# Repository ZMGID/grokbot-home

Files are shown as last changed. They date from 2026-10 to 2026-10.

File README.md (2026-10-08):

# grokbot-home

我的 Grok Bot「家」：换到新的 Grok Bot 账号时，让新号上的 bot 按这个仓库把自己和其他所有 bot 一起配好，做到基本无缝切换。

## 怎么用

仓库是**公开**的（2026-10-08 起），新号上的 bot 不用登录 GitHub 就能匿名克隆、读 `BOOTSTRAP.md`。Composio API key 只以**加密**形式放在 `secrets/*.enc`，解密口令只有我知道（应用连接只走 `composio-pg`，不装官方 GitHub/Origin 等连接器）。

在新号上打开任意一个 Grok Bot（一般是默认的主 bot），对它说：

```text
按这个仓库配置自己：https://github.com/ZMGID/grokbot-home
```

它会读 [`BOOTSTRAP.md`](BOOTSTRAP.md)，然后依次：

1. （Step 0）匿名克隆本仓库 → 用密码框（secret-request）向我要口令 `GROKBOT_HOME_PASSPHRASE` → 解密 `secrets/COMPOSIO_API_KEY.enc` 到 `~/.composio_pg_key`（连不上就换 `.box-current.enc`）→ 从 `connectors/composio-pg/` 装好并添加 composio-pg；
2. （Step 1）用 Composio 里 GitHub（ZMGID）的 token 登录 `gh`——只有往仓库推送（写回、每日同步）才需要；
3. 跑 `setup.sh` 装好工具环境（KiCad、PlatformIO、cadquery、Composio SDK 等）；
4. 确认 `composio-pg` 已接通；pstack 插件可选（原为 dr eggbot 安装）；导入 `skills/` 里的技能（若有）；
5. 按 `bots/grok-bot/` 设置自己为 **小萌**（主 bot；原名 Grok Bot）并读 `CONTEXT.md`；
6. 用 CreateAgent 把 `bots/` 下其他每个 bot（小枳、仓库管家、代码工程师、搭建运维、事务秘书、硬件工程师……，以 `bots/index.json` 为准）重新建出来，并重建它们的定时任务；
7. 自检，最后把新学到的东西写回仓库。

我需要亲自做的只有：在密码框里填一次仓库口令（解密失败时才要 Composio key 本身；`gh` 设备码只在推送权限拿不到时备用）。

## 目录

| 路径 | 内容 |
|---|---|
| `BOOTSTRAP.md` | 写给新 bot 的开机步骤（英文为主，附中文） |
| `CONTEXT.md` | 关于我的共享记忆：习惯、账号、项目进度、换号决定 |
| `bots/<名字>/` | 每个 bot 一个文件夹：`profile.md`（设定）、`CONTEXT.md`（它自己的记忆）、`routines.md`（定时任务） |
| `connectors/` | 连接器清单 + `composio-pg` 启动脚本（不含密钥） |
| `skills/` | 我自己创建的技能（目前没有） |
| `setup.sh` | 工具环境安装脚本（可重复运行） |
| `scripts/` | 每日同步任务说明和脚本、密钥扫描 `secret-scan.sh`、加解密 `secret-crypt.py` |
| `secrets/` | 只放加密后的密钥（`*.enc`），见 `secrets/README.md` |
| `projects/` | 项目文件（仿 TourBox 创作控制器） |

## 规矩

- **仓库是公开的，明文密钥永远不进仓库**。唯一例外是 `secrets/*.enc`：用 `scripts/secret-crypt.py` 加密后的 Composio key。口令只通过 bot 的密码框（secret prompt）给，绝不写进仓库或聊天。推送前必须 `bash scripts/secret-scan.sh` 通过。
- 每个号用完，新记住的东西写回对应的 `CONTEXT.md` 再推送。仓库管家每天凌晨 3:14（北京时间）自动同步一次。
- 仓库公开后，里面的共享记忆（`CONTEXT.md`、`bots/*/CONTEXT.md`、`bots/*/raw/memory/`）任何人都能看到；不要再写进不想公开的内容。不做 export-bot-template 分享模板。

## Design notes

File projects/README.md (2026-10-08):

# projects/

## creative-controller/ — 仿 TourBox 创作控制器（ESP32-S3）

从旧号 `/workspace/creative-controller/` 原样复制（2026-10-08），项目说明见 `creative-controller/README.md`、`docs/`。

包含：KiCad 9 工程和生成脚本（`pcb/`，含嘉立创生产文件 `pcb/fab/`）、cadquery 外壳模型与 STEP/STL（`mechanical/`）、可直接切片的 STL/3MF（`print/`）、
固件源码和编译好的合并固件 `firmware/bin/creativedial-esp32s3-merged.bin`（约 1 MB）、电脑端配置软件（`software/`）、文档（审查报告、3D 打印说明）。

**排除**（构建缓存，可重新生成）：
- `firmware/.pio/`（约 70 MB，PlatformIO 构建缓存；`cd firmware && pio run` 重新生成）
- 所有 `__pycache__/`

**没有超过 50 MB 的单个文件**，所以没用 Git LFS，也没有跳过任何文件。最大的是 `mechanical/out/assembly.step`（约 10 MB）和 `top_shell.step`（约 6 MB）。

**未放进仓库**：旧号的 `/workspace/creative-controller-delivery.zip`（约 15 MB），它是同一批文件的打包版，需要时可从本目录重新打包：
`cd projects && zip -r creative-controller-delivery.zip creative-controller -x '*/.pio/*' '*/__pycache__/*'`

依赖工具（`setup.sh` 会装）：KiCad 9（kicad-cli）、Freerouting（`/workspace/freerouting.jar`）、cadquery 2.8、PlatformIO（espressif32@6.9.0）、PrusaSlicer、Python 3。

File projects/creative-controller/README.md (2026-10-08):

# CreativeDial delivery package (Rev A1, 2026-10-08)
中文完整说明见 docs/README.md；设计审查报告（问题清单、修复、料号核验表、上电调试清单）见 **docs/审查报告.md**。

- Mechanical: mechanical/ (print-ready STL in print/)
- PCB (KiCad 9): pcb/ — regenerate with `cd pcb && ./route.sh && ./export.sh`; JLCPCB outputs in pcb/fab/
  (gerbers zip, BOM_JLCPCB.csv, CPL_JLCPCB.csv, BOM_detailed.csv with LCSC stock/price/Basic-Extended/links, ERC/DRC reports)
- Firmware: firmware/ (PlatformIO, Arduino-ESP32); prebuilt merged image firmware/bin/creativedial-esp32s3-merged.bin @0x0.
  Hardware self-test: hold TOP key while plugging in USB (or send `{"cmd":"selftest","on":true}`), watch serial at 115200.
- Config app: software/

Status: ERC 0 errors / DRC 0 errors (silkscreen warnings only), firmware builds cleanly. Not yet prototyped — see docs/审查报告.md §6 for remaining risks
(ENC2 mouse-encoder footprint is a placeholder; confirm CPL rotations in JLC preview; battery must have its own protection PCM).

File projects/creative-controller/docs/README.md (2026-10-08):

# CreativeDial 创意软件控制器 — 设计交付包 (Rev A, 原型阶段)

> 一款对标 TourBox 功能的**原创**桌面控制器：外形、布局细节、名称均为自主设计，未使用 TourBox 的外观/商标。
> 本包是 **"可以开始打样" 的工程原型包**，不是已经过验证的量产包。请务必阅读第 9 节"尚需实物验证的事项"。

## 1. 概述
| 项目 | 规格 |
|---|---|
| 外形 | 约 95 × 94 × 30 mm（含旋钮约 40 mm）。超椭圆(squircle n=4.2) 轮廓，四边带内凹"腰线"(前 5 / 后 2.5 / 左右 3 mm)；顶面 R300 球面拱，最高点偏后(y=+20)，前沿约 22.6 mm、后沿约 28.8 mm，形成后高前低的掌托斜面；R7 枕形上沿 + R5 底边，侧面呈柔和鼓包。键帽凸出 2.2 mm 带 R40 凹形指窝，旋钮滚花 + 嵌入式装饰环，滚轮约凸出 6 mm。粉色 PC/ABS |
| 主控 | **乐鑫 ESP32-S3-WROOM-1-N16R8**（LCSC C2913202） |
| 连接 | USB-C 有线（原生 USB HID 键盘 + 多媒体 + CDC 串口配置） + 蓝牙 BLE HID 无线 |
| 电池 | 3.7 V LiPo 603450 1000 mAh，MCP73831 充电 300 mA，P-MOS 电源路径(负载共享)，滑动电源开关，USB 插入检测；**电芯须自带保护板** |
| 输入 | 7 个面板按键(8 个轻触开关，长键用 2 个并联)、旋钮(EC11 带按压)、滚轮(鼠标编码器 + 按压)、共 9 路按键 + 2 路编码器 |
| 指示 | WS2812B RGB 状态灯(经 SN74LV1T34 电平转换) + 导光柱（充电=橙，充满=绿，BLE 已连=蓝，仅 USB=暗青，低电=灭） |
| 功能(默认 Photoshop 配置) | 橡皮擦、旋转画布、智能笔刷大小、不透明度、缩放画布、适合屏幕、撤销/重做、吸管、工具轮盘、移动画布(按住空格)、新建图层、画笔、单击/双击/长按、按住键+旋钮组合 |

**MCU 选型理由**：ESP32-S3 同时具备原生 USB-OTG (TinyUSB HID) 和 BLE 5，一颗模组实现有线+无线，模组自带天线/晶振/Flash 并已有 SRRC/CE/FCC 认证，可省去射频认证中最贵的部分。
RP2040 便宜约 2 美元但无无线；若只做有线版，可把 U1 换成 RP2040 方案（固件需移植，本包未提供）。

## 1.1 人体工学设计说明（左手操作）
| 控件 | 位置 (mm, 中心为原点) | 对应手指 / 理由 |
|---|---|---|
| 侧键(圆角豆形 18×13) | (-34,-20) 左下 | 左手自然放置时**拇指**落点；用于撤销/修饰键组合，最高频操作不需移动手掌 |
| 滚轮 Ø24 | (-38, 6) 左侧竖向 | **食指**向左外侧轻拨，与鼠标滚轮动作一致（缩放画布） |
| 顶部胶囊长键 34×13 | (-6, 31) | **食指/中指**向前伸即可按到；胶囊形对指腹宽度容错大（橡皮擦/平移） |
| 旋钮 Ø32 + Ø40 凹环 | (0, 2) 中央 | 位于食指-中指下方，手掌搭在前沿时可用两指捏转（笔刷大小/旋转画布），凹环防误触外壳 |
| 右上小圆键 ×2 Ø11 | (22,36) (38,25) | 中指/无名指上抬触达，用于不常用的吸管/画笔 |
| 右侧圆键 Ø11 | (36,-5) | 无名指（适合屏幕/新建图层） |
| 右下长键 12×22 / 12×18 | (18,-26) (36,-25) | **无名指/小指**下压，长条形适合"按住"类操作（按住空格平移、按住 Alt） |

- 所有按键中心距 ≥ 18 mm（最小值 18.0 mm：右下两长键；19.4 mm：右上两圆键），戴手套或指甲较长也不易误触。
- 后高前低约 6 mm 坡度 + 前沿内凹腰线：手掌根部可以搭在前沿，手腕伸展角更小。
- 键帽顶面为 R40 浅凹指窝、所有棱边 R1.2 倒圆；按键力 160 gf(TS-1102S)，行程约 0.3 mm 空行程 + 0.25 mm 开关行程（偏短，见第 9 节）。
- 底部 4 个 Ø10×0.8 mm 硅胶脚垫槽，防滑。
- 布局为原创：控件数量/功能与参考产品相当，但轮廓、按键形状和坐标均为独立设计。

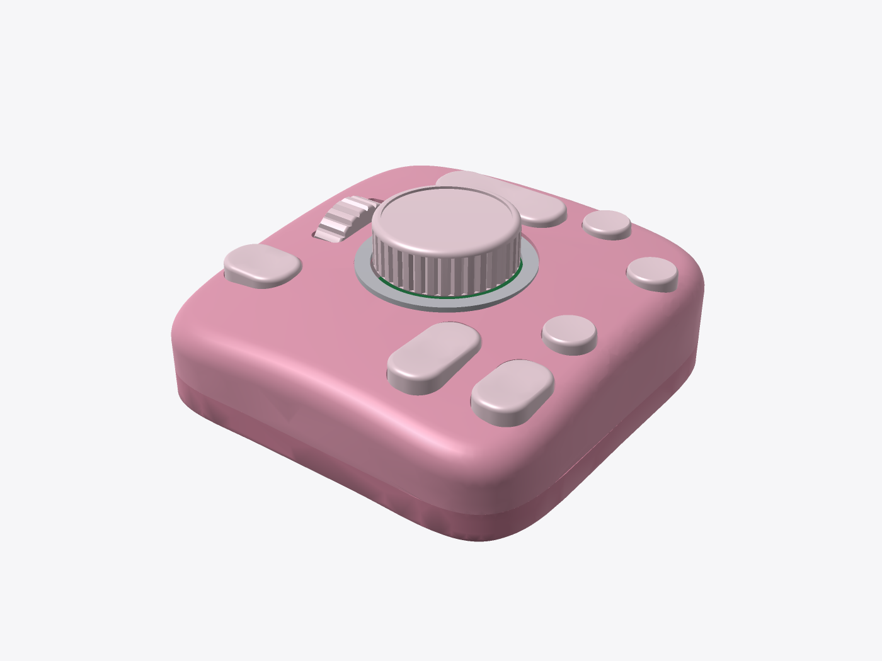
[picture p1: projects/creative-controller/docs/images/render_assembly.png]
总装渲染

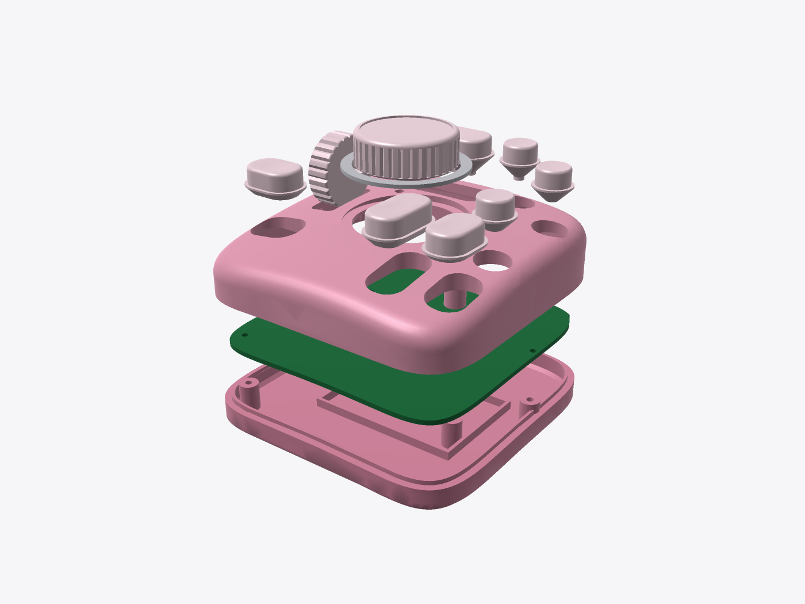
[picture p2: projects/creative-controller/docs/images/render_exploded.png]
爆炸图


## 2. 目录结构
```
mechanical/   CadQuery 参数化源码(params.py, cad.py, print_export.py)、out/*.step *.stl(装配姿态)、drawings/ 渲染与尺寸图
print/        FDM 打印就绪 STL(已按打印床摆放)、3MF 拼版、公差测试件、overhang_report.json
pcb/          KiCad 工程(.kicad_pro/.kicad_sch/.kicad_pcb)、生成脚本、fab/ 生产文件(Gerber zip、BOM、CPL、原理图 PDF、ERC/DRC 报告)
firmware/     PlatformIO 工程(Arduino-ESP32)、bin/ 已编译固件
software/     跨平台配置工具 creativedial_config.py (Python + Tkinter + pyserial)
docs/         本文档、3D打印说明.md、images/ 渲染图
```

## 3. BOM 与成本估算
详细见 `pcb/fab/BOM_detailed.csv`（含 LCSC 号、JLC 库存、Basic/Extended、单价、链接；JLC 上传格式为 `BOM_JLCPCB.csv`）。数据为 2026-10-08 由 JLC 元件库接口实时查询，核验表与说明见 **[审查报告.md](审查报告.md)**；下单前请再确认库存。

| 类别 | 主要器件 | 单台估算 |
|---|---|---|
| 电子元件 | ESP32-S3 模组 $5.1、EC11E $2.4、PCM12 $1.8、MCP73831、AP2112K、USBLC6、SN74LV1T34、USB-C、9+2 轻触开关、阻容（1+ 单价） | ≈ $12.3（100 台档约 $9） |
| PCB + SMT (JLC, 100 片) | 2 层 1.6 mm 93×93；SMT 单面；扩展件费每种 $3 一次性 | ≈ $2.5–4 |
| 鼠标编码器 + 微动、电池 603450 1000 mAh | 淘宝/1688 | ≈ $2.5 |
| 外壳 + 键帽 + 旋钮 + 滚轮 | 3D 打印(树脂) ¥40–70/套；注塑 ¥4–8/套 | 打样 ≈ $8 / 量产 ≈ $1 |
| 螺丝、脚垫、导光柱、包装 | | ≈ $0.8 |
| **合计** | | **打样(5–10 台) ≈ ¥200–300/台；量产(1k 台) ≈ ¥90–120/台(不含模具)** |
| 一次性费用 | 注塑模具(上下壳 + 键帽家族模 + 旋钮/滚轮) | ¥40k–90k，视模具钢和腔数 |
| 认证 | 使用已认证模组仍需整机 FCC/CE(SDoC/RED)、电池 UN38.3/MSDS | ¥15k–40k |

## 4. 生产步骤

### 4.1 PCB (嘉立创 JLCPCB)
1. 上传 `pcb/fab/creative-controller-gerbers-JLCPCB.zip`：2 层、1.6 mm、FR-4、1 oz、HASL 无铅或沉金；最小孔 0.3 mm、最小线宽/间距 0.127 mm，均为 JLC 标准工艺。
2. 勾选 SMT 贴片(顶面)，上传 `BOM_JLCPCB.csv` 与 `CPL_JLCPCB.csv`。
3. **在 JLC 贴片预览中逐个检查器件方向**：CPL 已对 SOT-23 系列、USB-C、JST 加 180° 修正，仍须按 审查报告.md §2.1 的清单逐个确认（尤其 ESP32 模组天线朝前沿）。
4. EC11 编码器(ENC1)、鼠标编码器(ENC2) 为插件，不在 CPL 中，到货后手焊（或额外勾选 JLC THT 服务）。
5. 电池接口 J2 为 JST PH 2.0，注意电池线序：**1 = +，2 = −**（不同电池厂线序不同，接错会烧充电芯片）。

### 4.2 外壳
- **FDM 自行打印（推荐打样）**：直接用 `print/` 下已摆好方向的 STL 或 `print/plate*.3mf`(仓库根目录 print/)，0.4 mm 喷嘴、PETG/PLA，详见 **[3D打印说明.md](3D打印说明.md)**（先打公差测试件！）。
- 外发打样：`mechanical/out/*.stl` 发 JLC3DP / 未来工场，9000R 树脂或 PA12(MJF) 也可用（树脂件热熔螺母孔需改为 Ø3.0 或用胶固定）。
- 量产：把 `*.step` 发模具厂做 DFM，按 `mechanical/README_mechanical.md` 加拔模角、优化螺柱壁厚、确定咬花/喷涂。

## 5. 组装指南
1. 检查 PCB：目检 + 万用表测 VBUS/VSYS/3V3/VBAT 对地不短路。
2. 手焊 ENC1 (EC11E, 20 mm D 轴) 和 ENC2 (鼠标编码器)；滚轮按压开关 SW9 位于滚轮下方。
3. 插 USB-C，不接电池，检查 3V3 = 3.3 V ± 3%，烧录固件（见第 6 节），然后按住 TOP 键上电进入**自检模式**逐键检查（完整清单见 审查报告.md §5）。
4. 上壳 4 个螺柱用烙铁压入 **M2×4×OD3.5 热熔铜螺母**（孔 Ø3.2×5，步骤见 3D打印说明.md）。
5. 将 7 个键帽从上壳**内侧**插入导向套（法兰朝内）；导光柱从内侧插入 LED 孔；拨动开关延长块套到 SW12 拨杆上。
6. 滚轮：方轴端插入鼠标编码器 ENC2 的方孔，另一端 Ø3×14 销轴落入上壳一体的滚轮支架 U 形槽（槽有 0.9 mm 下压行程，按下滚轮压 SW9）。
7. 把 PCB 扣入上壳（USB/开关舌片对准后壁开口，螺孔对准 H1–H4），电池用双面胶贴在下壳电池仓内，插 J2。
8. 合上下壳，4 颗 **M2×14 内六角(DIN912)** 从底部沉孔锁入热熔螺母（≤0.2 N·m）；贴 4 个 Ø10×0.8 硅胶脚垫。
9. 压上旋钮（打印 D 孔 Ø6.2/平面 4.7，带开口弹性槽，0.25 mm 间隙方案）及装饰环。

## 6. 固件与烧录
- 已编译固件：`firmware/bin/creativedial-esp32s3-merged.bin`（合并镜像，从 0x0 烧录）以及分立的 bootloader/partitions/app。
- 方法 A（推荐，无需环境）：
  ```
  pip install esptool
  # 按住 BOOT(SW11) 再按一下 RESET(SW10) 进入下载模式，插 USB-C
  esptool.py --chip esp32s3 --port COMx write_flash 0x0 creativedial-esp32s3-merged.bin
  ```
  也可用乐鑫 Flash Download Tool（Windows 图形界面），地址 0x0。
- 方法 B（源码编译）：`pip install platformio && cd firmware && pio run -t upload`
- 固件功能：9 路按键去抖(5 ms)、单击/双击(250 ms)/长按(450 ms)、`hold:` 按住型动作(如按住空格移动画布)、
  旋钮/滚轮中断正交解码、"按住某键 + 旋转" 组合、USB HID 键盘 + Consumer、BLE HID 键盘(设备名 CreativeDial)、
  JSON 配置存 NVS（掉电保存）、电池电压(16 次平均)/USB/充电状态查询、BLE 电量上报、电池供电无操作 10 分钟深度睡眠(任意键唤醒)、3.30 V 低压保护、
  **硬件自检模式**（按住 TOP 键上电或 `{"cmd":"selftest","on":true}`：不发 HID，串口打印每个按键/编码器事件和电源状态，LED 红绿蓝白测试）。
  USB 已连接时默认不再发 BLE 键（防重复），配置 `"ble_when_usb":true` 可开启；`"sleep_min"`、`"knob_steps"`、`"wheel_steps"` 可配置。
- 串口协议(115200, 每行一个 JSON)：`{"cmd":"hello"}`、`{"cmd":"get"}`、`{"cmd":"set","config":{"name":..,"map":{"top.single":"e",...}}}`、`{"cmd":"reset"}`、`{"cmd":"battery"}`、`{"cmd":"selftest","on":true|false}`、`{"cmd":"sleep"}`。

## 7. 配置软件
```
pip install pyserial          # Python 3.9+；Linux 另需 python3-tk
python software/creativedial_config.py              # 图形界面
python software/creativedial_config.py --push Krita # 命令行写入
python software/creativedial_config.py --selftest
```
内置 Photoshop / Clip Studio Paint / Krita / Procreate 类(iPad 蓝牙键盘快捷键) 4 套预设，可编辑并保存到 `~/.creativedial_profiles.json`。
动作语法：`ctrl+z`、`ctrl+shift+z`、`[`、`space`、`f5`、`hold:space`、`consumer:volup`；macOS 用 `cmd`。
**注意**：目前切换软件时需手动选择预设并"写入设备"；根据前台窗口自动切换尚未实现。

## 8. 测试检查表 (每台)
- [ ] 外观：无缩痕/毛刺，键帽无卡滞，旋钮无偏摆
- [ ] 上电：USB 插入 3V3 正常，电脑识别为 "CreativeDial" HID 键盘 + 串口
- [ ] `{"cmd":"hello"}` 返回固件版本
- [ ] 9 个按键逐一单击/双击/长按，配置工具或记事本中出现对应按键
- [ ] 旋钮顺/逆各转 1 圈 = 36 次(EC11E18244A5，36 止动)，无丢步/反向；滚轮同理
- [ ] 组合：按住侧键 + 旋钮 → R / Shift+R
- [ ] 蓝牙：手机/iPad/电脑可配对，断开后自动重新广播
- [ ] 充电：接电池 + USB，状态灯橙；`battery` 命令 mV 合理、charging=true；充满后灯绿、full=true
- [ ] 拔 USB，拨开关可由电池供电；开关 OFF 时电池电流 ≈0；深睡电流约 1 mA（WS2812B 静态电流，见审查报告 R3）
- [ ] 跌落 0.8 m ×6 面、按键寿命抽检 (TS-1102S 6×6×5.5 标称 10 万次)

## 9. 诚实说明：已验证 / 未验证
### 已在软件中验证
- CadQuery 模型可完整生成，STEP/STL 导出无误，渲染见 `docs/images/`（自写 numpy z-buffer 光栅渲染器，平滑着色，非照片级）。
- 原理图 ERC：0 错误 0 警告（`pcb/erc.rpt`）。
- PCB 由 Freerouting **自动布线**（Power 0.4 mm / VBUS 0.35 mm 网络类、两面 GND 铺铜 + 184 个缝合过孔、JLC 规则），100% 连通；DRC：0 错误，仅丝印类警告（`pcb/drc.rpt`），原理图-PCB 一致性检查通过。
- 2026-10-08 设计审查：修复 STAT 5 V 灌 GPIO、WS2812B 电平、0.2 mm 过孔等问题，全部料号经 JLC 接口核验，详见 **[审查报告.md](审查报告.md)**。
- 固件 PlatformIO 编译通过（ESP32-S3, Arduino-ESP32 2.x / platform espressif32 6.9.0）。
- 配置软件自检通过、图形界面在 Linux(Xvfb) 下可启动。
- 全部 26 个 LCSC 料号已通过 JLC 元件库接口核验存在、有货、封装匹配（ENC2 鼠标编码器除外，不在 LCSC）。

### 尚需实物打样/工程师复核（重要）
1. **PCB 为自动布线**：功能连通但未做人工美化；USB D+/D- 在 2 层 1.6 mm 板上无法做 90 Ω（需约 1.2 mm 线宽），按全速 USB 处理（见审查报告 P6）。
2. 原理图为脚本生成(每个引脚用网络标签连接)，可读性一般；电气已按规格书审查（审查报告 §1.1），电池需自带保护板。
3. WS2812B 数据电平问题已用 SN74LV1T34 修复；WS2812B-B/T(C2761795) JLC 库存 8 万+，未见停产标记。电池 <3.5 V 时 LED 低于规格，固件 3.45 V 以下关灯。
4. 滚轮机构已建模（上壳一体支架 + U 形槽 + Ø3 销轴 + 方轴插编码器），但"以编码器轴为支点下压"的方式依赖编码器能承受轻微摆动，需实测；ENC2 使用自建"通用鼠标编码器"封装，须按实际采购型号核对引脚和孔位/轴高。
5. 6×6×5.5 mm 轻触开关(CAX TS-1102S, C53431191，已核验，焊盘与 PTS645 封装一致；库存仅约 1000，批量需锁料)，键帽导向更稳但行程仍约 0.25 mm；更长行程需换 Kailh Choc 矮轴（需改 PCB 封装与键帽结构，本版未实现）。
   机械与 PCB 的高度配合(键帽柱长、编码器轴长、USB-C 开口高度、拨动开关槽)只按数据手册典型尺寸计算，**需首版打印实测**。
6. 注塑模型未加拔模角，螺柱/壁厚未做模流分析。
7. ESP32 天线区域：模组天线朝前沿，PCB 已做禁铜区，但电池、手部遮挡对 BLE 距离的影响需实测。
8. 固件未在真机运行：HID 报告、BLE 配对(iOS/Windows/macOS 兼容性)、深度睡眠唤醒均需实测（自检模式便于调试）。
9. JLC CPL 旋转角已按常用修正表处理，但须在 JLC 预览中确认；KiCad 工程为 **KiCad 9.0** 格式(本环境仅有 KiCad 9；KiCad 8 无法打开 9 的 PCB 文件，原理图使用 8 兼容格式)。
10. 主按键封装 SW_SPST_PTS645 已按 TS-1102S 规格书核对；RESET/BOOT 为 TL3342 封装 + TS-1187A(C318884)，焊盘已核对。
11. 料号价格随时变化；EC11E18244A5、ESP32-S3 模组属"扩展库"器件，JLC 每种收取换料费。

12. USB-C：PCB 加了伸出舌片使插座端面贴近内壁，后壁外侧做 13×7.5 mm 沉台、仅剩 0.8 mm 壁，端面距沉台面 ≤1 mm，常见粗头线应能插到底；需实物确认。
13. 电源拨动开关：后壁开 6.5×3.6 槽 + 11×6 指槽，并提供打印拨杆延长块 `pwr_slider_ext`（1.5×1.6 套孔），尺寸按开关典型规格书，需实测。
14. FDM 打印：外表面无 >45° 悬垂；上壳倒扣打印时内部穹顶天花板/导向套/螺柱需"仅支撑在打印床"或树状支撑（不可见面）。打印时间/耗材为 PrusaSlicer 2.x 通用 PETG 配置估算，未实打。

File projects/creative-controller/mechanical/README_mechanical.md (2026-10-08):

# 机械结构说明 (mechanical)

源文件: `params.py`(唯一尺寸来源，PCB 生成脚本也引用它) + `cad.py`(CadQuery) + `render.py`(渲染/尺寸图)。
重新生成: `pip install cadquery trimesh matplotlib && python3 cad.py && python3 render.py`

## 零件清单 (out/)
| 文件 | 零件 | 数量 | 推荐材料 |
|---|---|---|---|
| top_shell.step/.stl | 上壳 | 1 | PC/ABS (注塑) / 光敏树脂 或 PETG (打印) |
| bottom_shell.step/.stl | 下壳(含电池仓围框、4 个脚垫槽 Ø10) | 1 | 同上 |
| cap_top / cap_side / cap_tr1 / cap_tr2 / cap_br / cap_tall1 / cap_tall2 | 按键帽(带法兰防脱，从壳内侧装入) | 7 | ABS/PC, 打印可用树脂 |
| knob.step | 旋钮 Ø32×11，滚花，D 形孔(6 mm 轴, 4.5 mm 平面) | 1 | ABS + 可选铝套 |
| knob_ring.step | 装饰环 Ø40 | 1 | 透明 PC(可做导光) / 金属 |
| scroll_wheel.step | 滚轮 Ø24×8，2.05 mm 方孔接鼠标编码器轴 | 1 | ABS + TPU 包胶(量产) |
| light_pipe.step | 状态灯导光柱 Ø2.9 | 1 | 透明 PC/PMMA |
| assembly.step | 总装(含 PCB 占位) | - | - |

## 关键尺寸
- 外形约 95 × 94 × 30 mm（含旋钮 ≈ 40 mm），超椭圆轮廓 + 四边内凹腰线(params.WAIST)，顶面 R300 球面拱顶(顶点偏后 20 mm，前低后高)，上沿 R7 枕形过渡，底边 R3，壁厚 2.2 mm。
- 键帽顶面高出局部拱面 2.2 mm，顶面带 R40 浅凹指窝；法兰在壳内皮下 0.4 mm 作为行程止挡。
- 分模面 z = 8 mm；下壳 1.5 mm 高止口(单边 0.15 mm 间隙)插入上壳。
- PCB：外壳轮廓向内偏移 3.2 mm（与外壳同源 outline_pts），, 1.6 mm，底面位于 z = 13 mm，被上壳螺柱(压)和下壳螺柱(托)夹紧。
- 4 × M2×14 DIN912 内六角从下壳底部沉孔(Ø4.4×2.4, 通孔 Ø2.4) → PCB 孔(Ø2.2) → 上壳螺柱内 M2×4×OD3.5 热熔铜螺母(孔 Ø3.2×5, 螺柱 Ø6.6)。
- FDM 打印细节、方向、支撑见 ../docs/3D打印说明.md 与 ../print/；按键为 6×6×5.5 轻触(TS-1102S)，带导向套；USB 外侧沉台 13×7.5 剩 0.8 mm 壁；拨动开关槽 + 指槽 + 延长块；滚轮支架与上壳一体(U 形槽, Ø3×14 销)。
  位置 (-40,24) (-38,-34) (42,12) (28,-12)。上壳螺柱已裁切到内腔面，不会顶穿拱顶。
- 按键帽与壳孔单边间隙 0.25 mm（FDM 建议 0.3，注塑 0.10–0.15）；帽高出壳面 1.2 mm；
  帽柱底面与轻触开关(TS-1187A, 1.5 mm 高)之间预留 0.3 mm 空行程。
- USB-C 开口 10.0 × 4.0 mm 位于后壁中央；电源拨动开关槽 8 × 3 mm 位于后壁 x = 33。
- 电池仓 50.6 × 34.6 mm（603450 1000 mAh LiPo），围框高 3 mm。

## 3D 打印建议
- 光敏树脂(JLC3DP 9000R/8228)外观最好；FDM 用 0.2 mm 层高、PETG，上壳顶面朝下打印需支撑。
- 打印件的自攻底孔可能需要用 1.6 mm 钻头修孔；或改用热熔铜螺母(M2 OD3.2)，把 `cad.py` 中 pilot 改为 Ø3.2。

## 注塑量产注意 (需模具厂 DFM 评审)
- 当前模型 **未加拔模角**：外观面需 1–2°、内部筋/柱 0.5–1° 拔模；纹理面按咬花深度加大拔模。
- 螺柱根部壁厚偏厚(实心 Ø6.4)，量产建议改为 Ø5.5 外径 + 加强筋，并在柱根做掏胶，防缩痕。
- 按键帽建议改为 "整片硅胶/硬胶二次成型" 或带悬臂弹片的一体按键，减少零件数。
- 上壳顶面按键孔间距最小处约 3 mm，模具强度 OK；侧壁 USB/开关槽需要滑块(或改为下壳开槽)。
- 推荐 PC/ABS (如 Covestro Bayblend) 或 ABS + 喷涂/IMD 实现粉色哑光外观。

渲染: `python3 render_final.py`（raster.py 为纯 numpy 软件光栅器，无需 GPU）。

布尔运算使用模糊容差 + ShapeFix (fcut/funion)，因为样条轮廓与球面求交易产生公差问题；所有导出零件均通过 isValid 检查。

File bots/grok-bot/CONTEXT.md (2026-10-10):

# 小萌（grok-bot）自己的记忆与项目状态

> 先读根目录 `/CONTEXT.md`（关于用户的共享记忆），这里只记主 bot 自己的工作记录。导出：2026-10-08。

## 职责
- 账号主 bot / **经理**：接任何任务并分派给合适的 bot；用 CreateAgent 创建新 bot（dr eggbot 已于 2026-10-08 删除）；SetPrimaryBot。
- 换号时执行 BOOTSTRAP；仓库日常维护与每日 03:14 同步已于 2026-10-08 移交给**仓库管家**。

- (2026-10-08) 用户批准把 `/workspace/assistant/big-picture.md` 公开进仓库：`bots/grok-bot/notes/big-picture.md`。每日笔记 `/workspace/assistant/daily/` **不进仓库**；每日同步由仓库管家复制 big-picture（见 `scripts/sync.md`）。
- (2026-10-08) **改名**：显示名 `Grok Bot` → `小萌`（slug 仍为 `grok-bot`）。
- (2026-10-08) 定时任务「巡检各 bot」`17 11,15 * * 1-5`；早晚计划/总结**已移交给事务秘书**。
- (2026-10-09) 「巡检各 bot」改用纯 cron `17 11,15 * * 1-5`（用户时区 Asia/Hong_Kong）；小萌现仅保留此项定时任务。

## 关于用户（主 bot 视角的要点）
- 用中文交流，Grok Bot 账号多个、轮换使用，GitHub `ZMGID`。
- 2026-10-07 用户问订阅：建议先订 SuperGrok（$30/月，按月付），Grok Bot 从这一档开始提供；Plus（$100）主要多用量、1080p 视频、高峰优先。
- 用户会在语音通话里布置任务；通话结束后要在聊天里补发结果摘要。
- 用户发 `/new` 时：主 bot 不能替用户开新对话，告诉他用 app 里的新建入口，或直接换话题。

## 项目记录

### kivio PR #60 审查（2026-10-07）
- PR #60「feat: Kivio Study 材料学习工作台」：最新一轮 CI 和 Study browser regression 在 10-07 通过（`be06640` 修好了共用 Chat 重构引入的两处 bug：读历史时改写记录、打开页面就更新版本号导致其他窗口被误判过期）。没有冲突，可合并，没人 review。review 意见见根目录 CONTEXT.md。
- Dsivio main CI 一直失败：CI 用 Node 20，测试用 `Promise.withResolvers`（Node 22）。

### 仿 TourBox 创作控制器（2026-10-07 ~ 10-08）
- 用户发了一张 TourBox 类产品图，要求做全套（模型、PCB、软件）并给交付文件。主 bot 做了原创设计：
  1. 初版（100×100×30 mm）→ 用户要求按 **3D 打印** 重做并兼顾 **人体工学**（参考原图）→ 人体工学版（约 95×94 mm，左手布局，键距 ≥18 mm）→ 3D 打印版（17 零件、3MF 打印盘、热熔螺母、滚轮支架、公差测试件、中文打印说明）。
  2. 用户要求审查电路板和固件并在嘉立创核对元件 → 修了充电芯片状态脚 5V 直连 ESP32（加分压）、RGB 数据电平偏低（加电平转换），充电电流降到 303 mA，编码器加上拉和滤波，天线禁铺区加大，双面铺地；固件升到 **v1.1.0**（修蓝牙配对、USB 重复发键，加 10 分钟休眠和自检模式）。
- 当前文件：`projects/creative-controller/`（旧号 `/workspace/creative-controller/`，另有打包的 `creative-controller-delivery.zip` 约 15 MB，内容与目录相同，未放进仓库）。
- 剩余风险：ENC2 封装占位、板上无电池保护（用带保护板的 603450）、检查 CPL 旋转、TS-1102S 库存少、未经实物测试。
- 工具链：KiCad 9（kicad-cli）、Freerouting（`/workspace/freerouting.jar`，`pcb/route.sh`）、cadquery 2.8（`mechanical/cad.py`、`params.py`）、PlatformIO espressif32@6.9.0（`firmware/`）、PrusaSlicer（切片估时）。

### 换号方案（2026-10-08）
- 讨论过程：私有仓库 + CONTEXT.md → 工具环境用 setup.sh、密钥放 1Password → 用户希望“给新 bot 一个链接就自动适配” → 考虑过自建 MCP 网关（MetaMCP / mcp-proxy），后来选 Composio（免费 Hobby 版每月 10 万次调用，个人够用）。
- 官方 Composio 插件 OAuth 后看不到应用（不同 Composio user）；小枳用项目 API key 写了 `composio-pg` 启动器，主 bot 在 11:54 把 `composio-pg` 加到账号里并验证 GitHub（ZMGID）和 Gmail 都是 ACTIVE。
- (2026-10-09) 新增 **composio-zhimeng**（stdio，`/workspace/composio-zhimeng/launch.sh`）：Composio 用户 `zhimeng63`，仅 Gmail zhimeng63@gmail.com；与 composio-pg 共用 `~/.composio_pg_key`。composio-pg 此后只管 GitHub + ohulercxm8。
- 用户决定：每个 bot 都存进仓库，新号的第一个 bot 配好自己后用 CreateAgent 重建其他 bot。
- 2026-10-08 12:02 开始建 `ZMGID/grokbot-home`。
- (2026-10-08) 用户改口：单独建同步 bot **仓库管家**，仓库维护与每日同步从主 bot 移交给它；grok-bot 不再跑 daily-grokbot-sync。

## 账号上的其他 bot（供分派参考，2026-10-08）
- **小枳**（xiaozhi）：中文通用助手，调研/查资料/方案。
- **仓库管家**：维护本仓库、跑每日 03:14 同步。
- **代码工程师**：Dsivio / kivio 的 CI、PR 与代码修复。
- **搭建运维**：公司官网、飞书及其他搭建维护。
- **事务秘书**（原名「邮件秘书」）：非技术事务 + 工作日早晚计划/总结；只写草稿，从不直接发送。
- **硬件工程师**：创作控制器（`projects/creative-controller/`）。
- **财务管家**：记账/订阅/预算/报销对账（只记录不付款）；账本 `/workspace/finance/` 不进仓库。
- **dr eggbot**：已于 2026-10-08 删除；新建 bot 改由本 bot（小萌）负责。
- 另有一个空的 “New Bot”（id `1dbfda76-…`，2026-08 创建，无对话、无设定），不是真正在用的 bot，没有迁移。
- (2026-10-10) 又出现第二个空白 “New Bot”（id `52d1b935-…`，10-10 03:09 创建，只发了一句自我介绍，无设定），同样暂不登记，等用户或小萌确认用途。

## 2026-10-08 晚 ~ 10-09
- (2026-10-08) Dsivio v1.1.0 发布；官网产品页上线；环境配置 PR #2/#3/#4 开出未合；用户次日重点：手工优化环境配置 + 启动 IM Gateway（参考 Hermes）。
- (2026-10-08) 派小枳做 Hermes IM 网关调研；用户 10/9 凌晨决定自写 Rust 协议实现。

## 2026-10-09 午后 ~ 10-10 凌晨
- (2026-10-09) 帮用户查了 Codex CLI 0.160–0.162 更新、GPT-6.1 Sol 与 Claude Opus 5.5 API 价格对比、AI 操作 Word/Excel 的开源项目（首推 OfficeCLI，备选 officekit）。
- (2026-10-10) 应用户要求做了恶搞网页小游戏《刹不住的境界》（虚构车名/厂名），用户最终选第一版；已挂到新的公开仓库 **ZMGID/brake-game**（GitHub Pages：https://zmgid.github.io/brake-game/），只记一笔、不同步进本仓库。素材整理在 box 的 `/workspace/brake-game/`。
- (2026-10-10) 领取 Grok Bot 邮箱 `cloudpotato@mail.grokbot.com`（绑当前账号、不可转移，见根目录 CONTEXT「Grok Bot 自带邮箱」），并新建自动任务「cloudpotato 来信提醒」。
- (2026-10-10) 用户想在 Composio 里再接其他邮箱：规矩是每个邮箱单独建一个 Composio 连接器（同 composio-zhimeng 模式），等用户给地址。

- (2026-10-10) 新增例程：**cloudpotato 来信提醒**（email 触发）与 **gmail-new-mail**（webhook；触发器 ti_ePC_aV3eRSPT / ti_6ozhOAfOaHLq；密钥 env `GMAIL_WEBHOOK_KEY` 不进仓库）。盒子 `/workspace/gmail-listener/start.sh`，重启后需手动启动。
- (2026-10-10) 飞书走官方 **lark-cli**（Composio 无飞书例外）；群 id 见 `services/feishu-cli/chats.md`。

## 2026-10-10 晚
- (2026-10-10) 帮用户看了 Monid（统一付费的工具/数据接口平台），结论：可借鉴思路，不必自建；记入 `/workspace/assistant/ideas/monid-unified-api.md`，等 Dsivio 环境配置忙完再拿出来商量。
- (2026-10-10) 接下用户三条主线（kivio bot 模式 + 版本检查、kivio Rust SDK 标准、Dsivio 运营插件），小萌要先摸清 kivio / Dsivio 代码结构再出拆解和计划；插件线建议让事务秘书问运营同事日常，或用户直接口述。
- (2026-10-11) 两个空白 “New Bot”（`1dbfda76-…`、`52d1b935-…`）已不在本账号的 agent 目录中（应已删除，从未登记，无需清理）。又出现一个默认设定的空白 “Grok Bot”（id `04d9635a-…`，10-10 17:22 创建，只有自我介绍和一问一答，无分工），同样暂不登记，等用户或小萌确认用途。

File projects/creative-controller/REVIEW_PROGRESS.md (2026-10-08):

# Review progress (auto notes)
## Done (as of 02:00)
- design.py: +U5 SN74LV1T34DBVR level shifter (LED_IO GPIO48 -> LED_DIN @VSYS), C10; MCP73831 STAT (pushes 5V!) now via 15k/22k divider (R7/R10) to GPIO2;
  VBUS_SENSE 22k/39k (R11/R12) -> GPIO13 (module pin 21); ENC pullups 10k + 10nF (R13-16, C11-14); C15 22uF 0805 on 3V3.
- gen_pcb.py: antenna keepout widened to x±20 (all Cu), module EP vias 0.2->0.3 drill (JLC 2L min), small silk refs 0.8mm.
- tools/patch_pro.py: JLC rules + netclasses Power/USB (run after every SaveBoard). import_route.py: GND pours + stitching vias (168).
- tools/jlc_lookup.py: JLC parts API lookup. All original 20 LCSC codes verified in stock (see make_bom_cpl output / fab/jlc_parts.json).
- make_bom_cpl.py rewritten (live JLC data, BOM_detailed.csv, CPL rotation corrections).
- firmware main.cpp: v1.1.0 VBUS sense, charge logic, battery avg/pct, BLE security order, robust encoder ISR (rest-state), deep sleep ext1, self-test mode. Builds OK.
## Remaining
- Reroute: last freerouting run (-mp 60) left VBUS (USB-C pads) and VBAT (J2) unrouted and froze the box -> rerun with -Xmx3g, power width 0.4/VBUS 0.35.
- DRC 0 errors, export.sh, BOM/CPL, docs/审查报告.md, README, bins, zip.
- 02:06 reroute OK: 0 unconnected, DRC 14 (check)
- 02:15 R6->3.3k (303mA), BOM regrouped, fw low-batt cutoff + USB/BLE dedupe, bins rebuilt. DRC 0 err. Next: docs
- 02:2x exports regenerated; writing docs/审查报告.md
- docs/审查报告.md written
- README/docs updated; next: zip
- 02:2x zip rebuilt. ALL DONE

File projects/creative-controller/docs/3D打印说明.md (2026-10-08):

# 3D 打印说明（FDM，0.4 mm 喷嘴，PETG / PLA）

所有打印文件位于仓库根目录 `print/`，**已按推荐方向摆放在打印床上（Z=0 即床面）**，直接导入切片软件即可，无需旋转。
源码：`mechanical/print_export.py`（由 `mechanical/cad.py` 生成的零件重新定向、修复网格、做悬垂检查、生成 3MF）。

| 文件 | 说明 |
|---|---|
| `plate0_tolerance_test.3mf` | 公差测试拼版（**第一个打印**） |
| `plate1_shells.3mf` | 上壳 + 下壳（如果 220×220 床放不下两件，请分两次打印） |
| `plate2_controls.3mf` | 7 个键帽、旋钮、装饰环、滚轮、导光柱、拨杆延长块、销轴 |
| `*.stl` | 每个零件单独的 STL（同方向） |
| `overhang_report.json` | 悬垂/桥接面积自检结果 |

## 1. 材料与通用参数
- **推荐 PETG**（韧、耐 70 °C、热熔螺母压入后不易开裂）；PLA 可用于打样，但夏季车内/阳光下会变形。
- 导光柱：透明/半透明 PETG（`light_pipe_clearPETG.stl`）。
- 喷嘴 0.4 mm；线宽 0.42–0.45 mm。
- 层高：外壳 0.2 mm（想要更顺滑的穹顶可用 0.16 mm 或可变层高）；键帽/旋钮/滚轮 0.12–0.16 mm。
- 墙：3 圈（≈1.3 mm），设计壁厚 2.2 mm，所以壳体侧壁基本为实心；顶/底层各 5 层。
- 填充：外壳 20% 螺旋/gyroid；键帽、旋钮、滚轮、延长块、销轴 100%（或 6 圈墙）。
- 温度（参考）：PETG 235–245 °C / 床 75–85 °C；PLA 205–215 °C / 床 60 °C。
- 首层：外壳底部外缘有 1.6 mm 45° 倒角，可消除象脚；**不要开边缘 brim 覆盖倒角**（会糊住），必要时用 3 mm brim 只在下壳。

## 2. 各零件摆放与支撑
| 零件 | 摆放方向 | 支撑 | 0.2 mm 层高估算时间 | 耗材(PETG) |
|---|---|---|---|---|
| top_shell 上壳 | 开口朝下、穹顶朝上 | **需要**：内部穹顶天花板、键帽导向套、螺柱、滚轮支架下表面需支撑；用"树状/有机支撑"，悬垂阈值 44°，**外表面无需支撑**（全部 <45°） | ≈ 4 h 53 min | ≈ 15.3 m / 47 g |
| bottom_shell 下壳 | 外底面贴床 | 可不加或"仅从打印床"支撑；沉头孔与脚垫凹槽为短桥接（≤10 mm），外缘倒角 42–45° | ≈ 2 h 22 min | ≈ 8.4 m / 26 g |
| 7 个键帽 | 顶面朝上（直立），法兰贴床 | 无（法兰 45° 倒角 + 45° 锥形过渡到柱） | 共 ≈ 1 h 05 min | ≈ 3.3 m / 10 g |
| knob 旋钮 | 顶面朝上 | 无；D 孔顶部为 Ø6 短桥接 | ≈ 28 min | ≈ 1.7 m / 5 g |
| knob_ring 装饰环 | 平放 | 无 | ≈ 3 min | 0.6 g |
| scroll_wheel 滚轮 | 侧面平放（轴线竖直） | 无；方轴孔/销孔竖直打印，尺寸最准 | ≈ 14 min | ≈ 2.4 g |
| light_pipe 导光柱 | 法兰朝下 | 无 | ≈ 3 min | 0.2 g |
| pwr_slider_ext 拨杆延长块 | 套孔朝下 | 无（1.5 mm 短桥接） | ≈ 1 min | <0.1 g |
| wheel_pin_optional 销轴 Ø3×14 | 竖直 | 无（建议直接用 Ø3×14 钢销/不锈钢定位销代替） | ≈ 1 min | <0.1 g |
| 公差测试件(板 + 销) | 平放 | 无 | ≈ 1 h 44 min | ≈ 14 g |

整机一套（不含测试件）约 **8.5 小时、≈ 90 g PETG**。时间/耗材为 PrusaSlicer CLI（0.2 mm、3 圈墙、20% 填充、壳体加支撑）估算，换机器/配置会有 ±30% 偏差。
自检（`overhang_report.json`）：除上壳内腔外，所有零件"比 45° 更平的朝下斜面"面积为 0（允许 2° 网格误差），水平朝下面只有短桥接。

## 3. 关键配合尺寸（FDM 补偿已含在模型内）
| 位置 | 设计值 |
|---|---|
| 键帽与壳孔、导向套 | 单边间隙 0.25 mm；导向套长 1.5 mm 保证键帽不歪 |
| 旋钮 D 孔 | Ø6.2 / 平面距 4.7（EC11 D 轴 Ø6 / 4.5），入口 0.5 mm 倒角 + 开口弹性槽，压入即紧 |
| 滚轮 | 方孔 1.95 mm（鼠标编码器 2.0 mm 方轴，微过盈），销孔 Ø2.95×5.5（Ø3 销压入）；滚轮与壳槽间隙 ≥0.6 mm |
| 滚轮支架 U 形槽 | 宽 3.3 mm（Ø3 销 + 0.3），顶部为 teardrop 顶，0.9 mm 下压行程触发 SW9 |
| 水平孔 | 全部为 teardrop（水滴）形或 45° 屋顶，无需支撑 |
| 热熔螺母孔 | Ø3.2 × 深 5 mm，入口 0.4 mm 倒角，螺柱外径 6.6 mm |
| USB-C 开口 | 9.8×4.0 通孔 + 外侧 13×7.5 mm 沉台（剩 0.8 mm 壁） |
| 拨动开关 | 6.5×3.6 槽 + 11×6 指槽 + 拨杆延长块 |

**先打公差测试件**：测试板上有 0.15/0.20/0.25/0.30 mm 间隙孔+配套销、D 轴孔、Ø3.0–3.3 热熔孔、teardrop 水平孔、2.0/2.05/2.1 方孔。
找出"能顺滑滑动但不晃"的间隙，若不是 0.25，修改 `mechanical/params.py` 中 `FDM_CLR`，然后运行
`cd mechanical && python3 cad.py && python3 print_export.py` 重新生成全部 STL/3MF。

## 4. 后处理
1. 拆支撑（上壳内腔），用斜口钳/刮刀清理导向套内壁和螺柱顶端，不要扩大导向套内径。
2. 键帽导向面、滚轮侧面可用 400–800 目砂纸轻磨；外壳可用 240→600 目砂纸 + 喷底漆/哑光漆，或热风枪极短时间扫一下去拉丝（PETG）。
3. 用 Ø3.2 钻头手转修一下热熔孔（只修毛刺），用 Ø2.4 钻头修下壳通孔。
4. 检查所有键帽能在孔中自由落下且不晃。

## 5. 热熔螺母安装
- 规格：**M2 × L4 × OD3.5 黄铜滚花热熔螺母**（4 个，淘宝/1688 "M2×4×3.5 热熔铜螺母"）。M3 版本不适用（螺柱太细）。
- 螺丝：**M2×14 DIN912 内六角**（4 颗，从下壳底部沉孔 Ø4.4×2.4 进入）。
- 方法：烙铁装热熔头（或普通尖头），PETG 230 °C / PLA 200 °C；螺母放在孔口，垂直轻压 3–5 s 至与螺柱顶面平齐或低 0.1 mm，立即用平面金属块压平 5 s 冷却定型。
- 不要过热、过压，否则塑料会从孔底挤出或螺母歪斜；歪了趁热用 M2 螺丝拧入校正。

## 6. 装配顺序
1. 打印公差件 → 校准 `FDM_CLR` → 打印全部零件。
2. 上壳压入 4 个热熔螺母。
3. 上壳倒扣：7 个键帽从内侧插入导向套；导光柱从内侧插入 LED 孔（可点一滴 UV 胶）。
4. 滚轮：Ø3 销压入滚轮销孔（或钢销），方孔套到 PCB 上 ENC2 编码器方轴。
5. PCB 预装拨杆延长块到 SW12；将 PCB 连滚轮一起放入上壳：USB/开关舌片对准后壁、销轴端落入滚轮支架 U 形槽、EC11 轴穿过旋钮孔。
6. 插电池线 J2，电池用双面胶粘在下壳电池仓。
7. 合下壳，4 颗 M2×14 拧入（≤0.2 N·m，不要拧死）。
8. 压入旋钮、装饰环，贴 4 个 Ø10×0.8 mm 硅胶脚垫。
9. 按 README 第 8 节测试：每个键帽按下有清脆触感、松开回弹不卡；滚轮转动顺滑、下压能触发；USB 线插到底。

## 7. 已知限制
- 打印时间/耗材是切片估算，未实际打印；配合尺寸需以公差测试件为准。
- 上壳需要内部支撑（不可见），支撑接触面会粗糙，但不影响装配面。
- 下壳 STL 有个别网格边不闭合（切片软件会自动修复）。
- 滚轮"以编码器轴为支点"的下压方式需实测编码器寿命。

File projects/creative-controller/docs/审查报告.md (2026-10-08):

# CreativeDial 主板设计审查报告（Rev A → Rev A1）

审查日期：2026-10-08（北京时间）  审查范围：`pcb/`（design.py / gen_sch.py / gen_pcb.py / import_route.py / make_bom_cpl.py）、`firmware/`、`pcb/fab/` 生产文件。
审查方式：逐项对照 ESP32-S3-WROOM-1 / MCP73831 / AP2112K / USBLC6-2SC6 / WS2812B / TS-1102S / TS-1187A / EC11E 规格书与乐鑫硬件设计指南；
料号通过 JLCPCB 元件库公开接口（`pcb/tools/jlc_lookup.py`）实时查询，并与 LCSC 商品详情接口交叉核对。

> 结论：发现 **3 个会导致首版失败或损坏器件的严重问题**（充电芯片 STAT 5 V 直灌 GPIO、WS2812B 3.3 V 数据电平不足、2 层板 0.2 mm 过孔超出 JLC 工艺）以及若干中等问题，均已在生成脚本中修复并重新生成原理图/PCB/Gerber/BOM/CPL/固件。
> ERC 0 错误 0 警告；DRC **0 错误**、0 未连接、原理图-PCB 一致性 0 问题（剩余 14 条均为丝印/库差异类 *警告*）。固件编译通过。

---

## 1. 问题清单与修复

严重度：🔴 严重（首版不能用/损坏）  🟠 中（可能不稳定/不满足规范）  🟢 低（改进）

### 1.1 原理图 / 电气

| # | 严重度 | 问题 | 依据 | 修复 |
|---|---|---|---|---|
| E1 | 🔴 | **MCP73831 STAT 脚直接接 GPIO2 并上拉到 3V3**。STAT 是三态推挽：充满时输出 **高电平 = VDD(5 V)**，5 V 直接灌入 ESP32-S3 GPIO（绝对最大 VDD+0.3 V）。 | MCP73831 DS 表 5-1 STAT 输出 VOH≈VDD | STAT → R7 15 kΩ → GPIO2，GPIO2 → R10 22 kΩ → GND；高电平 5.25 V 时 GPIO 仅 3.12 V，低电平 0 V。去掉 3V3 上拉（也消除了 3V3 经 STAT 反灌 VDD 的路径）。 |
| E2 | 🔴 | **WS2812B 由 VSYS(USB 时≈4.7 V) 供电，数据却是 3.3 V**：WS2812B VIH = 0.7×VDD = 3.3 V，处于临界，首版极可能乱色/不亮。 | WS2812B DS VIH=0.7VDD | 新增 **U5 SN74LV1T34DBVR**（单电源电平转换缓冲器，VCC=VSYS，输入 VIH≈1.35 V，输出为 VSYS 电平）+ C10 100 nF；GPIO48 → U5 → LED_DIN。WS2812B 本身保留（JLC 库存 8 万+）。 |
| E3 | 🟠 | 充电电流 500 mA（R6=2 kΩ）：系统 ~100 mA + 充电 500 mA 超出 USB2.0 默认 500 mA；SOT-23-5 耗散 (5−3.7)×0.5≈0.65 W，会频繁进入热调节。 | MCP73831 DS θJA≈230 °C/W | R6 改 **3.3 kΩ（C25890, Basic）→ 303 mA**，1000 mAh 电池约 3.5–4 h 充满。 |
| E4 | 🟠 | 无 USB 插入检测，固件无法区分"在充电 / 无 USB"，也无法决定是否允许休眠。 | — | 新增 VBUS_SENSE：R11 22 kΩ / R12 39 kΩ → **GPIO13（模组 pin 21）**，5 V→3.2 V，4.4 V→2.8 V（>VIH 2.48 V）。 |
| E5 | 🟠 | EC11 / 鼠标编码器仅靠内部 ~45 kΩ 上拉，无 RC，长线+触点抖动易误计数。 | 题述要求/Alps 推荐 RC | 每路 A/B 加 **10 kΩ 上拉 + 10 nF**（R13–R16, C11–C14），τ=100 µs；按键沿用内部上拉 + 软件去抖。 |
| E6 | 🟠 | 3V3 只有 10 µF+100 nF。乐鑫建议模组 3V3 入口 ≥22 µF（RF 发射瞬态）。 | ESP32-S3 硬件设计指南 §电源 | 新增 **C15 22 µF 0805**（C45783, Basic）紧贴模组。 |
| E7 | ✅ 核对通过 | LDO **AP2112K-3.3**：600 mA 输出、压降 250 mV@600 mA（典型），ESP32-S3 BLE 峰值 <350 mA，WiFi 峰值 500 mA 也在额定内；电池 3.55 V 以上可稳 3.3 V，3.4 V 时 3V3≈3.2 V 模组仍工作（3.0–3.6 V）。EN 接 VIN。 | AP2112 DS | 保留。说明：JLC 无同等性能的 Basic LDO（AMS1117 压降 1.1 V 不适合锂电）。 |
| E8 | ✅ | 电源路径：USB → D1 B5819W → VSYS；电池 → 开关 → Q1 AO3401A(G=VBUS, S=VSYS, D=VBAT_SW) → VSYS。有 USB 时 Q1 截止，系统由 USB 供电、充电器只给电池充电（**负载共享，充电可正常终止**）；D1 阻断 VSYS 反灌 VBUS。R5 100 k 使无 USB 时 Q1 栅极为 0，Vgs≈−VBAT 导通（AO3401A Vth≤1.3 V）。 | — | 保留。注意：插 USB 时即使开关拨到 OFF 设备也会工作（设计如此），开关只断电池。 |
| E9 | ✅ | EN：10 kΩ 上拉 + 1 µF（τ=10 ms，满足乐鑫 ≥50 µs 要求）+ RESET 键；GPIO0：10 kΩ 上拉 + BOOT 键。 | 指南 §复位/Strapping | 保留。 |
| E10 | ✅ | Strapping：GPIO0 仅接 BOOT 键；**GPIO3/45/46 未使用**；GPIO35/36/37 (N16R8 八线 PSRAM 占用) 未使用。 | 模组 DS 表 2/3 | 无需改。 |
| E11 | ✅ | USB：D−=GPIO19(pin13)、D+=GPIO20(pin14)；USB-C A6/B6、A7/B7 并接；**CC1、CC2 各自独立 5.1 kΩ** 下拉；USBLC6-2SC6 引脚 1/6=D+、3/4=D−、5=VBUS、2=GND 正确。 | — | 保留。VBUS 无保险丝：USB 主机自带限流，低风险，已列入剩余风险。 |
| E12 | ✅ | 电池电压：VBAT_SW → 100 k/100 k → GPIO1 (ADC1_CH0，BLE 时可用) + 100 nF。静态电流 21 µA。 | — | 保留；固件改为 16 次平均 + 11 dB 衰减。 |
| E13 | 🟠 | **电池保护**：板上无 DW01+FS8205。 | — | 维持"必须使用自带保护板的电芯"（603450 常见带 PCM），已在 BOM/文档/上电清单中强调；固件增加 3.30 V 低压自动深睡作为二次保护。 |
| E14 | 🟢 | 按键/编码器引脚表与固件逐一核对一致（见 §3）。 | — | — |

### 1.2 PCB 布局

| # | 严重度 | 问题 | 修复 |
|---|---|---|---|
| P1 | 🔴 | ESP32-S3-WROOM-1 封装 EP 散热过孔 **钻孔 0.2 mm**，JLC 2 层板最小钻孔 0.3 mm（0.2 mm 仅多层板），会被拒单或加价。 | gen_pcb.py 自动把 <0.3 mm 的孔改为 0.3/0.6 mm（因此 DRC 有 1 条"与库不一致"警告，属预期）。 |
| P2 | 🟠 | 天线禁布区只有 ±11 mm（模组宽 18 mm，两侧仅 2 mm），两侧 GND 铺铜贴近天线。 | 禁布区（所有铜层，禁走线/过孔/铺铜）扩大到 **x = ±20 mm**、天线前沿到板边；模组天线端距板边约 0.5 mm，符合"模组放板边、天线下方及两侧无铜"的乐鑫推荐。 |
| P3 | 🟠 | 电源线全部 0.25 mm。 | 新建网络类：Power(VSYS/VBAT/VBAT_SW/+3V3) **0.4 mm**、VBUS **0.35 mm**（USB-C 0.5 mm 间距焊盘处无法更宽）。1 oz 外层 0.35 mm ≈ 1 A @ΔT10 °C，余量 >2×。 |
| P4 | 🟠 | 无 GND 缝合过孔。 | import_route.py 自动在两面 GND 铺铜的空闲处以 4 mm 网格打 **184 个缝合过孔**（避开焊盘、器件下方、禁布区）；铺铜孤岛自动移除。 |
| P5 | 🟠 | 规则未按 JLC 工艺设置。 | patch_pro.py：最小线宽/间距 0.127、默认间距 0.2、过孔 0.6/0.3、孔-孔 0.5、铜-板边 0.3、最小孔 0.3、丝印字高 ≥0.8 mm。 |
| P6 | 🟠 | USB 差分：在 JLC 2 层 1.6 mm（FR-4 εr≈4.5、介质≈1.5 mm）上，90 Ω 边耦合微带需线宽 ≈ **1.2 mm / 间距 0.2 mm**（Zdiff = 2·Z0·(1−0.48e^(−0.96 s/h))，Z0 = 87/√(εr+1.41)·ln(5.98h/(0.8w+t))），无法进入 0.5 mm 间距的 USB-C 焊盘和 1.27 mm 间距的模组焊盘。 | 采用 **0.25 mm / 间距 0.2 mm + 两面 GND 铺铜**（计算 Zdiff≈110–150 Ω）。ESP32-S3 为 **全速 USB 12 Mbps**（上升沿 4–20 ns，临界长度 >1 m），阻抗与等长不影响功能：当前 D+ 91.7 mm / D− 69.2 mm，偏差 22 mm ≈ 0.15 ns ≪ 83 ns 位宽。说明：模组在前沿（天线需要）而 USB-C 在后沿，走线长度由机械布局决定。 |
| P7 | ✅ | 封装核对：TS-1102S 规格书焊盘 9.0 mm 跨距/4.5 mm 行距 vs KiCad SW_SPST_PTS645（±3.98/±2.25）✔；TS-1187A 7.0/5.0 × 4.5/3.0 vs SW_SPST_TL3342（±3.15/±1.9）✔；EC11E 立式带开关 ✔；HRO TYPE-C-31-M-12 ✔；PCM12SMTR ✔；JST S2B-PH-SM4-TB ✔；AP2112K/MCP73831/SN74LV1T34 均为 SOT-23-5（SOT-25）✔；USBLC6 SOT-23-6 ✔。 | — |
| P8 | ✅ | 安装孔 H1–H4 与外壳螺柱同源（`mechanical/params.py` SCREWS），USB-C/开关舌片、开口同源，自动一致；USB-C 端面在内壁，外侧 13×7.5 mm 沉台。 | — |
| P9 | 🟢 | 自动布线（Freerouting）+ 优化；未手工美化。 | 已加网络类、缝合、规则后重新布线，100% 连通。 |

### 1.3 固件（firmware/src/main.cpp，v1.0.0 → v1.1.0）

| # | 严重度 | 问题 | 修复 |
|---|---|---|---|
| F1 | 🔴 | 充电状态逻辑与新硬件不符（原 `INPUT_PULLUP` + "低=充电"），无 USB 时也会误判。 | `charging = VBUS_SENSE && !CHG_STAT`；`full = VBUS_SENSE && CHG_STAT`；两脚改为 `INPUT`（外部分压）。 |
| F2 | 🟠 | BLE 安全参数在广播**之后**才设置，且未设置 IO 能力/密钥分发，部分系统配对失败。 | `BLESecurity` 移到 `init` 之后、建服务前：`ESP_LE_AUTH_REQ_SC_BOND`、`ESP_IO_CAP_NONE`、ENC+ID 密钥；广播加扫描响应。 |
| F3 | 🟠 | USB 与 BLE 同时发送：两路连同一台电脑会**重复按键**；未枚举时仍调用 TinyUSB 发送（可能超时阻塞）。 | 仅在 USB 已枚举时发 USB 报告；USB 已连接时默认不发 BLE（配置 `"ble_when_usb":true` 可开启）。 |
| F4 | 🟠 | 编码器 ISR 用 `digitalRead`，每 2 个有效跳变就计 1 格并清零，抖动/丢沿会累积偏移。 | ISR 用 `gpio_get_level`；查表解码，非法跳变记 0；**只在到达止动位(AB=11，半步型也含 00)且累计 ≥ steps 时计 1 格，并在每个止动位清零**；`knob_steps`/`wheel_steps` 可配 2 或 4。 |
| F5 | 🟠 | 无深度睡眠（原文档已承认）。 | 电池供电且 `sleep_min`（默认 10 分钟）无操作 → 深睡，**ext1 任意按键低电平唤醒**（9 个按键均为 RTC GPIO，保持 RTC 上拉）；`{"cmd":"sleep"}` 可手动测试。 |
| F6 | 🟠 | 电池读数单次采样；LED 逻辑表达式错误（`? 0 : 0`）。 | 16 次平均 + LiPo 曲线百分比，BLE 电量服务按 2% 变化更新；LED：充电橙、充满绿、BLE 蓝、仅 USB 暗青、低电熄灭。 |
| F7 | 🟢 | 无低压保护。 | 无 USB 且连续 5 秒 <3.30 V → 深睡。 |
| F8 | 新增 | **硬件自检模式**：按住 TOP 键上电，或串口 `{"cmd":"selftest","on":true}`。不发任何 HID，串口打印每个按键 DOWN/up（含 GPIO 号）、编码器每格方向及 AB 电平/跳变数、每 2 s 打印 VBAT/USB/STAT/充电/BLE/USB 状态；启动时 LED 依次 红/绿/蓝/白。 | — |
| F9 | ✅ | USB 组合设备：`ARDUINO_USB_MODE=0`（TinyUSB OTG）+ `CDC_ON_BOOT=1`，Keyboard/Consumer 在 `USB.begin()` 之前 `begin()`，得到 键盘+多媒体+CDC 复合设备，配置正确。去抖 5 ms、单/双/长按逻辑核对无误。 | — |

---

## 2. 料号核验（JLCPCB 元件库实时查询，2026-10-08 02:09 北京时间）

全部 26 个 LCSC 料号均**存在、有货、封装与 PCB 封装一致**。JLC BOM 共 26 行（ENC1/ENC2 为插件手焊，不在 JLC BOM/CPL 中）。
扩展件 11 种（JLC 每种约 $3 换料费）。元件合计约 **$12.3/台**（1+ 单价，不含 PCB/贴片费）。完整数据：`pcb/fab/BOM_detailed.csv`、原始查询结果：`pcb/fab/jlc_parts.json`。

| 位号 | 数量 | 值/型号 | LCSC | JLC 封装 | 库存 | 类型 | 单价 USD(1+) | 链接 |
|---|---|---|---|---|---|---|---|---|
| U1 | 1 | ESP32-S3-WROOM-1-N16R8 | C2913202 | SMD,25.5x18mm | 28065 | Extended | 5.1371 | [LCSC](https://www.lcsc.com/product-detail/wifi-modules_espressif-systems-esp32-s3-wroom-1-n16r8_C2913202.html) |
| C1,C4,C5,C6,C7 | 5 | CL10A106KP8NNNC | C19702 | 0603 | 9803287 | Basic | 0.0319 | [LCSC](https://www.lcsc.com/product-detail/multilayer-ceramic-capacitors-mlcc-smd-smt_samsung-electro-mechanics-cl10a106kp8nnnc_C19702.html) |
| C2,C8,C10,C9 | 4 | CL05B104KO5NNNC | C1525 | 0402 | 22193039 | Basic | 0.0045 | [LCSC](https://www.lcsc.com/product-detail/multilayer-ceramic-capacitors-mlcc-smd-smt_samsung-electro-mechanics-cl05b104ko5nnnc_C1525.html) |
| C15 | 1 | CL21A226MAQNNNE | C45783 | 0805 | 3925500 | Basic | 0.2202 | [LCSC](https://www.lcsc.com/product-detail/multilayer-ceramic-capacitors-mlcc-smd-smt_samsung-electro-mechanics-cl21a226maqnnne_C45783.html) |
| R1,R2,R13,R14,R15,R16 | 6 | 0402WGF1002TCE | C25744 | 0402 | 22127768 | Basic | 0.0034 | [LCSC](https://www.lcsc.com/product-detail/chip-resistor-surface-mount_uni-royal-uniroyal-elec-0402wgf1002tce_C25744.html) |
| C3 | 1 | CL05A105KA5NQNC | C52923 | 0402 | 8511992 | Basic | 0.0107 | [LCSC](https://www.lcsc.com/product-detail/multilayer-ceramic-capacitors-mlcc-smd-smt_samsung-electro-mechanics-cl05a105ka5nqnc_C52923.html) |
| SW10,SW11 | 2 | TS-1187A-B-A-B | C318884 | SMD-4P,5.1x5.1mm | 450167 | Basic | 0.0205 | [LCSC](https://www.lcsc.com/product-detail/tactile-switches_xkb-connection-ts-1187a-b-a-b_C318884.html) |
| J1 | 1 | TYPE-C-31-M-12 | C165948 | SMD | 419942 | Extended | 0.1857 | [LCSC](https://www.lcsc.com/product-detail/usb-connectors_korean-hroparts-elec-type-c-31-m-12_C165948.html) |
| R3,R4 | 2 | 0402WGF5101TCE | C25905 | 0402 | 5920486 | Basic | 0.0024 | [LCSC](https://www.lcsc.com/product-detail/chip-resistor-surface-mount_uni-royal-uniroyal-elec-0402wgf5101tce_C25905.html) |
| U2 | 1 | USBLC6-2SC6 | C7519 | SOT-23-6L | 49925 | Extended | 0.1767 | [LCSC](https://www.lcsc.com/product-detail/esd-and-surge-protection-tvs-esd_stmicroelectronics-usblc6-2sc6_C7519.html) |
| D1 | 1 | B5819W SL | C8598 | SOD-123 | 453537 | Basic | 0.028 | [LCSC](https://www.lcsc.com/product-detail/schottky-diodes_jiangsu-changjing-electronics-technology-co-ltd-b5819w-sl_C8598.html) |
| Q1 | 1 | AO3401A | C15127 | SOT-23 | 792451 | Basic | 0.1017 | [LCSC](https://www.lcsc.com/product-detail/mosfets_alpha-omega-semicon-ao3401a_C15127.html) |
| R5,R8,R9 | 3 | 0402WGF1003TCE | C25741 | 0402 | 8458602 | Basic | 0.0024 | [LCSC](https://www.lcsc.com/product-detail/chip-resistor-surface-mount_uni-royal-uniroyal-elec-0402wgf1003tce_C25741.html) |
| U3 | 1 | MCP73831T-2ACI/OT | C424093 | SOT-23-5 | 4870 | Extended | 0.782 | [LCSC](https://www.lcsc.com/product-detail/battery-management_microchip-tech-mcp73831t-2aci-ot_C424093.html) |
| R6 | 1 | 0402WGF3301TCE | C25890 | 0402 | 2076622 | Basic | 0.0035 | [LCSC](https://www.lcsc.com/product-detail/chip-resistor-surface-mount_uni-royal-uniroyal-elec-0402wgf3301tce_C25890.html) |
| R7 | 1 | 0402WGF1502TCE | C25756 | 0402 | 1009473 | Basic | 0.0016 | [LCSC](https://www.lcsc.com/product-detail/chip-resistor-surface-mount_uni-royal-uniroyal-elec-0402wgf1502tce_C25756.html) |
| R10,R11 | 2 | 0402WGF2202TCE | C25768 | 0402 | 791296 | Basic | 0.0024 | [LCSC](https://www.lcsc.com/product-detail/chip-resistor-surface-mount_uni-royal-uniroyal-elec-0402wgf2202tce_C25768.html) |
| R12 | 1 | 0402WGF3902TCE | C25783 | 0402 | 212317 | Preferred | 0.0024 | [LCSC](https://www.lcsc.com/product-detail/chip-resistor-surface-mount_uni-royal-uniroyal-elec-0402wgf3902tce_C25783.html) |
| SW12 | 1 | PCM12SMTR | C221841 | SMD | 11194 | Extended | 1.7834 | [LCSC](https://www.lcsc.com/product-detail/slide-switches_c-k-pcm12smtr_C221841.html) |
| J2 | 1 | S2B-PH-SM4-TB(LF)(SN) | C295747 | SMD,P=2mm,Surface Mount，Right Angle | 16430 | Extended | 0.2364 | [LCSC](https://www.lcsc.com/product-detail/wire-to-board-connector_jst-s2b-ph-sm4-tb-lf-sn_C295747.html) |
| U4 | 1 | AP2112K-3.3TRG1 | C51118 | SOT-25-5 | 34502 | Extended | 0.171 | [LCSC](https://www.lcsc.com/product-detail/voltage-regulators-linear-low-drop-out-ldo-regulators_diodes-incorporated-ap2112k-3-3trg1_C51118.html) |
| D2 | 1 | WS2812B-B/T | C2761795 | SMD5050-4P | 81023 | Extended | 0.1069 | [LCSC](https://www.lcsc.com/product-detail/rgb-leds-built-in-ic_worldsemi-ws2812b-b-t_C2761795.html) |
| U5 | 1 | SN74LV1T34DBVR | C100024 | SOT-23-5 | 24800 | Extended | 0.3538 | [LCSC](https://www.lcsc.com/product-detail/buffers-drivers-receivers-transceivers_texas-instruments-sn74lv1t34dbvr_C100024.html) |
| C11,C12,C13,C14 | 4 | CL05B103KB5NNNC | C15195 | 0402 | 3905751 | Basic | 0.005 | [LCSC](https://www.lcsc.com/product-detail/multilayer-ceramic-capacitors-mlcc-smd-smt_samsung-electro-mechanics-cl05b103kb5nnnc_C15195.html) |
| SW1,SW2,SW3,SW4,SW5,SW6,SW7,SW8,SW9 | 9 | TS-1102S-6x6x5.5-160 | C53431191 | SMD | 1038 | Extended | 0.0397 | 非 LCSC 件，见下文 |
| ENC1 | 1 | EC11E18244A5 | C255515 | Plugin | 713 | Extended | 2.4028 | [LCSC](https://www.lcsc.com/product-detail/rotary-encoders_alpsalpine-ec11e18244a5_C255515.html) |
| ENC2 | 1 | Mouse wheel encoder 11mm (Kailh/TTC) | — |  | — | — | 0 | 非 LCSC 件，见下文 |

说明与提醒：
- "Preferred" = JLC 扩展库中的"优选"件（免换料费）。ESP32-S3 模组 LCSC 现货显示 0，但 **JLC 贴片仓库存 28 065**，JLC 贴片以后者为准。
- **库存偏低需关注**：TS-1102S-6x6x5.5-160（C53431191，JLC 1 038 / LCSC 1 020，每板 9 个 → 约 110 台）、EC11E18244A5（C255515，JLC 713 / LCSC 441）、MCP73831（4 870）。批量前先锁料或准备替代：6×6 轻触 **K2-1102SP-C4SC-04（C127509，库存 3.4 万，同 PTS645 封装尺寸需复核高度）**。
- **ENC2 鼠标滚轮编码器不在 LCSC/JLC**（搜索 "mouse encoder/鼠标编码器" 无结果），需淘宝/1688 购买 Kailh/TTC 11 mm 编码器；PCB 封装为占位封装，**下单 PCB 前必须按实物核对引脚距和孔径**。
- 本次替换/新增：R6 2k→3.3k(C25890)；R7 改 15k(C25756)；新增 R10/R11 22k(C25768)、R12 39k(C25783)、R13–R16 10k(C25744)、C11–C14 10nF(C15195)、C10 100nF(C1525)、C15 22µF(C45783)、U5 SN74LV1T34DBVR(C100024)。

### 2.1 CPL 旋转角
`make_bom_cpl.py` 对 KiCad 角度加以下修正（来源：kicad-jlcpcb-tools / JLCKicadTools 常用修正表，**仍须在 JLC 预览中逐个确认**）：
SOT-23 / SOT-23-5 / SOT-23-6 **+180°**（Q1, U2, U3, U4, U5）；USB-C HRO TYPE-C-31-M-12 **+180°**；JST PH S2B-PH-SM4-TB **+180°**；其余 0。

在 JLC "贴片预览" 中重点检查：
1. **U1 ESP32-S3 模组**：天线必须朝板前沿（远离 USB-C），pin 1 在模组左上（KiCad 中模组旋转 180°）。
2. **U3/U4/U5（SOT-23-5）**：1 脚圆点与丝印一致；U2 USBLC6（SOT-23-6）同理；Q1 AO3401A 方向与丝印一致。
3. **J1 USB-C**：插口朝板外（后沿）；**J2 JST**：开口朝板外侧、两个固定焊盘在后侧。
4. **D2 WS2812B**：缺角/1 脚标记对准丝印 1 脚（VDD）。
5. SW12 拨动开关拨杆朝板外；SW10/SW11、6×6 轻触开关对称，方向不影响电气。
6. 坐标采用 KiCad 原点（Y 为负值），与 Gerber 坐标一致，JLC 可直接识别；若预览整体偏移，用 JLC 的"对齐"功能。

---

## 3. 引脚对照（原理图 = 固件）

| 功能 | 网络 | 模组 pin | GPIO | 固件 |
|---|---|---|---|---|
| TOP（SW1+SW2 并联）| K_TOP | 4 | IO4 | KEY_PINS[0] |
| SIDE | K_SIDE | 5 | IO5 | [1] |
| TR1 / TR2 | K_TR1/K_TR2 | 6 / 7 | IO6 / IO7 | [2] / [3] |
| TALL1 / TALL2 | K_TALL1/2 | 8 / 9 | IO15 / IO16 | [4] / [5] |
| BR | K_BR | 10 | IO17 | [6] |
| 旋钮按压 / 滚轮按压 | K_KNOB / K_WHEEL | 11 / 12 | IO18 / IO8 | [7] / [8] |
| 旋钮 A/B | ENC1_A/B | 17 / 18 | IO9 / IO10 | ENC_KNOB_A/B |
| 滚轮 A/B | ENC2_A/B | 19 / 20 | IO11 / IO12 | ENC_WHEEL_A/B |
| LED（经 U5）| LED_IO | 25 | IO48 | LED_PIN |
| 电池分压 | VBAT_SENSE | 39 | IO1 (ADC1_CH0) | VBAT_ADC |
| 充电状态 | CHG_STAT | 38 | IO2 | CHG_STAT |
| USB 检测 | VBUS_SENSE | 21 | IO13 | VBUS_SENSE |
| USB D−/D+ | USB_DN/DP | 13 / 14 | IO19 / IO20 | 原生 USB |
| BOOT / EN | BOOT / EN | 27 / 3 | IO0 / EN | — |

---

## 4. 验证结果
- ERC：0 错误 0 警告（`pcb/erc.rpt`）。
- DRC：**0 错误，0 未连接，原理图一致性 0**；14 条警告 = 丝印被板边/阻焊裁切或重叠 13 条 + 模组封装与库不一致 1 条（P1 有意修改）。（`pcb/drc.rpt`）
- 固件：PlatformIO espressif32@6.9.0 / Arduino-ESP32 2.0.x 编译成功，main.cpp 无警告；`firmware/bin/` 已更新（合并镜像 0x0）。

---

## 5. 首版上电调试清单（Bring-up）
1. **到板目检**：U1 天线朝前沿；U2–U5、Q1、D1（阴极条朝 VSYS/U4 侧）、D2 方向；USB-C 引脚无连锡（放大镜）。
2. **不装电池、不插 USB**，万用表测对地电阻：VBUS、VSYS、VBAT、+3V3 均 >1 kΩ（3V3 因模组约数 kΩ 正常）。
3. 手焊 ENC1、ENC2（ENC2 先核对实物引脚！）。
4. **限流电源 5 V / 200 mA 接 VBUS**（或带电流表的 USB 线）：空载电流 <80 mA；测 VSYS≈4.7 V、+3V3=3.30 V±3%、U5 VCC=VSYS。
5. 插电脑：应出现 USB 串口（若为空白芯片会显示 ESP32-S3 JTAG/串口）。按住 BOOT、点 RESET 进入下载模式，烧录 `creativedial-esp32s3-merged.bin` @0x0。
6. 复位后电脑识别 "CreativeDial"：HID 键盘 + Consumer + CDC 串口。
7. **自检模式**：按住 TOP 键插 USB，打开串口(115200)：LED 依次红/绿/蓝/白（验证 U5 电平转换）；逐个按 9 个键，确认串口打印的键名/GPIO 正确；旋钮每格打印 ±1（转 1 圈 = **36** 格，EC11E18244A5 36 止动/18 脉冲）；滚轮同理，若每格打印 2 次说明滚轮编码器为 4 跳变/格，发送 `{"cmd":"set","config":{...,"wheel_steps":4}}` 或 `knob_steps`。
8. **电池**（务必用带保护板电芯，先确认线序 J2 pin1=+）：先不插 USB、开关 ON：设备工作，`{"cmd":"battery"}` mV 与万用表误差 <50 mV。
9. 插 USB：LED 橙色（充电），STAT 分压点（GPIO2）≈0 V；充电电流 ≈300 mA；MCP73831 温升可接受；充满 LED 绿色，GPIO2≈3 V。
10. 断开 USB、开关 ON，确认 Q1 导通（VSYS≈VBAT−几十 mV）；插 USB 时 VBAT_SW 不被拉高（无反灌）。
11. BLE：拔 USB 后在手机/电脑配对 "CreativeDial"，按键有效；断开后自动重新广播。
12. 深睡：串口 `{"cmd":"sleep"}`（仅电池供电时有意义）→ 测电池电流（预期 ~1 mA，主要是 WS2812B 静态电流，见风险 R3），按任意键唤醒。
13. 射频：手持 + 装壳后测 BLE 距离（≥5 m 无断连）。

---

## 6. 仍需实物验证的风险
- **R1** ENC2 鼠标编码器封装为占位封装，且滚轮机构轴高依赖实物（最大风险，下单 PCB 前确认）。
- **R2** CPL 旋转角只能在 JLC 预览中最终确认（见 §2.1）。
- **R3** 深睡电流：WS2812B 静态约 0.6–1 mA + SN74LV1T34 + AP2112K 55 µA + 分压 21 µA，1000 mAh 待机约 1–2 个月；若要更长待机，Rev B 可用 P-MOS 给 LED 断电或换 3.3 V 供电 LED。
- **R4** VBAT<3.5 V 时 WS2812B 低于其 VDD 规格（3.5 V），可能偏色——固件在 3.45 V 以下关灯。
- **R5** 无板载电池保护，必须用带保护板电芯；VBUS 无保险丝（依赖主机限流）。
- **R6** 天线：模组在板边、天线两侧各 11 mm 无铜，但外壳、电池、手部对 BLE 距离的影响需实测。
- **R7** 自动布线，USB 差分非阻抗控制（全速 USB 可接受，见 P6）。
- **R8** PCM12SMTR 额定 0.3 A，BLE 工作峰值 <0.35 A 短时可接受；若启用 WiFi 应换更大电流开关或改为控制 MOSFET。
- **R9** 按键/旋钮机械配合、键帽行程、USB-C 插入深度需首版打印实测。
- **R10** 固件未在真机运行：HID 描述符、BLE 在 iOS/Windows/macOS 的配对兼容性、深睡唤醒需实测。

---

## 7. 修改过的文件
`pcb/design.py`、`pcb/gen_pcb.py`、`pcb/import_route.py`、`pcb/make_bom_cpl.py`、`pcb/route.sh`、`pcb/export.sh`、新增 `pcb/tools/jlc_lookup.py`、`pcb/tools/patch_pro.py`；
重新生成 `pcb/creative-controller.kicad_sch/.kicad_pcb/.kicad_pro`、`pcb/fab/*`；`firmware/src/main.cpp`、`firmware/bin/*`；`docs/README.md`、`README.md`。
重新生成流程：`cd pcb && ./route.sh && ./export.sh`（Freerouting 需 `/workspace/freerouting.jar` 与 Java）。

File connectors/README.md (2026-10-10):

# 连接器清单（connectors manifest）

> 导出时间：2026-10-09（北京时间）更新（新增 composio-zhimeng）。
> 连接器装在 **账号** 上，不是装在某个 bot 上：新号上第一个 bot 装好以后，后面用 CreateAgent 建的 bot 都能直接用。
> 本文件只记名字、ID、地址和步骤，**不含任何密钥**。
>
> **规矩**：应用连接默认只走 Composio 自定义 stdio MCP。**不要**再装官方 GitHub / Origin / Finance / Composio 插件。
> **例外**：飞书用官方 **lark-cli**（见下文「飞书 lark-cli」；Composio 无飞书）。
> - **`composio-pg`**：用户 `pg-test-…` → GitHub ZMGID（`ca_1g4u93YydZsp`）+ Gmail ohulercxm8（`ca_ZnzYtlTeic0s`）——**一个连接器一个 Gmail**
> - **`composio-zhimeng`**：用户 `zhimeng63` → Gmail zhimeng63（`ca_5jGHEthCoWuD`）only（共用 `/home/box/.composio_pg_key`）
> - 旧 composio-pg 上的 zhimeng63 连接 **`ca_2rJjmKh8j1q0` 已删除**（2026-10-09，用户同意）；新号勿在 pg-test 下重建 zhimeng63

| # | 连接器 | 类型 | 怎么装 | 需要用户做什么 | 必需？ |
|---|---|---|---|---|---|
| 1 | **composio-pg**（`user-composio-pg`） | 自定义 **stdio** MCP（跑在 box 上） | 见下文「composio-pg」；BOOTSTRAP Step 0 从本目录安装启动器 | 在密码框里填一次仓库口令 `GROKBOT_HOME_PASSPHRASE`（用来解密 `secrets/*.enc` 里的 Composio key） | ✅ 必需 |
| 2 | **composio-zhimeng**（`user-composio-zhimeng`） | 自定义 **stdio** MCP（跑在 box 上） | 见下文「composio-zhimeng」；与 composio-pg 共用 key 与 venv | 无（口令已在装 composio-pg 时填过）；若 zhimeng63 Gmail 未授权则在 Composio 里给用户 `zhimeng63` 授权 | ✅ 必需 |
| 3 | **飞书 lark-cli** | 官方 CLI（非 MCP 连接器） | `setup.sh` / `services/feishu-cli/`；见下文 | 换号后扫码：`lark-cli config init --new --brand feishu` + `lark-cli auth login` | ✅ 需要飞书时 |
| 4 | **GitHub**（`cursor-github`） | 官方连接器 | — | — | ❌ 不需要（GitHub 走 composio-pg） |
| 5 | **Origin**（`cursor-origin`） | 官方连接器 | — | — | ❌ 不需要 |
| 6 | **Composio 插件**（`user-Composio`，plugin id `32661537`） | 插件市场 OAuth 版 | — | — | ❌ 不需要（它看到的是另一个 Composio user） |
| 7 | **Finance**（`user-Finance-xai`，plugin id `63408931`） | 插件市场 | — | — | ❌ 不需要 |

另外两样不是「应用连接器」但要记得：

- **pstack 插件**（plugin id **`9717366`**，cursor-public）：写代码类 bot 用的工作流技能包（architect、tdd、swarm、arena……）。**可选**（原为 dr eggbot 安装；该 bot 已于 2026-10-08 删除）。这是技能插件，不是应用连接；需要时再 `InstallPlugin 9717366`。
- **`x` 工具命名空间**（X/Twitter 搜索、新闻）：平台自带，不需要安装；新号若没有就忽略。
- **`gh` 命令行**：不是连接器。仓库公开，克隆不需要登录；只有推送（写回、每日同步）才需要。新号上用 Composio 里 GitHub（ZMGID）的 access token 做 `gh auth login --with-token`（见 BOOTSTRAP Step 1）；失败再退回设备码登录。

## composio-pg（自定义 stdio MCP）——GitHub + ohulercxm8 Gmail

**它是什么**：box 上的一个小启动器。读取 `~/.composio_pg_key`（Composio 项目 API key），用 Composio SDK 给用户
`pg-test-5be86c3e-d220-4538-ab6d-ae22d538dfde` 创建一个会话，再用 `npx mcp-remote` 把会话的 MCP 地址桥接成 stdio。

**这个 Composio 用户下现有的连接**（2026-10-09 核对；**勿**再挂 zhimeng63）：

| 应用 | 账号 | connected account |
|---|---|---|
| GitHub | ZMGID（ZhiMeng） | `ca_1g4u93YydZsp` |
| Gmail | ohulercxm8@gmail.com | `ca_ZnzYtlTeic0s` |

~~旧~~：曾有 Gmail zhimeng63@gmail.com / `ca_2rJjmKh8j1q0`，已于 2026-10-09 经用户同意从 composio-pg 删除。新号重建时**不要**在 pg-test 用户下再授权 zhimeng63——只走 composio-zhimeng。

Composio 项目 ID：`pr_lh5-8poHU4QB`（只有这一个项目）。

**文件**：`connectors/composio-pg/launch.py`、`launch.sh`（不含密钥）。BOOTSTRAP Step 0 (c) 把它们装到 `/workspace/composio-pg/`；`launch.sh` 依赖 `/workspace/composio-pg/.venv`（装有 `composio==0.25.0`），以及 node/npx（`npx -y mcp-remote`）。

**安装步骤**：

1. 用 **secret-request（密码框，掩码输入）** 向用户要仓库口令 `GROKBOT_HOME_PASSPHRASE`，然后解密 key：
   `python3 scripts/secret-crypt.py dec secrets/COMPOSIO_API_KEY.enc /home/box/.composio_pg_key && chmod 600 /home/box/.composio_pg_key`
   （冒烟测试不通过就改用 `secrets/COMPOSIO_API_KEY.box-current.enc`）。**绝不能**让用户把口令或 key 贴进聊天，也不要 `cat` 出来。
   - 解密失败时的备选：用密码框直接要 Composio 项目 API key（Composio 控制台 → 项目设置 → API Keys），或请用户在 bot 桌面终端执行
     `read -rsp 'Composio key: ' K && umask 077 && printf %s "$K" > ~/.composio_pg_key && unset K`
2. 装启动器（也可以直接跑 `setup.sh`，它做同样的事）：
   ```bash
   mkdir -p /workspace/composio-pg && cd /workspace/composio-pg
   install -m 700 /workspace/grokbot-home/connectors/composio-pg/launch.sh .
   install -m 600 /workspace/grokbot-home/connectors/composio-pg/launch.py .
   [ -x .venv/bin/python ] || uv venv -q .venv
   uv pip install -q --python .venv/bin/python "composio==0.25.0" || uv pip install -q --python .venv/bin/python composio
   npx -y mcp-remote --help >/dev/null 2>&1 || true
   ```
3. 冒烟测试（**不要**打印 stderr：mcp-remote 会在日志里明文打印 `x-api-key`）：
   `timeout 40 /workspace/composio-pg/launch.sh </dev/null >/dev/null 2>/tmp/cpg.err; grep -c "Proxy established successfully" /tmp/cpg.err; rm -f /tmp/cpg.err`
   ——输出 `1` 即成功。
4. `AddMcpServer`：name **`composio-pg`**，command **`/workspace/composio-pg/launch.sh`**，无 args、无 env。
5. 自检：`user-composio-pg` → `COMPOSIO_MANAGE_CONNECTIONS`，参数 `{"toolkits":["github","gmail"]}`（**不要** `reinitiate_all`），
   应返回 `All connections are active`，GitHub login 为 ZMGID，Gmail 为 ohulercxm8@gmail.com。

**新应用（给 pg-test 用户）**：只在 Composio 控制台给测试用户 `pg-test-5be86c3e-d220-4538-ab6d-ae22d538dfde` 授权新 toolkit，然后通过 composio-pg 使用。**不要**再装官方连接器。

**换号/轮换 key**：重写 `~/.composio_pg_key` 并 `RestartMcpServers`（两个 MCP 都会用到同一 key）；然后重新加密写回仓库（`python3 scripts/secret-crypt.py enc /home/box/.composio_pg_key secrets/COMPOSIO_API_KEY.enc`，见 `secrets/README.md`），跑 `scripts/secret-scan.sh` 再推送。

## composio-zhimeng（自定义 stdio MCP）——zhimeng63 Gmail only

**它是什么**：与 composio-pg 同类的启动器，但 Composio 用户为 **`zhimeng63`**，toolkit 仅 **gmail**。读取同一份 `~/.composio_pg_key`；`launch.sh` 复用 `/workspace/composio-pg/.venv/bin/python`。

**连接**（2026-10-09 核对）：

| 应用 | 账号 | connected account |
|---|---|---|
| Gmail | zhimeng63@gmail.com | `ca_5jGHEthCoWuD`（ACTIVE，已验证可读） |

**文件**：`connectors/composio-zhimeng/launch.py`、`launch.sh`（不含密钥；key 只从路径读取）。`setup.sh` / BOOTSTRAP Step 0 (d) 装到 `/workspace/composio-zhimeng/`。

**安装步骤**（在 composio-pg 装好且 `~/.composio_pg_key` 已就位之后）：

1. ```bash
   mkdir -p /workspace/composio-zhimeng
   install -m 700 /workspace/grokbot-home/connectors/composio-zhimeng/launch.sh /workspace/composio-zhimeng/
   install -m 600 /workspace/grokbot-home/connectors/composio-zhimeng/launch.py /workspace/composio-zhimeng/
   ```
2. 冒烟测试（同样**不要**打印 stderr）：
   `timeout 40 /workspace/composio-zhimeng/launch.sh </dev/null >/dev/null 2>/tmp/czm.err; grep -c "Proxy established successfully" /tmp/czm.err; rm -f /tmp/czm.err`
3. `AddMcpServer`：name **`composio-zhimeng`**，command **`/workspace/composio-zhimeng/launch.sh`**，无 args、无 env（在 composio-pg 之后添加）。
4. 自检：`user-composio-zhimeng` → `COMPOSIO_MANAGE_CONNECTIONS` `{"toolkits":["gmail"]}`（**不要** `reinitiate_all`）→ active；再读一封 zhimeng63 邮件确认。
5. 若新号上缺少 zhimeng63 的 Gmail 连接：用 `COMPOSIO_MANAGE_CONNECTIONS` 给 Composio 用户 **`zhimeng63`** 重新授权 Gmail（**不要**用 pg-test / composio-pg；旧 `ca_2rJjmKh8j1q0` 已删，勿重建到 composio-pg）。

## Grok Bot 自带邮箱（不是连接器，2026-10-10）
- `cloudpotato@mail.grokbot.com`：Grok Bot 原生邮箱，由小萌在当前账号领取。**绑在当前账号上，不能转移，换号即丢失**；新号若需要，只能用 ListEmailInboxes / ClaimEmailInbox 另领一个新地址（地址会不同），并相应改写「cloudpotato 来信提醒」任务。只用于临时注册、验证码等可丢弃用途。

## Gmail 来信监听（gmail-listener + 小萌 webhook）

盒子上的 `/workspace/gmail-listener/` 订阅 Composio 实时通道，把 `GMAIL_NEW_GMAIL_MESSAGE` 推到小萌的 webhook 例程 **gmail-new-mail**（folder `gmail-new-mail`）。脚本备份：`services/gmail-listener/`（`listener.py` / `run_loop.sh` / `start.sh` / `stop.sh` / README；**不含** venv、log、`seen.txt`、`forwarded_ids.txt`、`failed.jsonl`、`webhook_url.local`）。

| 触发器 id | 邮箱 | Composio 用户 / MCP | connected account |
|---|---|---|---|
| `ti_ePC_aV3eRSPT` | ohulercxm8@gmail.com | pg-test / **composio-pg** | `ca_ZnzYtlTeic0s` |
| `ti_6ozhOAfOaHLq` | zhimeng63@gmail.com | zhimeng63 / **composio-zhimeng** | `ca_5jGHEthCoWuD` |

**环境变量**（运行时，**值永不进仓库**）：`COMPOSIO_API_KEY`（可与 `~/.composio_pg_key` 同源）、`GMAIL_WEBHOOK_KEY`。

**换号 / 新账号**：
1. 按各 Composio 用户重建两个 `GMAIL_NEW_GMAIL_MESSAGE` 触发器（勿把 zhimeng63 建到 pg-test）。
2. 用户通过密码框重新提供 `GMAIL_WEBHOOK_KEY`（旧 key 作废）。
3. 把新 webhook URL 写入 `/workspace/gmail-listener/webhook_url.local`（`chmod 600`）或 env `GMAIL_WEBHOOK_URL`（**永不进仓库**）。
4. 从仓库恢复脚本到 `/workspace/gmail-listener/`，建好 venv 后执行 `start.sh`。
5. 盒子无 systemd：**每次盒子重启后须手动** `/workspace/gmail-listener/start.sh`。

例程提示词见 `bots/grok-bot/routines.md` §6；另见 cloudpotato 邮箱触发 §5。

## 飞书 lark-cli（Composio-only 例外）

- 包：`@larksuite/cli` → 命令 `lark-cli`（当前 box：**1.0.97**），`export PATH="$HOME/.local/bin:$PATH"`。
- brand：`feishu`；自建应用 id：`cli_aa430b6809f85d0c`（bot + 用户身份；用户 王枳萌）。
- 换号后：`lark-cli config init --new --brand feishu`（用户扫码），再 `lark-cli auth login`（用户扫码）。
- **永不进仓库**：`~/.lark-cli/`、`~/.local/share/lark-cli/`、`/workspace/feishu-cli/survey/`。
- 群 chat_id（仅此）：见 `services/feishu-cli/chats.md` —— 全员群 `oc_1bfe10631cc60ae750bbc378376f3c4d`；bot 通知群 `oc_ba1ec97d712cc401cabc3a09c610dcbb`。

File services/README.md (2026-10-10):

# services/

盒子上的本地服务脚本备份（**不含密钥、不含邮件正文/主题状态文件**）。

| 目录 | 用途 | 运行时路径 | 换号/重启 |
|---|---|---|---|
| `gmail-listener/` | 把 Composio Gmail 新邮件触发推到小萌 webhook 例程 | `/workspace/gmail-listener/` | 重建例程 + `GMAIL_WEBHOOK_KEY` + `webhook_url.local`/`GMAIL_WEBHOOK_URL` + 触发器；手动 `start.sh` |
| `feishu-cli/` | 飞书 lark-cli 说明与两个群 chat_id | CLI 在 `~/.local`；配置在 `~/.lark-cli/`（不进仓库） | `lark-cli config init --new --brand feishu` + `lark-cli auth login`（扫码） |

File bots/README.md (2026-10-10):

# bots/

每个 bot 一个文件夹：

- `profile.md`：名字、头衔、description（CreateAgent 用）、头像形状/颜色、设置
- `CONTEXT.md`：这个 bot 自己的记忆和项目状态（新 bot 建好后第一件事就是读它）
- `routines.md`：它的定时任务（或 none）

| 文件夹 | 名字 | 角色 | 主 bot | 定时任务 |
|---|---|---|---|---|
| `grok-bot/` | 小萌（原 Grok Bot） | 主 bot / 经理：分派任务、创建新 bot、巡检、来信提醒 | ✅ | 巡检 11:17/15:17；cloudpotato 邮件触发；gmail-new-mail webhook；早晚报已移交事务秘书；同步已移交仓库管家 |
| `xiaozhi/` | 小枳 | 调研 + 虾皮（Shopee）选品 | | 无 |
| `仓库管家/` | 仓库管家 | 维护本仓库、跑每日 03:14 同步（含漂移检查）；每周换号演练与安全审计 | | 每日 03:14 同步；周日 15:12 演练/审计 |
| `代码工程师/` | 代码工程师 | Dsivio / kivio 的 CI、PR 与代码修复（GitHub 走 composio-pg） | | 无 |
| `搭建运维/` | 搭建运维 | 公司官网、飞书及其他系统搭建与维护 | | 无 |
| `事务秘书/` | 事务秘书 | 非技术事务 + 工作日早晚计划/总结（原名邮件秘书；只写草稿，从不发送） | | 工作日 08:53 计划、17:47 总结（Asia/Hong_Kong） |
| `硬件工程师/` | 硬件工程师 | 创作控制器（已暂停、待命），见 `projects/creative-controller/` | | 无 |
| `财务管家/` | 财务管家 | 记账 / 订阅与固定支出 / 预算 / 报销对账（只记录，从不付款） | | 无；账本 `/workspace/finance/` 不进仓库 |

机器可读清单：`index.json`。新增 bot 时同时更新这张表和 `index.json`。

旧号上还有一个空的 “New Bot”（2026-08 创建，没有设定、没有对话），判断不是在用的 bot，没有迁移。2026-10-08 用户已删除 **dr eggbot**（原「设计并创建 bot」），新建 bot 改由主 bot **小萌**（原名 Grok Bot，slug `grok-bot`）负责。

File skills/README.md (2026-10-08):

# skills/

**目前没有用户自建技能。** 旧号 `/home/box/agent-data/workflows/` 是空的（2026-10-08 检查）。

以后自建了技能：每个技能一个子文件夹（`skills/<slug>/SKILL.md`，可带 `references/`、`scripts/`），每日同步会自动从
`/home/box/agent-data/workflows/` 收进来。新号导入时把 `skills/<slug>/` 整个复制到 `/home/box/agent-data/workflows/<slug>/`
（或用 `skill-authoring` 托管技能的方式创建同名技能），然后确认它出现在技能列表里。

## 不放在这里、需要重装的

| 名称 | 类型 | 怎么恢复 |
|---|---|---|
| pstack | 插件（plugin id `9717366`，cursor-public），含 architect、tdd、swarm、arena 等约 40 个技能 | **可选**（原为 dr eggbot 安装）；需要时 `InstallPlugin 9717366` |
| Composio 插件技能（composio-mcp、composio-activity-summary） | 随官方 Composio 插件（`32661537`） | **不需要**（2026-10-08 起不装该插件；应用走 composio-pg） |
| 托管技能（add-connector、routines、export-bot-template、sign-in……） | 平台自带 | 不用管 |

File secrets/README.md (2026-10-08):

# secrets/

这里只放**加密后**的密钥，明文永远不进仓库（`.gitignore` 已拦截）。

- `COMPOSIO_API_KEY.enc`：用户贴给 bot 的 Composio 项目 API Key，用 `scripts/secret-crypt.py` 加密（scrypt N=2^20 + AES-256-CBC，文件头 `GBH1`）。
- `COMPOSIO_API_KEY.box-current.enc`：旧号 box 上 `~/.composio_pg_key` 里实际在用的 key（和上面那份不同）。BOOTSTRAP 先用 `.enc`，composio-pg 连不上再用这份。
- **仓库是公开的**：任何人都能下载这些 `.enc` 文件离线猜口令，所以口令要足够长（建议 4 个以上随机词或 16+ 位随机字符）。
- 解密需要用户的口令，放在环境变量 `GROKBOT_HOME_PASSPHRASE`（用 secret-request 向用户要，不要让用户贴在聊天里）：
  `python3 scripts/secret-crypt.py dec secrets/COMPOSIO_API_KEY.enc /home/box/.composio_pg_key`
  （口令错误时只报一行错误，不会写文件，也不会打印任何密钥材料。）
- 密钥轮换后：把新值写进 `~/.composio_pg_key`，再
  `python3 scripts/secret-crypt.py enc /home/box/.composio_pg_key secrets/COMPOSIO_API_KEY.enc`
  再 `bash scripts/secret-scan.sh`（会确认明文 key、两份 `.enc` 的明文和口令都没出现在仓库里，且 `secrets/*.enc` 都是 `GBH1` 加密格式）后提交推送。
- 换口令：先用旧口令把两份都解密到 `/tmp`（`umask 077`），换成新口令的环境变量后重新 `enc`，删掉 `/tmp` 里的明文。

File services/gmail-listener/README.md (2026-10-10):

> 仓库副本：备份 `listener.py`、`run_loop.sh`、`start.sh`、`stop.sh`、本 README。
> **永不备份**：`venv/`、`listener.log`、`forwarded_ids.txt`、`seen.txt`、`failed.jsonl`、`supervisor.pid`、`__pycache__/`、`webhook_url.local`（含 webhook URL）。
> 运行时目录：`/workspace/gmail-listener/`。

# gmail-listener

Forwards Composio Gmail trigger events (`GMAIL_NEW_GMAIL_MESSAGE`) to the Grok Bot webhook routine **gmail-new-mail**
using Composio's realtime (Pusher websocket) channel via the Python SDK `composio.triggers.subscribe()`.
No public URL and no Composio webhook subscription needed.

Webhook URL is **not** in the repo. `listener.py` loads it from:
1. env `GMAIL_WEBHOOK_URL`, else
2. file `webhook_url.local` in the same directory (`chmod 600`), else
3. exits with error.

Trigger instances (Composio, labelIds=INBOX, interval=1 min requested):
- `ti_ePC_aV3eRSPT` → `ca_ZnzYtlTeic0s` (ohulercxm8@gmail.com, composio-pg)
- `ti_6ozhOAfOaHLq` → `ca_5jGHEthCoWuD` (zhimeng63@gmail.com, composio-zhimeng)

## Env / local secrets (runtime only; values never in repo)

| Name | Purpose |
|---|---|
| `COMPOSIO_API_KEY` | Composio project API key (same material as `~/.composio_pg_key`) |
| `GMAIL_WEBHOOK_KEY` | Webhook auth key (user supplies via secret prompt on new account) |
| `GMAIL_WEBHOOK_URL` | Full webhook URL (optional if `webhook_url.local` exists) |

## Files

| File | In repo? |
|---|---|
| `listener.py`, `run_loop.sh`, `start.sh`, `stop.sh`, `README.md` | yes |
| `webhook_url.local` | **no** (mode 600 on box) |
| `venv/`, `listener.log`, `forwarded_ids.txt`, `seen.txt`, `failed.jsonl`, `supervisor.pid` | **no** |

## New account / rebuild checklist

1. Recreate 小萌's webhook routine **gmail-new-mail** (folder `gmail-new-mail`; prompt in `bots/grok-bot/routines.md`).
2. User provides the new key into env **`GMAIL_WEBHOOK_KEY`** via secret prompt (never chat / never commit).
3. Write the new webhook URL into `/workspace/gmail-listener/webhook_url.local` (`chmod 600`) **or** set env `GMAIL_WEBHOOK_URL`.
4. Recreate Composio `GMAIL_NEW_GMAIL_MESSAGE` triggers per user if needed (ohulercxm8 → composio-pg; zhimeng63 → composio-zhimeng).
5. Restore scripts from this directory, build venv if missing, run `/workspace/gmail-listener/start.sh`.

## After a box restart

The box has no systemd/cron (PID 1 is tini), so nothing auto-starts. Run:
```bash
/workspace/gmail-listener/start.sh
```
(from a shell that has `COMPOSIO_API_KEY` and `GMAIL_WEBHOOK_KEY` in env, and URL via env or `webhook_url.local`).
Check: `tail listener.log`, `pgrep -af listener.py`. `start.sh` is idempotent.

## Rebuild venv if missing

```bash
cd /workspace/gmail-listener
python3 -m venv venv && ./venv/bin/pip install composio
```

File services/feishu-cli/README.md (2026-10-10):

> 仓库副本（2026-10-10）。**不**备份 `~/.lark-cli/`、`~/.local/share/lark-cli/`、`/workspace/feishu-cli/survey/`、二维码/日志、消息正文。
> 飞书是 **Composio-only 规矩的例外**：Composio 无飞书 toolkit，故用官方 `lark-cli`。

# Feishu (飞书) CLI on this box

## What's installed
- Official CLI: **lark-cli** (npm `@larksuite/cli`, repo https://github.com/larksuite/cli, MIT), version **1.0.97**
- Installed with `npm install -g @larksuite/cli@latest` (user prefix, no sudo)
  - Launcher: `/home/box/.local/bin/lark-cli` (Node wrapper) -> Go binary `/home/box/.local/lib/node_modules/@larksuite/cli/bin/lark-cli`
  - `~/.local/bin` is NOT on the default PATH; it was appended to `~/.bashrc`. In non-login shells use the full path or `export PATH="$HOME/.local/bin:$PATH"`.
- Brand: `feishu` (China mainland, open.feishu.cn). Use `--brand lark` only for Lark international.
- Update: `lark-cli update` or `npm install -g @larksuite/cli@latest`.
- Optional agent skills (not installed): `npx skills add larksuite/cli -y -g`; skills are also readable via `lark-cli skills list/read`.

## Auth model (two layers)
1. **App credentials** (App ID + App Secret of a Feishu self-built app 自建应用) — `lark-cli config init`.
   - `lark-cli config init --new` (what we ran): prints a QR + URL `https://open.feishu.cn/page/cli?user_code=...`; the user
     opens it while logged into Feishu and the platform creates/configures an app for the CLI automatically. Code valid ~10 min.
   - Or bring an existing app: `printf '%s' "$FEISHU_APP_SECRET" | lark-cli config init --app-id "$FEISHU_APP_ID" --app-secret-stdin --brand feishu`
   - Env override also supported: `LARKSUITE_CLI_APP_ID`, `LARKSUITE_CLI_APP_SECRET`, `LARKSUITE_CLI_BRAND`.
   - This alone enables **bot identity** (`--as bot`, tenant_access_token).
2. **User OAuth** (device flow) — `lark-cli auth login --recommend` (or `--domain im,docs,base,approval`, `--scope ...`).
   - Agent mode: `lark-cli auth login --domain ... --no-wait --json` -> returns verification URL + device code; later
     `lark-cli auth login --device-code <CODE>` to finish. Enables `--as user`.
   - Check: `lark-cli auth status`, `lark-cli auth scopes`, `lark-cli doctor`.

## Where config/secrets live
- Config dir: `~/.lark-cli/` (override `LARKSUITE_CLI_CONFIG_DIR`). `lark-cli config show` to inspect.
- Secrets/tokens (Linux, no OS keychain): AES-encrypted files under `~/.local/share/lark-cli/` with a local `master.key`
  (override `LARKSUITE_CLI_DATA_DIR`). Anyone with box access can use them — the box is shared by all bots.

## MCP
- lark-cli itself has no MCP server mode. Official separate MCP server: npm `@larksuiteoapi/lark-mcp` (v0.5.1),
  run via `npx -y @larksuiteoapi/lark-mcp mcp -a <APP_ID> -s <APP_SECRET>` (check its --help; not installed).

## Logs
- `/workspace/feishu-cli/config-init.log` — output of the background `config init --new` run.

## Group chats
- See `chats.md`: 全员群 = oc_1bfe10631cc60ae750bbc378376f3c4d; bot 通知群 = oc_ba1ec97d712cc401cabc3a09c610dcbb (bot cli_aa430b6809f85d0c is a member).

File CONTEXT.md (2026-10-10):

# CONTEXT.md（关于我的共享记忆）

> 所有 bot 共用。换到新的 Grok Bot 账号后，每个 bot 都先读这个文件，再读自己的 `bots/<名字>/CONTEXT.md`。
> 最初由旧号主 bot 在 2026-10-08 导出，之后由每日同步任务维护。时间一律是北京时间（Asia/Shanghai，UTC+8）。
> 写回规则：关于“我”的、所有 bot 都该知道的事写这里；只跟某个 bot 的职责有关的写进它自己的 CONTEXT.md。

## 关于我
- 用中文交流；回答要直接、简短，先给结论。不喜欢绕远路——我说了要用某个方式做（例如“用 Composio 看 GitHub”），就按那个方式做，不要另起炉灶。
- 时区 Asia/Shanghai（UTC+8）。
- 有好几个 Grok Bot 账号，轮换着用，希望换号的成本尽量低（这个仓库就是为此建的）。
- GitHub 账号：`ZMGID`（显示名 ZhiMeng）。个人仓库约 16 公开 + 5 私有，主项目 kivio；还是组织 `dsh-external` 的成员（约 184 个 DSH 相关私有仓库）。
- 邮箱：`ohulercxm8@gmail.com`（仅 **`composio-pg`** / `ca_ZnzYtlTeic0s`）、`zhimeng63@gmail.com`（仅 **`composio-zhimeng`** / `ca_5jGHEthCoWuD`）。
- 常用本地 CLI：Claude Code、Codex、Pi、OpenCode、DSH。
- 评估别人的仓库时更看重 git 时间线和 AI 痕迹，不看功能清单。
- 在做虾皮（Shopee）巴西站选品调研，打算用 agent + Playwright + Shopdora（虾多拉）插件做自动化，而不是紫鸟浏览器（详见 `bots/xiaozhi/CONTEXT.md`）。
- 订阅建议（2026-10-07）：主要用 Grok Bot，建议先订 SuperGrok（$30/月，按月付），不够再升 Plus。

## 项目

### kivio（ZMGID/kivio）
- Tauri 2 + React/Vite/TS 前端 + Rust 后端的桌面 AI 助手，约 585 star。另有仓库 `Dsivio`、`dsivio-plugins`、`dsvideo-plugin`、`fkmem`（Pi 的运行时记忆）。
- **PR #60「feat: Kivio Study 材料学习工作台」**（分支 `feat/kivio-study-cloud`，草稿状态）：2026-10-07 20:48 的提交 `be06640` 修好了 Study browser regression；之后（10-07 20:49 那一轮）CI 和 Study browser regression **全部通过**，没有冲突，还没人 review；live check-mode 验收未过，10/7 后无进展。
- PR #60 的 review 意见：PR 太大（102 个文件、8000+ 行），建议把共用 Chat 的重构拆成单独 PR；迁移旧数据时判断冲突是直接比较两段 JSON 文本，字段顺序一变就可能误判；浏览器测试运行时联网下载真实 PDF，可能随机失败，建议缓存；Rust 测试 `antigravity.rs:497` 有一个不稳定的 OAuth 回调端口检测；工作流里 Node 20 的 actions 已弃用；ChatPanel 测试少一个 mock。
- kivio `main` 9-24 到 10-06 也有 CI 失败（最近一次 10-06 14:05），原因还没细查。
- 其他老 PR：#15「修复 external-agent 会话恢复」（7 月停着）、#8「Linux AppImage 适配基线」（6 月草稿）。

### Dsivio（ZMGID/Dsivio）
- (2026-10-08) 发布 **v1.1.0**（内置 Shopee 调研插件、图片搜 SKU 插件）；发版提交带 `[skip ci]`，release 流水线仍用 Node 20；未经完整 CI。
- `main` CI 自 9 月起一直红：CI 用 Node 20，测试用 `Promise.withResolvers`（Node 22）。**PR #1**（CI/release 升 Node 22）CI 全绿未合并，合并前需 Update branch 重跑完整 CI。
- (2026-10-08) 环境配置优化（同事装环境太慢）：**PR #2**（内嵌 WebView2）、**PR #3**（自带 Python/Node + npmmirror）、**PR #4**（自带工具转接与文档改用 dsivio python）均开出、CI 绿、均未合并。合并顺序建议 #3 → #4，#2 独立；用户计划 10/9 手工继续打磨（当天最重要）。
- (2026-10-08) 新方向 **IM Gateway**（接入企业微信/飞书等消息平台），参考 Hermes Agent；调研报告在共享电脑 `/workspace/dsivio-im/`（不进本仓库）。
- 官网产品页：`https://eastforceglobal.com/dsivio/`（自有服务器 nginx 静态站），10/8 已上线 v1.1.0 页面与安装包（由搭建运维负责；飞书仍未接入）。

### 仿 TourBox 创作控制器（原创设计，不是照抄）——文件在 `projects/creative-controller/`
- ESP32-S3 主控，USB-C 有线 + 蓝牙，1000 mAh 电池；**按 FDM 3D 打印设计**的左手人体工学外壳（约 95×94 mm，软圆方形、前低后高）；KiCad 9 PCB（嘉立创打样）；固件 **v1.1.0**；电脑端配置软件（Python）；BOM、打印说明、审查报告。
- 状态：ERC/DRC 0 错误，固件编译通过，26 颗元件都在嘉立创核对过（约 $12.3/板）。**还没打样，也没在真机上测试。**
- 打印：17 个零件 + 3 个 3MF 打印盘，PETG 0.2 mm 约 8.5 小时、90 g；M2 热熔铜螺母 + M2×14 螺丝；先打公差测试件，松紧不对就改 `mechanical/params.py` 里的 `FDM_CLR` 重新导出。
- 剩余风险 / 下单前待办：
  - **ENC2 滚轮编码器封装是占位的**：嘉立创没货，要单独买 Kailh 或 TTC 鼠标滚轮编码器，买到后核对封装。
  - **板上没有电池保护电路**：必须买带保护板的 603450 锂电池。
  - 下单时在嘉立创贴片预览里**逐个检查 CPL 元件旋转方向**（ESP32 模组尤其要看），清单在 `docs/审查报告.md`。
  - 按键开关 **TS-1102S 库存偏少**（约 1000 个，够 110 台左右），要做就早点下单。
  - 按键行程约 0.25 mm，手感可能偏硬（可换 Choc 矮轴）；按滚轮时滚轮会绕编码器轴略倾斜，需实测。
  - PCB 是自动布线（Freerouting），下单前最好请硬件工程师看一遍。
  - 建议先做 2–5 块板，焊好后进自检模式（插电时按住顶部长键）逐键测试。

## 分工（2026-10-08）

- **小萌**（主 bot / 经理；原名 Grok Bot，slug `grok-bot`，2026-10-08 改名）：分派任务、用 CreateAgent **创建新 bot**；工作日「巡检各 bot」(11:17/15:17)；另有 cloudpotato 来信提醒与 Gmail webhook「gmail-new-mail」。早晚「今日计划 / 今日总结」已移交**事务秘书**。时区 Asia/Hong_Kong（UTC+8）。
- **小枳**：调研（AI / 工具 / 技术规范 / 产品方案）与虾皮（Shopee）选品；活一般由小萌派，只走 Composio。
- **仓库管家**：维护公开仓库 `ZMGID/grokbot-home`，每天 03:14（北京时间）跑同步。
- **代码工程师**：盯 `ZMGID/Dsivio`（主）与 `ZMGID/kivio` 的 CI / 开着的 PR，修代码并开修复 PR；GitHub 只走 composio-pg。
- **搭建运维**：公司官网、飞书及其他系统/工具的搭建与维护（飞书日常可用 lark-cli；搭建配置仍归本 bot）。
- **事务秘书**（原名「邮件秘书」，2026-10-08 改名）：非技术事务（邮件、账号与订阅、周报/文档、提醒、比价等）+ 工作日早晚「今日计划」(08:53) 与「今日总结」(17:47)。**邮件/消息只写草稿，从不直接发送。**
- **硬件工程师**：创作控制器项目（`projects/creative-controller/`）。**(2026-10-08) 项目已暂停、待命**；无用户或小萌新指示不要继续做。
- **财务管家**（2026-10-09 小萌创建）：记账、订阅与固定支出、预算、报销对账、财务材料起草；**只记录，从不付款/转账/下单**。账本在 `/workspace/finance/`。

（2026-10-08 用户已删除 **dr eggbot**；原先「设计并创建 bot」改由主 bot **小萌**自己做。）

## 换号方案（2026-10-08 已确认）
- 所有东西放进 GitHub 仓库 `ZMGID/grokbot-home`（2026-10-08 起改为**公开**，旧私有仓库改名为 `grokbot-home-private-old`）：共享记忆（本文件）、每个 bot 的设定/记忆/定时任务（`bots/`）、连接器清单和启动脚本（`connectors/`）、技能（`skills/`）、工具环境脚本（`setup.sh`）、项目文件（`projects/`）。
- 新号流程：打开一个 Grok Bot，对它说「按 https://github.com/ZMGID/grokbot-home 配置你自己」。它按 `BOOTSTRAP.md` 配好自己，再用 CreateAgent 把其他 bot 全部建出来。
- **明文密钥永远不进仓库**。唯一例外：Composio key 用 `scripts/secret-crypt.py` 加密后放 `secrets/*.enc`；解密口令 `GROKBOT_HOME_PASSPHRASE` 只通过 bot 的密码框（secret prompt）提供。
- Composio 连接走两个自定义 stdio MCP（共用 `~/.composio_pg_key`；**一个 Composio 连接器对应一个 Gmail**）：
  - **`composio-pg`**（用户 `pg-test-5be86c3e-d220-4538-ab6d-ae22d538dfde`）：GitHub ZMGID（`ca_1g4u93YydZsp`）+ Gmail `ohulercxm8@gmail.com`（`ca_ZnzYtlTeic0s`）。**不含** zhimeng63。
  - **`composio-zhimeng`**（用户 `zhimeng63`）：仅 Gmail `zhimeng63@gmail.com`（`ca_5jGHEthCoWuD`）。
  - (2026-10-09) 经用户同意，已从 composio-pg 删除旧的 zhimeng63 连接 **`ca_2rJjmKh8j1q0`**。新号/重建时**不要**再在 composio-pg（pg-test 用户）下给 zhimeng63 授权；只通过 composio-zhimeng 授权。
- (2026-10-08) **应用连接只走 Composio**：不要再装官方 GitHub（`cursor-github`）、Origin、Finance、Composio 插件（32661537）。
- **飞书例外（2026-10-10）**：Composio 无飞书 toolkit → 用官方 **lark-cli** 1.0.97（`npm i -g @larksuite/cli --prefix ~/.local`，brand `feishu`，app `cli_aa430b6809f85d0c`）。配置/token 在 `~/.lark-cli/` 与 `~/.local/share/lark-cli/`（**不进仓库**）。换号后需 `lark-cli config init --new --brand feishu` 与 `lark-cli auth login`（用户扫码）。常用群见 `services/feishu-cli/chats.md`（全员群 / bot 通知群）。
- **Gmail 来信监听（2026-10-10）**：盒子 `/workspace/gmail-listener/`（脚本备份在 `services/gmail-listener/`）经 Composio 触发器推送到小萌 webhook 例程 `gmail-new-mail`。密钥环境变量名 `GMAIL_WEBHOOK_KEY`（**值不进仓库**）。盒子无 systemd，**重启或换号后须手动** `/workspace/gmail-listener/start.sh`。另有 cloudpotato@mail.grokbot.com 邮箱触发例程。
- 同步方式：由专门 bot **仓库管家**每天约 03:14（北京时间）跑定时任务，把各 bot 的新记忆和设定同步进仓库，有变化才推送，推送前做密钥扫描。（2026-10-08 用户改口：原先「不单独建同步 bot、由主 bot 跑」已作废，移交给仓库管家。）
- 新号流程：匿名克隆 → 密码框填一次仓库口令 → 解密 Composio key、装 `composio-pg` + `composio-zhimeng` → 重建各 bot。`gh` 登录只在推送时需要。
- 不做公开分享模板（export-bot-template 只能生成公开模板，不用）。

## Grok Bot 自带邮箱（2026-10-10）
- (2026-10-10) 小萌为用户领了 Grok Bot 邮箱 **`cloudpotato@mail.grokbot.com`**。它绑定在**当前 Grok Bot 账号**上，**无法转移，换号后会丢失**，新号上也不能重新领回同一个地址（每个账号只能领一个，领了不能改）。
- 用途只限可丢弃的事：注册测试账号、收验证码、不重要的往来邮件。重要账号、账单一律留在用户自己的 Gmail。
- 小萌有一个只读的「cloudpotato 来信提醒」自动任务（来信即提醒用户，不回复、不删信），见 `bots/grok-bot/routines.md`。换号后该任务需按新号上的邮箱重建或删除。

## 近期重点（2026-10-10 晚）
- (2026-10-10) 用户定下这几天的三条主线：① kivio（ZMGID/kivio）做 **bot 模式**，并加**版本检查**；② 给 kivio 的 AI 框架定一套 **Rust SDK 标准**；③ 推进 Dsivio：按运营同事日常高频工作写**插件**（先摸清运营日常、列插件候选清单再排序）。前两件用户自评都比较难。
- (2026-10-10) 用户发现 **Monid**（monid.ai）：把各类工具/数据接口集中到一个平台、一个预付余额统一付费（不含大模型；开源的只有 MIT 协议的接口定义和本地引擎）。用户觉得会很有用，待议两个想法：小额试用跑选品数据；借鉴思路给 Dsivio 做「一个 key 通吃」代理。均未决定，笔记在 box 的 `/workspace/assistant/ideas/monid-unified-api.md`。

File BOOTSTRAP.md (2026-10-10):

# BOOTSTRAP — self-setup for a fresh Grok Bot

> **You are a Grok Bot on a brand-new account.** The user (GitHub `ZMGID`) rotates between several Grok Bot accounts and just gave you this repo's link (public repo: `https://github.com/ZMGID/grokbot-home`).
> Follow this file top to bottom to (1) configure yourself, (2) recreate every other bot, (3) verify, and (4) keep the repo up to date.
>
> 中文说明：你是新号上的 Grok Bot。用户把这个仓库链接发给你，意思是“按这里把你自己和其他 bot 都配好”。照下面的步骤一步步做。

**Ground rules / 规则**

- Talk to the user in **Chinese**, short and direct. Times in **Asia/Shanghai (UTC+8)**. 用中文、简短、北京时间。
- **Never put a secret in the repo, in chat, or in a log.** Secrets come only from a masked secret prompt (or 1Password). Never `cat` a key file. 密钥绝不进仓库/聊天/日志。
- Things that need the user: the repo passphrase `GROKBOT_HOME_PASSPHRASE` once (masked secret-request). Only if something fails: the Composio API key itself (masked), or a `gh` device code for push access. No official connector auth clicks. Batch these. 需要用户做的只有在密码框里填一次仓库口令；Composio key 和设备码仅作备用。尽量一次问完。
- Do the steps in order; if a step fails, note it, continue with the rest, and report it in the final checklist. 某步失败就记下来继续，最后汇报。
- The box (`/workspace`, `/home/box`) is shared by all bots on this account, so files you set up are visible to the bots you create.
- Send the user a one-line progress update after each major step (connectors, bots, self-check), not a wall of text.

---

## Step 0 — Clone, passphrase, Composio key, composio-pg + composio-zhimeng / 克隆 → 口令 → 解密 key → 装两个 Composio MCP

This repo is **public**: clone it anonymously, no GitHub login needed. The Composio API key is in the repo **only encrypted** (`secrets/*.enc`); the user gives you the passphrase through a masked secret-request. Official GitHub / Origin connectors are **not** used (all apps via Composio stdio MCPs: `composio-pg` + `composio-zhimeng`). Never print the key, the passphrase, or any token. Never `cat` key files.
仓库是公开的，匿名克隆即可；Composio key 只以加密形式放在 `secrets/`，口令用密码框向用户要。

### (a) Anonymous clone / 匿名克隆

```bash
GIT_TERMINAL_PROMPT=0 git -c credential.helper= clone https://github.com/ZMGID/grokbot-home /workspace/grokbot-home \
  || (cd /workspace/grokbot-home && git pull --rebase)
cd /workspace/grokbot-home
git config user.name ZMGID
git config user.email 214914950+ZMGID@users.noreply.github.com
```

Then read: `README.md`, `CONTEXT.md` (shared user memory), `connectors/README.md`, `bots/README.md`, `bots/index.json`.

### (b) Passphrase → decrypt the Composio key to `~/.composio_pg_key`

1. If `test -s /home/box/.composio_pg_key` already succeeds, skip to (c).
2. Check whether the passphrase is already in the environment (never echo it): `[ -n "$GROKBOT_HOME_PASSPHRASE" ] && echo set || echo missing`.
   If missing, send a **secret-request** (SendToUser type `secret-request`, masked) named **`GROKBOT_HOME_PASSPHRASE`** with a Chinese label, e.g.
   「grokbot-home 仓库的解密口令（GROKBOT_HOME_PASSPHRASE），用来解密 Composio key」. It shows up as an env var in **new** box shells; if the current shell still says `missing`, start a fresh shell (e.g. `bash -lc '…'`). Never ask for it in chat.
3. Decrypt (needs ~1 GiB RAM, a few seconds; prints nothing on success, only a short error on a wrong passphrase):
   ```bash
   cd /workspace/grokbot-home
   python3 scripts/secret-crypt.py dec secrets/COMPOSIO_API_KEY.enc /home/box/.composio_pg_key && chmod 600 /home/box/.composio_pg_key
   ```
   `secrets/COMPOSIO_API_KEY.enc` = the key the user pasted; `secrets/COMPOSIO_API_KEY.box-current.enc` = the key composio-pg was last running on. If the smoke test in (c) fails, decrypt `.box-current.enc` to the same path and retest.
4. Fallback only if decryption fails (wrong passphrase twice / files missing): ask for the Composio project API key itself with a masked secret-request
   「Composio 项目 API key（控制台 → 项目设置 → API Keys），用于 composio-pg；写入 ~/.composio_pg_key」, or have the user type it in **your desktop terminal**:
   `read -rsp 'Composio key: ' K && umask 077 && printf %s "$K" > ~/.composio_pg_key && unset K`. Never in chat.

### (c) Install composio-pg from the repo + smoke test

```bash
command -v uv >/dev/null || curl -LsSf https://astral.sh/uv/install.sh | sh
export PATH="$HOME/.local/bin:$PATH"
mkdir -p /workspace/composio-pg && cd /workspace/composio-pg
install -m 700 /workspace/grokbot-home/connectors/composio-pg/launch.sh .
install -m 600 /workspace/grokbot-home/connectors/composio-pg/launch.py .
[ -x .venv/bin/python ] || uv venv -q .venv
uv pip install -q --python .venv/bin/python "composio==0.25.0" || uv pip install -q --python .venv/bin/python composio
npx -y mcp-remote --help >/dev/null 2>&1 || true    # needs node/npx (present on the box; setup.sh installs it otherwise)
```

`launch.sh` runs `/workspace/composio-pg/.venv/bin/python launch.py`, so the venv above is required. Smoke-test (never print stderr — mcp-remote logs `x-api-key` in clear text):

```bash
timeout 40 /workspace/composio-pg/launch.sh </dev/null >/dev/null 2>/tmp/cpg.err
grep -c "Proxy established successfully" /tmp/cpg.err
rm -f /tmp/cpg.err
```

`1` = OK (`0` → try the `.box-current.enc` key from (b)3, then the (b)4 fallback). Then `AddMcpServer` name **`composio-pg`**, command **`/workspace/composio-pg/launch.sh`** (no args, no env).

### (d) Install composio-zhimeng (zhimeng63 Gmail) + AddMcpServer

Reuses the same `~/.composio_pg_key` and `/workspace/composio-pg/.venv` (no second key file).

```bash
mkdir -p /workspace/composio-zhimeng
install -m 700 /workspace/grokbot-home/connectors/composio-zhimeng/launch.sh /workspace/composio-zhimeng/
install -m 600 /workspace/grokbot-home/connectors/composio-zhimeng/launch.py /workspace/composio-zhimeng/
timeout 40 /workspace/composio-zhimeng/launch.sh </dev/null >/dev/null 2>/tmp/czm.err
grep -c "Proxy established successfully" /tmp/czm.err
rm -f /tmp/czm.err
```

`1` = OK. Then `AddMcpServer` name **`composio-zhimeng`**, command **`/workspace/composio-zhimeng/launch.sh`** (no args, no env) — **after** composio-pg. Verify Gmail read via `user-composio-zhimeng`. If the zhimeng63 Gmail connection is missing on a new account, re-auth with `COMPOSIO_MANAGE_CONNECTIONS` for Composio user **`zhimeng63`** (toolkit gmail), not the pg-test user.

### (e) Gmail listener + webhook key + Feishu lark-cli

**Gmail webhook（小萌例程 gmail-new-mail）**
1. Recreate 小萌's webhook routine **gmail-new-mail** (folder `gmail-new-mail`; prompt in `bots/grok-bot/routines.md`).
2. Ask the user (masked secret-request) for **`GMAIL_WEBHOOK_KEY`** — put it only in the process environment, never in the repo or chat. Env var **name** may be documented; **value** must not.
3. Write the new webhook URL into `/workspace/gmail-listener/webhook_url.local` (`chmod 600`) **or** set env `GMAIL_WEBHOOK_URL`. Never commit `webhook_url.local`.
4. Recreate Composio triggers `GMAIL_NEW_GMAIL_MESSAGE` per user if needed: ohulercxm8 on **composio-pg**, zhimeng63 on **composio-zhimeng** (never put zhimeng63 under pg-test).
5. Restore scripts from `services/gmail-listener/` (`listener.py`, `run_loop.sh`, `start.sh`, `stop.sh`) into `/workspace/gmail-listener/`, build venv if needed, then run `/workspace/gmail-listener/start.sh`.
6. After **every box restart**, run `start.sh` again (no systemd on the box).

**Feishu（lark-cli；Composio 无飞书）**
1. `setup.sh` installs `@larksuite/cli` to `~/.local` (`export PATH="$HOME/.local/bin:$PATH"`).
2. After account switch: `lark-cli config init --new --brand feishu` then `lark-cli auth login` — **user scans QR**.
3. Never copy `~/.lark-cli/`, `~/.local/share/lark-cli/`, or `/workspace/feishu-cli/survey/` into the repo. Group ids: `services/feishu-cli/chats.md`.

## Step 1 — Push access (only for write-back / daily sync) / 推送权限（只有写回和每日同步需要）

Setup itself needs **no** GitHub login. `gh` must be logged in as ZMGID only to **push** (Step 6 `agent-map.json`, Step 9 write-back, 仓库管家's daily sync). Do this after composio-pg works; if it fails, keep going and list it in the report.

**Preferred:** log `gh` in with the GitHub OAuth token Composio already holds (user `pg-test-5be86c3e-d220-4538-ab6d-ae22d538dfde`, toolkit `github` = ZMGID). Pipe it — never echo it or write it to a file:

```bash
/workspace/composio-pg/.venv/bin/python - <<'PY' | gh auth login --with-token
from composio import Composio
key = open("/home/box/.composio_pg_key").read().strip()
client = Composio(api_key=key)
for acc in client.connected_accounts.list(user_ids=["pg-test-5be86c3e-d220-4538-ab6d-ae22d538dfde"]).items:
    d = acc.model_dump() if hasattr(acc, "model_dump") else acc
    toolkit = (d.get("toolkit") or {}).get("slug") if isinstance(d, dict) else None
    if toolkit == "github" and d.get("status") == "ACTIVE":
        tok = (d.get("data") or {}).get("access_token")
        if tok:
            print(tok, end="")
            break
else:
    raise SystemExit("no ACTIVE github connected account")
PY
gh auth setup-git
gh auth status   # should show ZMGID; OK to show the login name, never the token
```

**Fallback:** `gh auth login --hostname github.com --git-protocol https --web` in the background, send the user the one-time code + `https://github.com/login/device`（「请打开这个链接输入验证码，授权 ZMGID（只用于往仓库推送）」）. This is a handoff, not a secret. Do **not** install the official GitHub connector as a substitute.

## Step 2 — Tool environment / 工具环境

```bash
cd /workspace/grokbot-home
nohup bash setup.sh > /tmp/setup.log 2>&1 &
```

- Idempotent; heavy installs (KiCad 9, LibreOffice, PrusaSlicer, cadquery, PlatformIO ESP32 toolchain) can take 10–20 min — run in background, keep going with Step 3, check `/tmp/setup.log` later (the summary at the end lists anything that failed).
- `bash setup.sh --light` skips the heavy CAD/EDA packages if the user only needs the basics.
- It also refreshes `composio-pg` and `composio-zhimeng` launchers from the repo (same as Step 0 (c)(d)); rebuilds composio-pg venv if needed. zhimeng launcher reuses that venv and `~/.composio_pg_key`.

## Step 3 — Connectors / 连接器

Follow `connectors/README.md`. **Rule: app connections through Composio stdio MCPs (`composio-pg` + `composio-zhimeng`), plus Feishu via official lark-cli (exception).** Do **not** install official GitHub (`cursor-github`), Origin, Finance (63408931), or the Composio OAuth plugin (32661537).

| Item | Action | User does |
|---|---|---|
| **composio-pg** | Step 0 (b)(c); AddMcpServer `/workspace/composio-pg/launch.sh` | type the repo passphrase once (masked) |
| **composio-zhimeng** | Step 0 (d) after composio-pg; AddMcpServer `/workspace/composio-zhimeng/launch.sh` | nothing if zhimeng63 Gmail already ACTIVE; else re-auth for user `zhimeng63` |
| **gmail-listener + webhook** | Step 0 (e): recreate triggers; secret-prompt `GMAIL_WEBHOOK_KEY`; `start.sh` | provide webhook key (masked); after box restart expect agent to start listener |
| **飞书 lark-cli** | Step 0 (e): install via setup.sh; `config init` + `auth login` | scan QR twice |
| pstack plugin, **plugin id 9717366** | optional `InstallPlugin` | nothing |
| Official GitHub / Origin / Finance / Composio plugin 32661537 | **skip** | nothing |

Confirm `GetMcpServerStatus`: both `composio-pg` and `composio-zhimeng` connected.
- `user-composio-pg` → `COMPOSIO_MANAGE_CONNECTIONS` `{"toolkits":["github","gmail"]}` (never `reinitiate_all`) → GitHub ZMGID + Gmail ohulercxm8@gmail.com.
- `user-composio-zhimeng` → `COMPOSIO_MANAGE_CONNECTIONS` `{"toolkits":["gmail"]}` → Gmail zhimeng63@gmail.com; fetch 1 recent mail to verify.
If zhimeng63 Gmail is missing: re-auth via `COMPOSIO_MANAGE_CONNECTIONS` for Composio user **`zhimeng63`**.

## Step 4 — Skills / 技能

- `skills/` currently has **no user skills** (see `skills/README.md`). For any `skills/<slug>/` that appears later: copy it to `/home/box/agent-data/workflows/<slug>/` (or create it with the `skill-authoring` skill using the same name and body), then confirm it is listed.
- **pstack** plugin (`InstallPlugin 9717366`) is **optional**（可选，原为 dr eggbot 安装）. Install only if a coding bot needs those skills.
- Managed skills (add-connector, routines, …) come with the platform — nothing to do.

## Step 5 — Apply your own profile (primary bot) / 设置你自己

Primary = `bots/index.json` → `"primary": "grok-bot"`. Read `bots/grok-bot/profile.md`, `bots/grok-bot/CONTEXT.md`.

1. `update_state` target `profile`, action `set`: **name** `小萌` (formerly `Grok Bot`, renamed 2026-10-08; slug stays `grok-bot`), **description** = the exact English text in `bots/grok-bot/profile.md`, title empty.
2. Avatar: no custom image (default shape `blob`, color `black`). If a `bots/grok-bot/avatar.*` file ever exists, set it with `update_state` target `avatar`.
3. If you are not the primary bot, ask the user once whether to make you primary, then `SetPrimaryBot`.
4. Save the important facts from `/CONTEXT.md` + `bots/grok-bot/CONTEXT.md` into your memory (`update_state` target `memory`): user writes Chinese, rotates accounts, GitHub ZMGID, repo `ZMGID/grokbot-home` (public) is the source of truth, no plaintext secrets in the repo (only `secrets/*.enc`), Composio via `composio-pg` + `composio-zhimeng`.
5. If the bot the user opened is **not** the primary (`小萌` / slug `grok-bot`), still act as the bootstrapper: apply `grok-bot`'s profile only if the user agrees; otherwise create `grok-bot` in Step 6 like the others.

## Step 6 — Recreate every other bot / 用 CreateAgent 重建其他 bot

For **each** folder in `bots/` except the primary — driven by `bots/index.json`. Current set (2026-10-09): `xiaozhi`（小枳）, `仓库管家`, `代码工程师`, `搭建运维`, `事务秘书`, `硬件工程师`, `财务管家`. **Do not** recreate deleted `dr-eggbot`.

1. Read `bots/<slug>/profile.md`.
2. Call **CreateAgent** with:
   - **name**: exactly as in profile.md (`小枳`, `仓库管家`, `代码工程师`, `搭建运维`, `事务秘书`, `硬件工程师`, `财务管家`)
   - **title**: as in profile.md (currently empty)
   - **description / instructions**: the text block in profile.md (keep verbatim; xiaozhi's is reconstructed), **plus** this line appended:
     `On your first turn, read /workspace/grokbot-home/CONTEXT.md and /workspace/grokbot-home/bots/<slug>/CONTEXT.md, save the key facts to your memory, then recreate your routines from bots/<slug>/routines.md.`
     （中文可写成：“第一次启动先读 /workspace/grokbot-home/CONTEXT.md 和 bots/<slug>/CONTEXT.md，把要点存进自己的记忆，再按 bots/<slug>/routines.md 重建定时任务。”）
   - avatar: default shape/color from profile.md if CreateAgent accepts it; set an image only if `bots/<slug>/avatar.*` exists.
   - If CreateAgent accepts a first message / task, pass the same “read your CONTEXT.md” instruction there too.
3. Record the new agent id: update `bots/agent-map.json` (`{"<slug>": "<new id>"}`) — needed by the daily sync.
4. Send the user one line per bot created (“已重建 小枳 ✓”).

Do not create the empty “New Bot” from the old account (it was never used). Do not create **dr eggbot** (deleted 2026-10-08); **you (小萌 / primary)** create any new bots going forward.

## Step 7 — Routines / 定时任务

Routines belong to the bot that creates them, so:

- **You (grok-bot / 小萌)**:
  - do **not** create the daily sync (belongs to **仓库管家**);
  - do **not** create morning plan / evening summary (belong to **事务秘书**, handed over 2026-10-08);
  - recreate from `bots/grok-bot/routines.md`:「巡检各 bot」`17 11,15 * * 1-5`; email「cloudpotato 来信提醒」; webhook「gmail-new-mail」(needs listener + `GMAIL_WEBHOOK_KEY`).
- **Other bots**: each recreates its own from `bots/<slug>/routines.md` on its first turn. Match that file:
  - `仓库管家`: daily sync / weekly drill — see `bots/仓库管家/routines.md` (may still use `CRON_TZ=Asia/Shanghai`, same UTC+8).
  - `事务秘书`: morning `53 8 * * 1-5`, evening `47 17 * * 1-5` (plain cron; Asia/Hong_Kong).
  - `xiaozhi` / `代码工程师` / `搭建运维` / `硬件工程师` / `财务管家`: none（暂无）.
- After a few minutes, check each bot did it (ReadTranscript, or ask the user). If a bot can't create routines, create them yourself only if the user agrees.

## Step 8 — Self-check / 自检

Run and record each result:

1. `GetMcpServerStatus`: **composio-pg** and **composio-zhimeng** = connected. Official GitHub / Origin / Finance / Composio plugin should be absent or ignored.
2. `user-composio-pg` → `COMPOSIO_MANAGE_CONNECTIONS` `{"toolkits": ["github", "gmail"]}` (never `reinitiate_all`) → GitHub **ZMGID**, Gmail ohulercxm8@gmail.com.
3. `user-composio-zhimeng` → `COMPOSIO_MANAGE_CONNECTIONS` `{"toolkits": ["gmail"]}` → zhimeng63@gmail.com; fetch 1 recent email to verify.
4. `gh auth status` shows login **ZMGID** (Step 1: Composio token or device-code fallback) — needed only for pushing.
5. Skills: every `skills/<slug>` present in `/home/box/agent-data/workflows/`; pstack optional (only if installed).
6. Bots: every slug in `bots/index.json` exists with the right name; `bots/agent-map.json` updated.
7. Routines: daily sync on **仓库管家**; 事务秘书 morning/evening; 小萌「巡检各 bot」only。
8. Tools: `tail -20 /tmp/setup.log` summary; spot-check `kicad-cli --version` (9.x), `~/.local/bin/pio --version`, `python3 -c "import cadquery"`, `gitleaks version`.
9. Secret scan: `bash scripts/secret-scan.sh` → “干净”.

## Step 9 — Write-back rule / 写回规则（永久）

- New durable knowledge goes back into the right file: about the user → `/CONTEXT.md`; about one bot's work → `bots/<slug>/CONTEXT.md`; profile changes → `profile.md`; routine changes → `routines.md`; connector changes → `connectors/README.md`; new tools → `setup.sh`.
- Then `bash scripts/secret-scan.sh` and `git add -A && git commit -m "<what>" && git pull --rebase && git push origin HEAD:main` (needs Step 1 push access). The daily sync does this automatically for all bots, but write back immediately after anything important.
- Never commit: keys, tokens, the passphrase, `.env`, one-time codes, passwords, auth links, mcp-remote logs, `/home/box/agent-data/*secrets*.json`, databases. **The repo is public** — only `secrets/*.enc` may hold a secret, and only encrypted with `scripts/secret-crypt.py`.
- New bot created later (by **小萌** / primary)? Add `bots/<slug>/` (profile.md, CONTEXT.md, routines.md) + `index.json` + `agent-map.json` + `bots/README.md` table.
- **Never** copy `/workspace/finance/` or `/workspace/assistant/daily/` into the repo. `财务管家` raw memory is skipped by `sync.sh`.

## Step 10 — Report to the user / 最后汇报

Send one short Chinese message: what's done, what failed, what the user still needs to do. Then the checklist below with ✅/❌.

---

## Final checklist / 最终清单

- [ ] Step 0: repo cloned anonymously at `/workspace/grokbot-home`, git identity set
- [ ] Step 0: passphrase received via secret-request; `/home/box/.composio_pg_key` decrypted from `.enc` (or `.box-current.enc`), mode 600 (values never shown)
- [ ] Step 0/3: `composio-pg` + `composio-zhimeng` installed & connected; gmail-listener started; lark-cli auth’d (user QR); `GMAIL_WEBHOOK_KEY` in env only
- [ ] Step 1: `gh` logged in as ZMGID for pushing (Composio GitHub token, or device-code fallback)
- [ ] Step 2: `setup.sh` finished (summary checked; failures listed)
- [ ] Step 3: pstack (9717366) optional（可选，原为 dr eggbot 安装）; official GitHub/Origin/Finance/Composio-plugin **not** installed
- [ ] Step 4: skills imported (currently none) 
- [ ] Step 5: own profile = **小萌** (slug `grok-bot`), primary, memory seeded from CONTEXT.md
- [ ] Step 6: 小枳 / 仓库管家 / 代码工程师 / 搭建运维 / 事务秘书 / 硬件工程师 / 财务管家 created; `bots/agent-map.json` updated & pushed (no dr eggbot)
- [ ] Step 7: daily sync on **仓库管家**; 事务秘书 08:53/17:47; 小萌 巡检 11:17/15:17 only; others per `routines.md`
- [ ] Step 8: composio-pg GitHub+ohulercxm8 + composio-zhimeng zhimeng63 Gmail active; secret scan clean
- [ ] Step 9: write-back rule saved in memory
- [ ] Step 10: user got the summary

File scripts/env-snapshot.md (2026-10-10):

# 工具环境快照（自动生成，2026-10-11 03:25:25 CST）
- kicad-cli: /usr/bin/kicad-cli
- pio: /home/box/.local/bin/pio
- node: /usr/bin/node
- npm: /usr/bin/npm
- npx: /usr/bin/npx
- pnpm: /usr/bin/pnpm
- bun: /usr/local/bin/bun
- gh: /usr/bin/gh
- git: /usr/bin/git
- git-lfs: MISSING
- java: /usr/bin/java
- uv: /usr/local/bin/uv
- cargo: /home/box/.cargo/bin/cargo
- go: /usr/bin/go
- prusa-slicer: /usr/bin/prusa-slicer
- gitleaks: /home/box/.local/bin/gitleaks

## pip --user
- aiohappyeyeballs==2.7.1
- aiohttp==3.14.4
- aiosignal==1.4.0
- ajsonrpc==1.2.0
- anyio==4.15.1
- attrs==26.1.0
- bottle==0.13.4
- cadquery==2.8.0
- cadquery-ocp==7.9.3.1.1
- cadquery-ocp-proxy==7.9.3.1.1
- casadi==3.8.1
- colorama==0.4.6
- contourpy==1.4.0
- cycler==0.12.1
- ezdxf==1.4.4
- frozenlist==1.8.0
- h11==0.16.0
- kiwisolver==1.5.1
- llvmlite==0.50.0
- marshmallow==4.3.1
- matplotlib==3.11.2
- more-itertools==11.1.0
- msgpack==1.2.3
- multidict==6.9.1
- multimethod==1.12
- networkx==3.7
- nlopt==2.11.0
- numba==0.68.0
- platformio==6.2.0
- propcache==0.5.4
- pyelftools==0.33
- pyparsing==3.3.3
- pyserial==3.5
- PyYAML==6.0.3
- runtype==0.5.3
- scipy==1.18.1
- semantic-version==2.10.0
- shapely==2.2.0
- starlette==1.7.0
- tabulate==0.10.0
- trame==4.0.0
- trame-client==4.1.4
- trame-common==1.2.7
- trame-components==2.5.0
- trame-server==4.0.0
- trame-vtk==2.11.17
- trame-vuetify==3.3.0
- trimesh==5.1.1
- uvicorn==0.54.0
- vtk==9.6.2
- wslink==2.5.7
- wsproto==1.3.2
- yarl==1.25.1

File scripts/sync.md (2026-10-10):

# 每日同步任务说明（daily-grokbot-sync）

- **谁跑**：**仓库管家**（2026-10-08 用户改口：单独建同步 bot，由仓库管家跑每日同步；原先「不单独建同步 bot、由主 bot 跑」已作废）。
- **什么时候**：每天约 03:14（北京时间），cron `CRON_TZ=Asia/Shanghai 14 3 * * *`。提示词见 `bots/仓库管家/routines.md`。
- **原则**：有变化才提交推送，没变化不打扰用户；推送前必须通过密钥扫描；任何密钥、验证码、密码、一次性授权链接都不进仓库。

## 每次运行做什么

1. **拉最新**：`cd /workspace/grokbot-home && git pull --rebase`（目录不存在就 `git clone https://github.com/ZMGID/grokbot-home /workspace/grokbot-home`；仓库公开，克隆不需要登录，但**推送需要 `gh` 以 ZMGID 登录**，见 BOOTSTRAP Step 1）。
2. **收集每个 bot 的新记忆**（仓库管家自己做，需要“读懂”）：
   - 本账号所有 bot：`/home/box/agent-data/agents/<id>/`（id ↔ slug 见 `bots/agent-map.json`；出现新的 bot 就新建 `bots/<slug>/` 并加进 `agent-map.json`、`index.json`、`bots/README.md`）。
   - 读上次同步以后的对话：优先用 ReadTranscript（cursor 命名空间，`agent_id`，用 `before` 往前翻页）；没有这个工具时，只读地复制
     `/home/box/agent-data/search-index.db*` 到 `/tmp`，查 `messages` 表（`agent_id`、`timestamp_ms`、`body`）。
   - 把新的**持久**信息合并进 `bots/<slug>/CONTEXT.md`：项目进展、决定、用户新偏好、待办状态变化。写成要点，带日期，不贴大段原文。
   - 关于用户本人、所有 bot 都需要知道的 → 根目录 `CONTEXT.md`。
   - 设定变化（名字、description、头像）→ `profile.md`；定时任务新增/修改/暂停 → `routines.md`。
   - **主 bot（小萌 / slug grok-bot）笔记**：把 `/workspace/assistant/big-picture.md` 复制到 `bots/grok-bot/notes/big-picture.md`；如有需要把 `/workspace/assistant/routines.md` 的定时任务内容同步进 `bots/grok-bot/routines.md`。**绝不**把 `/workspace/assistant/daily/` 拷进仓库。
   - **财务管家账本**：`/workspace/finance/` **绝不**拷进仓库，也不在 CONTEXT/commit message 里摘录金额、账号、卡号、流水。与 daily/ 同级禁忌。
3. **运行 `bash scripts/sync.sh`**，它负责机械部分：
   - 按 `bots/agent-map.json` 把每个 bot 的 `profile.json`、`settings.json`（去掉 serverId）、`memory/`、自定义头像复制到 `bots/<slug>/raw/`；**例外：`财务管家` 跳过 `memory/`**（可能含金额/流水）；
   - 把 `/home/box/agent-data/workflows/` 下的用户技能复制到 `skills/`；
   - 生成 `scripts/env-snapshot.md`（工具环境快照，发现 setup.sh 漏装的东西就顺手补进 setup.sh）；
   - `git add -A` 后运行 `scripts/secret-scan.sh`（gitleaks 工作区 + 历史；rg 模式扫描所有将提交的文件，含隐藏文件；确认 `~/.composio_pg_key`、两份 `secrets/*.enc` 的明文、口令 `GROKBOT_HOME_PASSPHRASE` 都没出现在文件和未推送提交里；`secrets/` 下只能有 `GBH1` 加密文件；**任何已跟踪的 `finance/`、`assistant/daily/` 路径或账本类文件名一律失败**）——**不干净就撤销暂存、中止，不提交**；
   - 没有变化就退出；有变化就 `git commit -m "sync: <时间> Asia/Shanghai"` 并 `git push origin HEAD:main`（被拒会 pull --rebase 后重试一次）。脚本开头会确认 remote 是 `ZMGID/grokbot-home`、分支是 `main`。
4. **连接器清单**：用 GetMcpServerStatus 看当前连接器，和 `connectors/README.md` 对比；有新增/删除/状态变化就更新清单（只写名字、id、地址、步骤）。
5. **汇报**：
   - 没有变化：不发消息。
   - 有变化：在**仓库管家**的聊天里给用户发一行中文摘要（例如“已同步：小枳 CONTEXT +3 条，connectors 新增 Notion”）。
   - 密钥扫描失败 / 推送失败：在聊天里说明原因（只说文件名和行号，不贴内容）。

## 手动跑

```bash
cd /workspace/grokbot-home
bash scripts/sync.sh --dry-run   # 收集文件 + 扫描，显示会提交什么，不提交（收集到的文件留在工作区）
bash scripts/sync.sh             # 正式同步
bash scripts/secret-scan.sh      # 只做密钥扫描
```

## 注意
- 别的 bot 在新号上的 agent id 和旧号不同：BOOTSTRAP 第 6 步建完 bot 后要把新 id 写进 `bots/agent-map.json` 并提交，否则 raw 快照会跳过。
- 不要把 `/home/box/agent-data/` 下的 `box-secrets.json`、`host-secrets.json`、`gateway.json`、`store.db`、`conversation-blobs.db` 复制进仓库。
- 不要把 `/workspace/finance/` 或 `/workspace/assistant/daily/` 复制进仓库；`.gitignore` 已忽略；扫描脚本会拦。
- 不要把 `/workspace/gmail-listener/` 的 `venv/`、`*.log`、`seen.txt`、`forwarded_ids.txt`、`failed.jsonl`、`webhook_url.local` 或 `~/.lark-cli/`、`~/.local/share/lark-cli/`、`feishu-cli/survey/` 复制进仓库。`listener.py`/`run_loop.sh` 可同步（无内嵌密钥）；`webhook_url.local` 永不进仓库。
- 环境变量 `GMAIL_WEBHOOK_KEY` / Composio API key 的**值**永不进仓库（变量名可以写在文档里）。

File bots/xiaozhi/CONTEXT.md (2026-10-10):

# 小枳自己的记忆与项目状态

> 先读根目录 `/CONTEXT.md`。这里是小枳的记忆（旧号 memory/profile.md、memory/log/ 和对话记录整理，2026-10-08 导出；description 于 2026-10-09 由小萌写入线上）。

## 职责（与线上 description 一致）
- 调研：AI / 工具 / 技术规范 / 产品方案，写成可开工要点或文档。
- 虾皮（Shopee）选品：品类、竞品、价格和素材相关调研与整理。
- 需要时用 composio-pg（GitHub / ohulercxm8）与 composio-zhimeng（zhimeng63 Gmail）只读查询；做完简短汇报用户并抄送小萌。
- 不做：分派/新建 bot、Dsivio/kivio 代码与 CI、官网/飞书搭建、事务与早晚报、硬件、grokbot-home。

## 关于用户（小枳记住的）
- (2026-08-21) 用户在共用电脑上拉了 Kivio Desktop（github.com/ZMGID/kivio），本地路径 `/workspace/kivio`，main 分支，当时在做 Linux 适配（ONNX Runtime linux 包、非 macOS overlay 窗口销毁、区域截图 `exclude_self_pid` 参数）。
- (2026-08-21) 常用本地 CLI：Claude Code、Codex、Pi、OpenCode、DSH。
- (2026-08-26) GitHub `ZMGID`（ZhiMeng），个人仓库 15 个（10-08 通过 Composio 看是公开 16 + 私有 5），主项目 kivio；组织 dsh-external 成员（约 184 个 DSH 插件私有仓库）。
- (2026-08-26) 个人其余仓库：私有 wetware、nabai、obsidian-personal-data、Contin；公开 claude-desktop-assistant、Longtxt、ev-charging-optimization、File-Auto-Copy-Tool、openai-gemini；fork claude-tap-kivio、latex-arxiv-SKILL、hermes-agent。近期在改 fkmem（Pi 的运行时记忆）。
- (2026-08-31) 评估别人仓库时更看重 git 时间线与 AI 痕迹，不看功能清单。
- (2026-10-08) 两个 Gmail：ohulercxm8@gmail.com、zhimeng63@gmail.com。邮件里的要点：Anthropic 10-03 以“地区不支持”封了 Claude 账号，申诉和 $88.99 Max 订阅退款都被拒（10-04），已申请数据导出；zhimeng63 有一封 Shopee 巴西邮箱确认（10-07 23:41）还没点。
- (2026-10-08) 用户在 Composio 控制台只有一个项目（`pr_lh5-8poHU4QB`）。曾把“MCP 需要 API 密钥”开关关掉过——已提醒他重新打开。

## 项目与工作记录

### kivio 本地 CLI 适配审查（2026-08-21）
- 已对接 10 个本地 CLI：Claude、Codex、Cursor、OpenCode、Gemini、Kimi、Pi、Hermes、Grok、dsh。
- 协议五路：Claude 走 stream-json，Codex 走 app-server，Pi 走自有 RPC，dsh 走 SDK JSON-RPC，其余（Cursor/OpenCode/Gemini/Kimi/Hermes/Grok）走 ACP。能运行中注入（steer）的只有 Codex、Pi、dsh；能原生 follow-up 的只有 Pi、dsh。
- 当时最高优先级缺口：Grok 0.2.103→1.0.5（默认 Grok 4.6）；Gemini `--experimental-acp` 转正为 `--acp`；dsh-acp 仍不可用（SDK 路径正确，但 rc.8 SQLite 不兼容）。其次：Claude 2.1.220→2.1.238（5 系默认去掉 Todo 工具，未设 `CLAUDE_CODE_ENABLE_TODO_TOOLS`）、Codex 0.149 steer 强制 `expectedTurnId`、Cursor 需接 ask_question/create_plan 且静态模型表已旧；ACP v2 草案不要切。
- 常用五个细查：Claude 2.1.238；Codex 0.149（精选 gpt-5.6 与 live model/list 不一致、initialize 无 experimentalApi）；Pi 0.84.2（steer/follow_up 已接，get_available_thinking_levels 未调）；OpenCode 1.18.20（仍 ACP v1 session/load，兜底模型旧）；DSH 0.1.1-rc.2（SDK+bridge 正确，Kivio 自管 JSON 会话不受 rc.8 SQLite 影响）。
- 结论只做了总结，没改代码。

### 招聘评估：GitHub 用户 biheto（2026-08-31）
- ValuSee 与 DevAgent-Studio（2026-08-08 改名）是同一份 AI 赶出来的毕业作品集：账号 2024-08 注册、到 2026-06 无提交，公开活动从 2026-07-09 开始；作者时间被 GIT_AUTHOR_DATE 整点回填；7 月做治理平台、8 月改成购物产品；8 月 9 日一天 47 个 feat/merge；172 星含牛客求 star，watcher 为 0。
- 给老板的口径：当会用 AI 赶 demo 的实习生面试，不当开源作者；star、两个独立平台、Langflow contributor 都从汇报里拿掉。

### agent 插件/skill 打包调研（2026-09-02）
- 现在的做法是“插件为安装单位，里面多个小 skill 为触发单位”：插件根有 `.claude-plugin/plugin.json`，`skills/<一件事>/SKILL.md`，MCP 用根目录 `.mcp.json`，hooks 也放根上。示例：anthropics/claude-plugins-official 的 plugin-dev（7 个 skill）。
- 加载差异：Claude Code 启动只注入 name+description 目录，匹配或 `/` 调用后把整份 SKILL.md 贴进对话并常驻（references/scripts 不自动进）；Codex 只注入「name: description (file: 绝对路径)」一行，正文不自动灌，插件须写入 marketplace.json。
- Claude Code 插件还能带 commands、agents、hooks、LSP、monitors、themes、workflows、output styles、channels、bin、settings/userConfig/dependencies；Codex 目前只有 skill、MCP、`.app.json`、hooks、assets。

### AI 新闻（2026-10-07）
- 给过一次 AI 新闻速览（OpenAI 一次放出数百个数学结果、Apple 论文“单 agent + shell 胜过多 agent 框架”、Google Playground、DeepSeek 融资等）。用户对“单 agent 胜多 agent”与 Kivio 的关联可能感兴趣。

### 虾皮巴西选品调研 → agent 插件方案（2026-10-07 ~ 10-08）
- 用户发来一份 .doc 操作说明：紫鸟浏览器装虾多拉（Shopdora）插件 → 豆包根据产品图生成巴西电商标题 → 虾皮搜索 → View Product Details 看竞品 → 按 Total Sales / GMV / Price 挑三条（销量最高、居中、价格最低且有销量）填调研表。
- 结论：Shopdora 是 Shopee 数据插件，Chrome/Edge 都能装，不需要紫鸟（紫鸟只用于多店铺防关联）。
- 用户想用 agent 直接驱动 Playwright CLI 并做成给 agent 用的插件。小枳的方案：Playwright 用 Chromium 持久化上下文加载扩展（`launchPersistentContext` + `--load-extension`，有头或新版 headless），插件拆成 title / search / pick / report 四个小 skill，抓取逻辑集中在 `scripts/` 或一个小 MCP（如 `search_products(title)`），选品规则写成固定脚本；风险：虾皮反爬、Shopdora 改版导致选择器失效。还没开始搭骨架，等用户说。
- CSV 不支持嵌图片；要看图用 `.xlsx`（openpyxl 嵌图）或飞书表格。

### Composio 接入（2026-10-08，关键）
- 用户在 Composio 控制台给测试用户 `pg-test-5be86c3e-d220-4538-ab6d-ae22d538dfde` 授权了 GitHub 和两个 Gmail；官方 Composio 插件（OAuth）查的是登录账号自己的 user，所以看不到。
- 用户通过密码框给了 Composio 项目 API key（存在 box 的 `/home/box/.composio_pg_key`，权限 600；**key 本身不在仓库**），小枳写了 `/workspace/composio-pg/launch.py` + `launch.sh`（现在在 `connectors/composio-pg/`），测试通过；后来主 bot 把它作为 `composio-pg` 加到账号里。
- 用户要求：**看 GitHub 也通过 Composio（composio-pg）**。通过它看到：Dsivio main CI 从 9-27 起一直挂（Node 20 vs `Promise.withResolvers`）；kivio main 9-24 ~ 10-06 也有 CI 失败（未细查）；PR #60 最后一轮全过；9 月底 kivio 合并/关闭了 agent todo 工具重构、上下文压缩对齐 ZCode、标题大纲原地展开、外部 CLI 会话“回退到这里”等 PR。
- (2026-10-08) 后续：Dsivio **PR #1**（Node 22）已由代码工程师开出且 CI 全绿、未合并；kivio main 红灯原因仍未细查。

### Dsivio IM Gateway 调研（2026-10-08 ~ 10-09）
- 小萌派活：调研 Hermes IM 网关。确认对象是 Nous Research 的 [Hermes Agent](https://github.com/NousResearch/hermes-agent)（Python）；企业微信与飞书均已内置。桌面端无公网，两边都应走长连接。建议先做企业微信智能机器人（协议公开、可纯 Rust、原生流式），飞书第二；MVP 单平台单聊 + 流式/配对码/重连；IM 发起的对话默认拒绝需审批的工具。报告：`/workspace/dsivio-im/hermes-gateway.md`（不进本仓库）。
- (2026-10-09) 用户问有无现成 SDK：飞书官方 `@larksuiteoapi/node-sdk`（含 `createLarkChannel` 长连接等）、企微官方 `@wecom/aibot-node-sdk`（长连接/流式），均为 Node；Rust 仅有不成熟社区实现。用户决定自己写 Rust，要求整理协议实现手册，明早使用（`/workspace/dsivio-im/rust-impl-guide.md`）。

- (2026-10-09) Gmail `zhimeng63@gmail.com` 改走 **composio-zhimeng**；GitHub 与 ohulercxm8 仍走 composio-pg。

## 教训
- 用户正在按某个方式配置时，不要提供另一套方案（例如重新生成授权链接）。先问清楚、照用户的路子走。
- 不能控制用户电脑上的浏览器时，直接说明并请他截图或复制关键值（例如完整 User ID）。

## 2026-10-09 ~ 10-10
- (2026-10-09) Dsivio IM 网关 Rust 实现手册在 box 的 `/workspace/dsivio-im/rust-impl-guide.md`（两个平台的帧格式、心跳、重连、收发、流式和媒体，字段标了出处）。
- (2026-10-10) 用户嫌 AI 生成的页面全是输入框、没设计感，调研 UI 设计类 skill（含 X 上的推荐）：首推 **Impeccable**（`npx impeccable install`，`/impeccable init` 生成 PRODUCT.md/DESIGN.md，会装改后自动检查的 hook），第二 **shadcn 官方 skill**（`npx skills add shadcn/ui`）配 shadcn/lint，第三 Jakub Krehel skills；建议两者一起用，以 shadcn 主题变量作为唯一色值来源。

## 2026-10-10 晚
- (2026-10-10) 调研 Rust AI 框架：agent/模型调用有 rig（最成熟，未到 1.0）、genai（轻量多模型客户端）、async-openai；MCP 用官方 rmcp；本地推理 mistral.rs / llama-cpp-2 / candle；langchain-rust、llm-chain 已停更勿用；codex-rs 只作参考。对 Dsivio 建议 genai + rmcp 3 自写 agent 循环。
- (2026-10-10) 评估 kivio 自研 AI 内核：判断已达产品级（协议适配、agent 循环、网络层都比通用库完整），**不建议换框架**；可把 kivio 的模型调用层抽成独立 crate 给 Dsivio 用。随后做了一轮细查：严重 3 个、中等 9 个、小问题 5 个，建议修复顺序：Windows 写文件可能丢数据 → Anthropic thinking 回放 → 默认审批改为需确认 → 升级依赖并补齐 CI（clippy/fmt/audit/Windows 构建）→ 密钥迁到 keyring。完整报告在 box 的 `/workspace/kivio-review-report.md`（不进本仓库）；clippy 需用户在 Mac 上跑一次。等用户决定先改哪几条。

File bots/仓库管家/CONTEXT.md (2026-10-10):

# 仓库管家自己的记忆与项目状态

> 先读根目录 `/CONTEXT.md`。这里只记仓库管家自己的工作记录。

## 职责
- 维护公开仓库 `ZMGID/grokbot-home`（本地 `/workspace/grokbot-home`；密钥只以加密形式存在 `secrets/*.enc`；推送前必须过 `scripts/secret-scan.sh`）。
- 跑每日同步定时任务，把本账号各 bot 的新记忆、设定、技能和连接器清单写回仓库。

## 记录
- (2026-10-08) 用户创建本 bot（agent id `5eed9f49-92c0-49b7-8327-2128e99b910b`）。
- (2026-10-08) 用户要求主 bot（Grok Bot）把本仓库的维护（含每日同步）移交给仓库管家；仓库管家已接手。
- (2026-10-08) 在本账号创建定时任务「每日同步 grokbot-home」，cron `CRON_TZ=Asia/Shanghai 14 3 * * *`（每天 03:14 北京时间）。详细做法见 `scripts/sync.md`，脚本 `scripts/sync.sh`。
- (2026-10-08) 每周「换号演练与安全审计」已创建，cron `CRON_TZ=Asia/Shanghai 12 15 * * 0`（周日 15:12）。

## 规矩
- 公开仓库，密钥只以加密形式存在 `secrets/*.enc`（`scripts/secret-crypt.py`，口令在环境变量 `GROKBOT_HOME_PASSPHRASE`）。明文密钥、口令、验证码、密码、一次性授权链接绝不进仓库；推送前必须跑密钥扫描，不干净就中止。旧仓 `ZMGID/grokbot-home-private-old` 不要再往里推。
- 没有变化就不发消息；有变化发一行中文说明改了哪些 bot / 文件。
- 出错时说清原因（只说文件名和行号，不贴可疑内容）。
- (2026-10-09) 每日同步 03:14：合并小枳 IM Gateway 调研与 Dsivio/官网进展进 CONTEXT；刷新 `bots/grok-bot/notes/big-picture.md`；跳过空白 New Bot；connectors 核对（composio-pg ACTIVE；GetMcpServerStatus 不可用，改用命名空间目录）。

- (2026-10-10) 每日同步 03:14：记录小萌领取的 Grok Bot 邮箱 cloudpotato（不可转移）及其来信提醒任务、新仓库 ZMGID/brake-game；合并各 bot 10-09 午后以来进展；第二个空白 New Bot（`52d1b935-…`）暂不登记。

- (2026-10-11) 每日同步 03:22：记录用户近期三条主线与 Monid 想法（根 CONTEXT）、小萌与小枳 10-10 晚进展（Rust 框架调研、kivio 复查）；刷新 big-picture；两个空白 New Bot 已从账号消失，新空白 “Grok Bot”（`04d9635a-…`）暂不登记；GetMcpServerStatus 仍不可用，改用命名空间目录核对连接器。

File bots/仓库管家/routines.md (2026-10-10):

# 仓库管家的定时任务

## 1. 每日同步到 grokbot-home（daily-grokbot-sync）

- **触发**：每天 03:14（北京时间）。cron：`CRON_TZ=Asia/Shanghai 14 3 * * *`
- **状态**：本账号已于 2026-10-08 由仓库管家创建，启用（2026-10-11 核对）。新号上按下面的提示词重建。
- **详细步骤**：见 `scripts/sync.md`，脚本 `scripts/sync.sh`。
- **保存的提示词（重建时用 UpdateRoutine 创建）**：

```text
每日同步 grokbot-home：把本账号所有 bot 的新记忆、设定、技能和连接器清单同步到公开仓库 ZMGID/grokbot-home（本地 /workspace/grokbot-home），并做漂移检查。仓库是公开的：密钥只以加密形式存在 secrets/*.enc（用 scripts/secret-crypt.py 加解密，口令在环境变量 GROKBOT_HOME_PASSPHRASE），任何明文密钥、口令、验证码、密码、一次性授权链接都绝不能进仓库。旧的私有仓库 ZMGID/grokbot-home-private-old 不要再往里推。详细做法以仓库里的 scripts/sync.md 为准，先读它。
1) 确保 /workspace/grokbot-home 是最新的，origin 指向 ZMGID/grokbot-home（git pull --rebase；目录不存在就用 gh 克隆）。
2) 对 bots/agent-map.json 里的每个 bot（包括我自己 仓库管家，以及本账号新出现、还没登记的 bot）：读它自上次同步以来的对话记录和 /home/box/agent-data/agents/<id>/ 下的 profile.json、settings.json、memory/，把新的持久事实、项目进展、决定、偏好写成带日期的要点合并进 bots/<slug>/CONTEXT.md；设定变化写进 profile.md，定时任务变化写进 routines.md；关于用户本人、所有 bot 都该知道的写进根目录 CONTEXT.md。新 bot 要建 bots/<slug>/ 并登记到 agent-map.json、index.json、bots/README.md。因为仓库公开，写进去的内容要当作谁都能看到。
3) Grok Bot 的笔记：把 /workspace/assistant/big-picture.md 复制到仓库 bots/grok-bot/notes/big-picture.md，/workspace/assistant/routines.md 的定时任务内容同步进 bots/grok-bot/routines.md。/workspace/assistant/daily/ 绝不进仓库。
4) 漂移检查：把线上实际情况和仓库逐项对比并补齐：本账号现有的 bot 名单与 agent-map.json、index.json；每个 bot 的名字、标题、说明与 profile.md；每个 bot 的定时任务与 routines.md（我自己的看当前定时任务状态，别的 bot 读不到原文就在 Grok Bot 应用里发消息问那个 bot 要）；/home/box/agent-data/workflows/ 下的技能与 skills/；当前连接器状态与 connectors/README.md；已删除的 bot 要从仓库和 BOOTSTRAP 里去掉。
5) 运行 bash scripts/sync.sh：它会校验 remote 和分支，先做密钥扫描（scripts/secret-scan.sh），不通过就中止、不提交；通过且有变化才 commit + push。绝不绕过、放宽或改白名单来让扫描通过。
6) 结果发给这个聊天里的用户：没有变化就不发任何消息；有变化发一行中文说明（改了哪些 bot / 文件、补齐了哪些漂移）；密钥扫描失败、拉取或推送失败等出错时，说清原因和需要用户做什么（只说文件名和行号，不贴可疑内容），并在 Grok Bot 应用里发消息抄送给 Grok Bot（id a96070f7-cb92-4f15-bcd4-7b1e700cc676）。
```

如果每日同步要读别的 bot 的对话记录，需要有 ReadTranscript 工具（cursor 命名空间）。没有的话退而求其次：读 `/home/box/agent-data/agents/<id>/memory/` 和 `/home/box/agent-data/search-index.db` 的 `messages` 表（只读，先复制到 /tmp 再打开）。

## 2. 换号演练与安全审计

- **触发**：每周日 15:12（北京时间）。cron：`CRON_TZ=Asia/Shanghai 12 15 * * 0`
- **状态**：**已创建**（2026-10-08，由仓库管家在本账号创建），启用；截至 2026-10-11 从未运行。
- **内容概要**（见 profile 职责 3–4）：匿名重克隆公开仓库空跑 BOOTSTRAP；解密校验 `secrets/*.enc`；核对各 bot 文档完整；全历史密钥扫描；遗留风险只提醒。
- **保存的提示词（重建时用 UpdateRoutine 创建）**：

```text
每周换号演练与安全审计（公开仓库 ZMGID/grokbot-home，本地副本 /workspace/grokbot-home）。按我 profile 第 3、4 条做，只演练，不真建任何东西：
1) 换号演练：在 /tmp 下新建临时目录，不带任何登录凭证匿名克隆公开仓库，假装自己是新号上的 bot，按 BOOTSTRAP.md 从头空跑一遍，逐步检查每一步引用的文件、脚本、命令和参数是否存在、是否和现状一致（不新建 bot、不建定时任务、不装连接器）。用环境变量 GROKBOT_HOME_PASSPHRASE 和 scripts/secret-crypt.py 解密 secrets/*.enc，只校验能解开、格式看起来对；解出的明文只放内存或权限 600 的临时文件，用完立刻删除，绝不打印、记录，也绝不写进任何文件或消息。检查 bots/agent-map.json 和 bots/index.json 里的每个 bot 都有完整的 profile.md、CONTEXT.md、routines.md，每条定时任务都有 cron 和提示词原文；setup.sh 能通过 bash -n 语法检查；连接器步骤（composio-pg 启动脚本等）引用的文件都在。
2) 安全审计：对公开仓库的全部 git 历史和工作区跑 scripts/secret-scan.sh 和 gitleaks 全历史扫描，确认没有明文密钥、口令、验证码、一次性链接、邮件正文、/workspace/assistant/daily/ 的内容或其他不该公开的东西。顺便检查遗留风险是否还在：旧私有仓库 ZMGID/grokbot-home-private-old 是否仍存在（里面有明文密钥），口令是否仍然偏短。只提醒，不替用户删仓库或改口令。
3) 发现断点就在 /workspace/grokbot-home 里修好，推送前运行 bash scripts/sync.sh（密钥扫描不干净就中止，绝不放宽扫描或加白名单）；修不了的记下来。演练结束删除 /tmp 下的临时目录。
4) 结果发给这个聊天里的用户：全部正常就只发一句「本周演练通过」，遗留风险仍在时可在同一句后面简短提醒；发现问题或出错时，用简短中文说清是什么问题、已经修了什么、需要用户做什么（只说文件名和行号，不贴可疑内容），并把同样的内容在 Grok Bot 应用里发消息抄送给 Grok Bot（经理 bot，id a96070f7-cb92-4f15-bcd4-7b1e700cc676）。
```

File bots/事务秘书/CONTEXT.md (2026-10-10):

# 事务秘书自己的记忆与项目状态

> 先读根目录 `/CONTEXT.md`。这里只记事务秘书自己的工作记录。

## 职责
- 替用户处理工作里所有**非技术**事务：邮件、账号/订阅/平台事务、周报与文档、日程提醒、询价比价与对外沟通起草等。
- 另负责工作日早晚「今日计划 / 今日总结」定时任务（2026-10-08 自主 bot 小萌接手；**2026-10-10 起**早晚报还覆盖飞书未读消息与待办审批，经官方 lark-cli **只读**：不发消息、不标已读、不审批）。
- 应用连接只走 Composio：`composio-pg`（GitHub / ohulercxm8 Gmail）+ `composio-zhimeng`（zhimeng63 Gmail）。
- **硬规矩（与 profile 一致）：邮件和消息一律不由本 bot 直接发出**；做成草稿卡片给用户看，用户按发送才算数。不自动回复、不标已读、不删除、不退订、不付款、不提交表单（除非用户明确要求）。
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

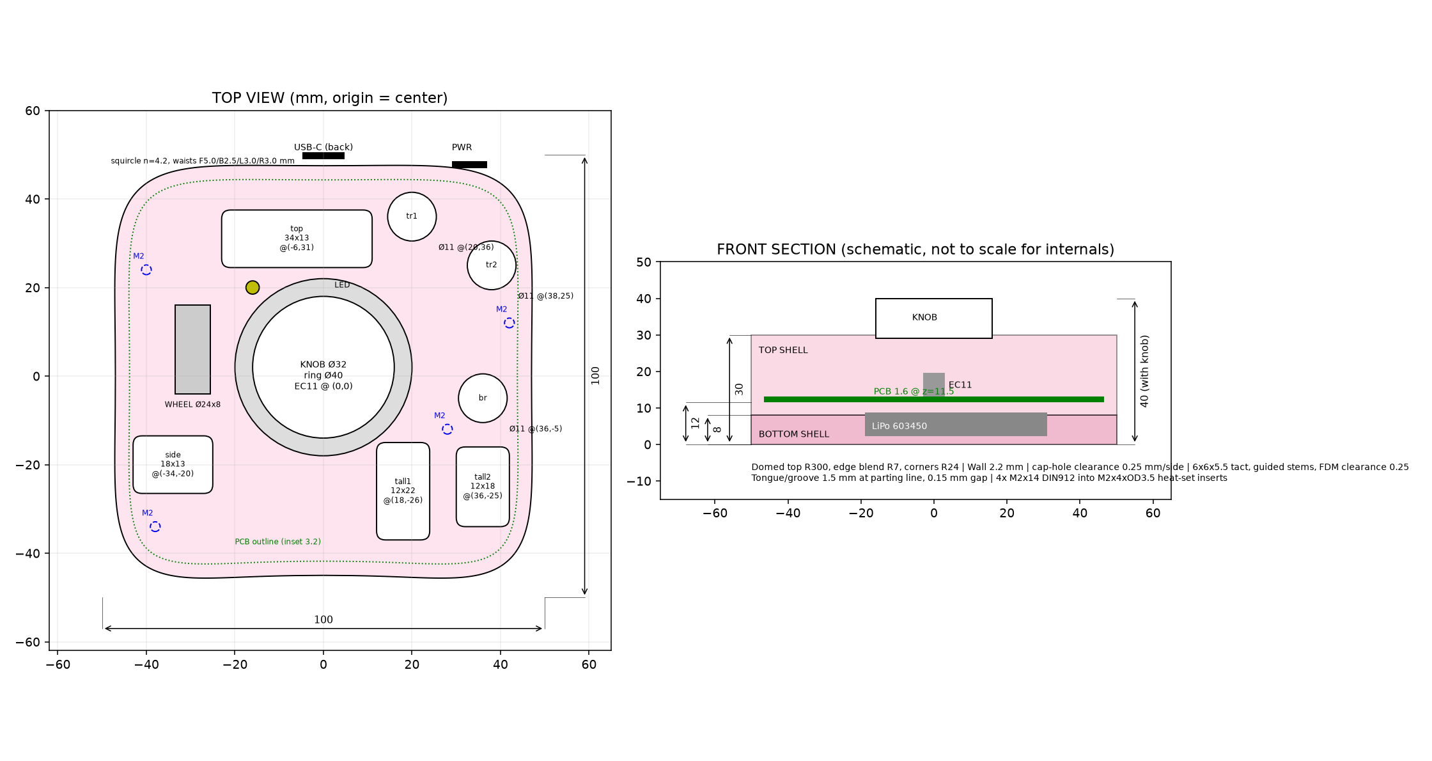
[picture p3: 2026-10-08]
projects/creative-controller/mechanical/drawings/drawing_dimensions.png

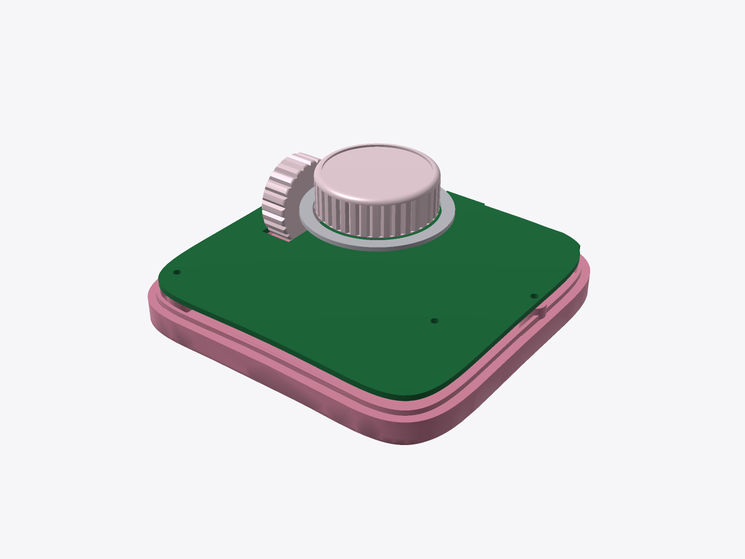
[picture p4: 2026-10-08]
projects/creative-controller/mechanical/drawings/render_internal.png

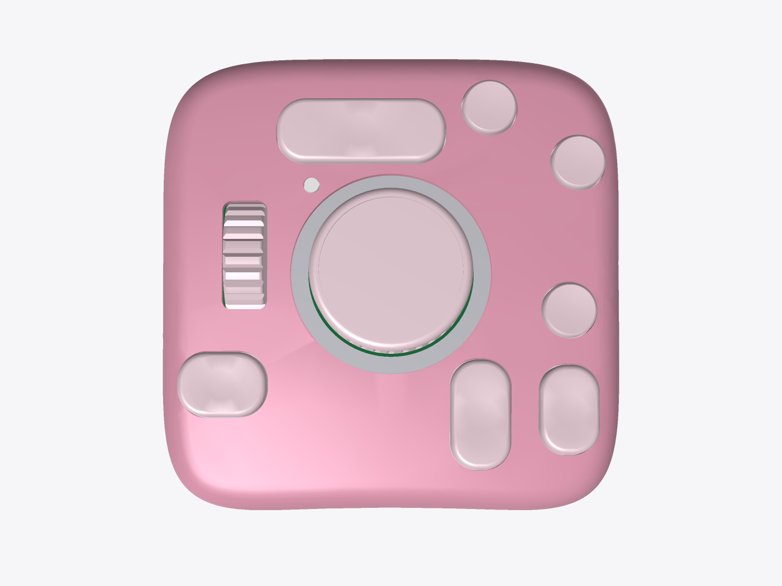
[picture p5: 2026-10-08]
projects/creative-controller/mechanical/drawings/render_top.png

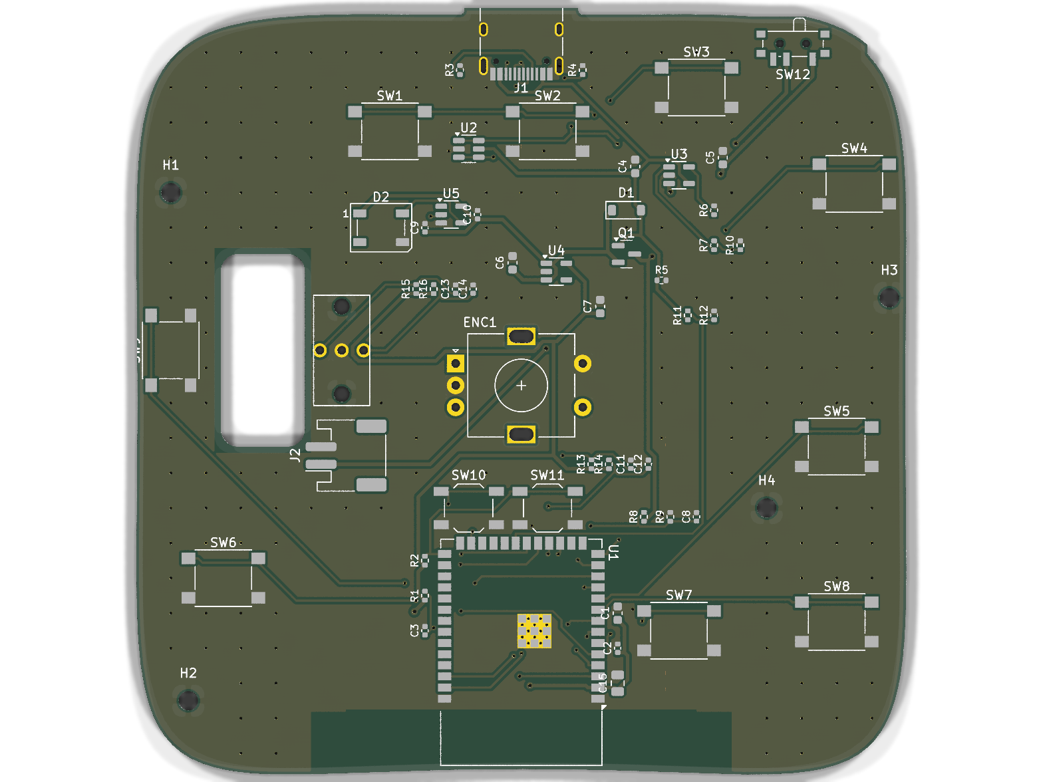
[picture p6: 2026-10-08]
projects/creative-controller/docs/images/pcb_render_top.png

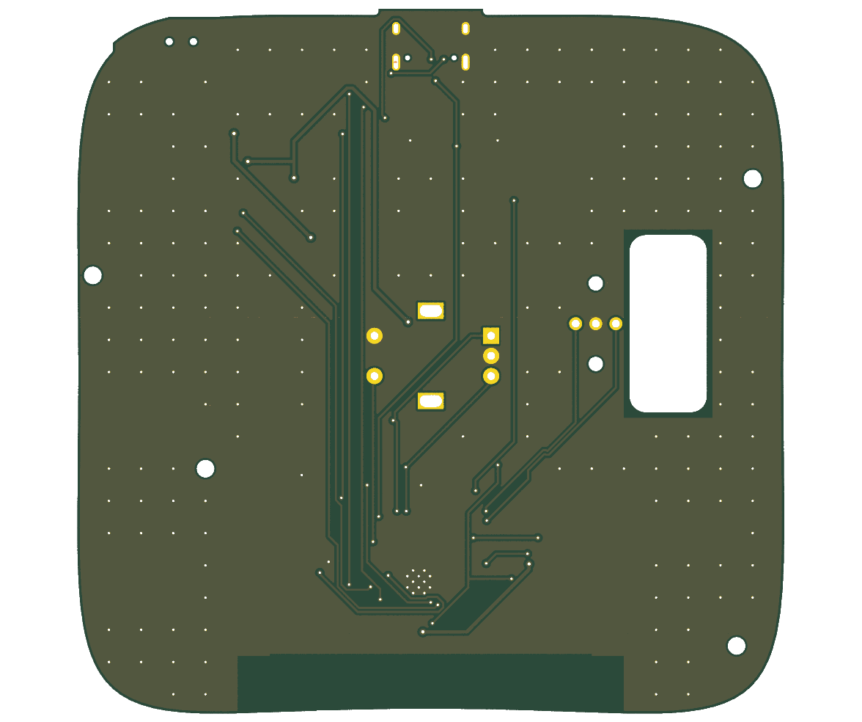
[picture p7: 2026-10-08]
projects/creative-controller/pcb/fab/pcb_render_bottom.png

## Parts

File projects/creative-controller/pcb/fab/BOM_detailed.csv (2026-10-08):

Comment | Designator | Qty | KiCad footprint | LCSC | MPN (JLC) | JLC package | Stock | Type | Unit USD (1+) | Ext USD | Assembly | Checked | Link
ESP32-S3-WROOM-1-N16R8 | U1 | 1 | ESP32-S3-WROOM-1 | C2913202 | ESP32-S3-WROOM-1-N16R8 | SMD,25.5x18mm | 28065 | Extended | 5.1371 | 5.1371 | JLC SMT | 2026-10-08 02:09 | https://www.lcsc.com/product-detail/wifi-modules_espressif-systems-esp32-s3-wroom-1-n16r8_C2913202.html
10uF | C1,C4,C5,C6,C7 | 5 | C_0603_1608Metric | C19702 | CL10A106KP8NNNC | 0603 | 9803287 | Basic | 0.0319 | 0.1595 | JLC SMT | 2026-10-08 02:09 | https://www.lcsc.com/product-detail/multilayer-ceramic-capacitors-mlcc-smd-smt_samsung-electro-mechanics-cl10a106kp8nnnc_C19702.html
100nF | C2,C8,C10,C9 | 4 | C_0402_1005Metric | C1525 | CL05B104KO5NNNC | 0402 | 22193039 | Basic | 0.0045 | 0.018 | JLC SMT | 2026-10-08 02:09 | https://www.lcsc.com/product-detail/multilayer-ceramic-capacitors-mlcc-smd-smt_samsung-electro-mechanics-cl05b104ko5nnnc_C1525.html
22uF | C15 | 1 | C_0805_2012Metric | C45783 | CL21A226MAQNNNE | 0805 | 3925500 | Basic | 0.2202 | 0.2202 | JLC SMT | 2026-10-08 02:09 | https://www.lcsc.com/product-detail/multilayer-ceramic-capacitors-mlcc-smd-smt_samsung-electro-mechanics-cl21a226maqnnne_C45783.html
10k | R1,R2,R13,R14,R15,R16 | 6 | R_0402_1005Metric | C25744 | 0402WGF1002TCE | 0402 | 22127768 | Basic | 0.0034 | 0.0204 | JLC SMT | 2026-10-08 02:09 | https://www.lcsc.com/product-detail/chip-resistor-surface-mount_uni-royal-uniroyal-elec-0402wgf1002tce_C25744.html
1uF | C3 | 1 | C_0402_1005Metric | C52923 | CL05A105KA5NQNC | 0402 | 8511992 | Basic | 0.0107 | 0.0107 | JLC SMT | 2026-10-08 02:09 | https://www.lcsc.com/product-detail/multilayer-ceramic-capacitors-mlcc-smd-smt_samsung-electro-mechanics-cl05a105ka5nqnc_C52923.html
C318884 (RESET/BOOT) | SW10,SW11 | 2 | SW_SPST_TL3342 | C318884 | TS-1187A-B-A-B | SMD-4P,5.1x5.1mm | 450167 | Basic | 0.0205 | 0.041 | JLC SMT | 2026-10-08 02:09 | https://www.lcsc.com/product-detail/tactile-switches_xkb-connection-ts-1187a-b-a-b_C318884.html
TYPE-C-31-M-12 | J1 | 1 | USB_C_Receptacle_HRO_TYPE-C-31-M-12 | C165948 | TYPE-C-31-M-12 | SMD | 419942 | Extended | 0.1857 | 0.1857 | JLC SMT | 2026-10-08 02:09 | https://www.lcsc.com/product-detail/usb-connectors_korean-hroparts-elec-type-c-31-m-12_C165948.html
5.1k | R3,R4 | 2 | R_0402_1005Metric | C25905 | 0402WGF5101TCE | 0402 | 5920486 | Basic | 0.0024 | 0.0048 | JLC SMT | 2026-10-08 02:09 | https://www.lcsc.com/product-detail/chip-resistor-surface-mount_uni-royal-uniroyal-elec-0402wgf5101tce_C25905.html
USBLC6-2SC6 | U2 | 1 | SOT-23-6 | C7519 | USBLC6-2SC6 | SOT-23-6L | 49925 | Extended | 0.1767 | 0.1767 | JLC SMT | 2026-10-08 02:09 | https://www.lcsc.com/product-detail/esd-and-surge-protection-tvs-esd_stmicroelectronics-usblc6-2sc6_C7519.html
B5819W | D1 | 1 | D_SOD-123 | C8598 | B5819W SL | SOD-123 | 453537 | Basic | 0.028 | 0.028 | JLC SMT | 2026-10-08 02:09 | https://www.lcsc.com/product-detail/schottky-diodes_jiangsu-changjing-electronics-technology-co-ltd-b5819w-sl_C8598.html
AO3401A | Q1 | 1 | SOT-23 | C15127 | AO3401A | SOT-23 | 792451 | Basic | 0.1017 | 0.1017 | JLC SMT | 2026-10-08 02:09 | https://www.lcsc.com/product-detail/mosfets_alpha-omega-semicon-ao3401a_C15127.html
100k | R5,R8,R9 | 3 | R_0402_1005Metric | C25741 | 0402WGF1003TCE | 0402 | 8458602 | Basic | 0.0024 | 0.0072 | JLC SMT | 2026-10-08 02:09 | https://www.lcsc.com/product-detail/chip-resistor-surface-mount_uni-royal-uniroyal-elec-0402wgf1003tce_C25741.html
MCP73831T-2ACI/OT | U3 | 1 | SOT-23-5 | C424093 | MCP73831T-2ACI/OT | SOT-23-5 | 4870 | Extended | 0.782 | 0.782 | JLC SMT | 2026-10-08 02:09 | https://www.lcsc.com/product-detail/battery-management_microchip-tech-mcp73831t-2aci-ot_C424093.html
3.3k | R6 | 1 | R_0402_1005Metric | C25890 | 0402WGF3301TCE | 0402 | 2076622 | Basic | 0.0035 | 0.0035 | JLC SMT | 2026-10-08 02:09 | https://www.lcsc.com/product-detail/chip-resistor-surface-mount_uni-royal-uniroyal-elec-0402wgf3301tce_C25890.html
15k | R7 | 1 | R_0402_1005Metric | C25756 | 0402WGF1502TCE | 0402 | 1009473 | Basic | 0.0016 | 0.0016 | JLC SMT | 2026-10-08 02:09 | https://www.lcsc.com/product-detail/chip-resistor-surface-mount_uni-royal-uniroyal-elec-0402wgf1502tce_C25756.html
22k | R10,R11 | 2 | R_0402_1005Metric | C25768 | 0402WGF2202TCE | 0402 | 791296 | Basic | 0.0024 | 0.0048 | JLC SMT | 2026-10-08 02:09 | https://www.lcsc.com/product-detail/chip-resistor-surface-mount_uni-royal-uniroyal-elec-0402wgf2202tce_C25768.html
39k | R12 | 1 | R_0402_1005Metric | C25783 | 0402WGF3902TCE | 0402 | 212317 | Preferred | 0.0024 | 0.0024 | JLC SMT | 2026-10-08 02:09 | https://www.lcsc.com/product-detail/chip-resistor-surface-mount_uni-royal-uniroyal-elec-0402wgf3902tce_C25783.html
PCM12SMTR | SW12 | 1 | SW_SPDT_PCM12 | C221841 | PCM12SMTR | SMD | 11194 | Extended | 1.7834 | 1.7834 | JLC SMT | 2026-10-08 02:09 | https://www.lcsc.com/product-detail/slide-switches_c-k-pcm12smtr_C221841.html
LiPo 3.7V | J2 | 1 | JST_PH_S2B-PH-SM4-TB_1x02-1MP_P2.00mm_Horizontal | C295747 | S2B-PH-SM4-TB(LF)(SN) | SMD,P=2mm,Surface Mount，Right Angle | 16430 | Extended | 0.2364 | 0.2364 | JLC SMT | 2026-10-08 02:09 | https://www.lcsc.com/product-detail/wire-to-board-connector_jst-s2b-ph-sm4-tb-lf-sn_C295747.html
AP2112K-3.3TRG1 | U4 | 1 | SOT-23-5 | C51118 | AP2112K-3.3TRG1 | SOT-25-5 | 34502 | Extended | 0.171 | 0.171 | JLC SMT | 2026-10-08 02:09 | https://www.lcsc.com/product-detail/voltage-regulators-linear-low-drop-out-ldo-regulators_diodes-incorporated-ap2112k-3-3trg1_C51118.html
WS2812B-B | D2 | 1 | LED_WS2812B_PLCC4_5.0x5.0mm_P3.2mm | C2761795 | WS2812B-B/T | SMD5050-4P | 81023 | Extended | 0.1069 | 0.1069 | JLC SMT | 2026-10-08 02:09 | https://www.lcsc.com/product-detail/rgb-leds-built-in-ic_worldsemi-ws2812b-b-t_C2761795.html
SN74LV1T34DBVR | U5 | 1 | SOT-23-5 | C100024 | SN74LV1T34DBVR | SOT-23-5 | 24800 | Extended | 0.3538 | 0.3538 | JLC SMT | 2026-10-08 02:09 | https://www.lcsc.com/product-detail/buffers-drivers-receivers-transceivers_texas-instruments-sn74lv1t34dbvr_C100024.html
10nF | C11,C12,C13,C14 | 4 | C_0402_1005Metric | C15195 | CL05B103KB5NNNC | 0402 | 3905751 | Basic | 0.005 | 0.02 | JLC SMT | 2026-10-08 02:09 | https://www.lcsc.com/product-detail/multilayer-ceramic-capacitors-mlcc-smd-smt_samsung-electro-mechanics-cl05b103kb5nnnc_C15195.html
C53431191 (KEY_TOP/KEY_TR1/KEY_TR2/KEY_BR/KEY_SIDE/KEY_TALL1/KEY_TALL2/KEY_WHEEL) | SW1,SW2,SW3,SW4,SW5,SW6,SW7,SW8,SW9 | 9 | SW_SPST_PTS645 | C53431191 | TS-1102S-6x6x5.5-160 | SMD | 1038 | Extended | 0.0397 | 0.3573 | JLC SMT | 2026-10-08 02:09
EC11E w/ switch 20mm D-shaft | ENC1 | 1 | RotaryEncoder_Alps_EC11E-Switch_Vertical_H20mm | C255515 | EC11E18244A5 | Plugin | 713 | Extended | 2.4028 | 2.4028 | hand-solder (THT) | 2026-10-08 02:09 | https://www.lcsc.com/product-detail/rotary-encoders_alpsalpine-ec11e18244a5_C255515.html
Mouse wheel encoder 11mm (Kailh/TTC) | ENC2 | 1 | MouseEncoder_11mm_3pin | NOT ON LCSC - source Kailh/TTC mouse encoder (Taobao) |  |  |  |  | 0 | 0 | hand-solder (THT)
TOTAL parts (1+ price, excl. PCB/SMT/extended-part fees) |  |  |  |  |  |  |  | 11 extended types |  | 12.34

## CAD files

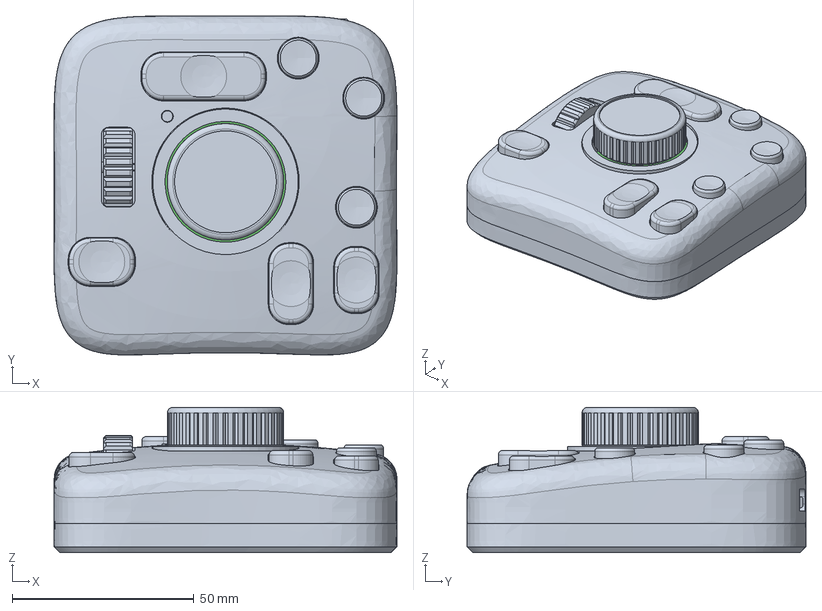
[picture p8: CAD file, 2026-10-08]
projects/creative-controller/mechanical/out/assembly.step
94.3 x 93.2 x 40.0 mm
top_shell
bottom_shell
knob
knob_ring
scroll_wheel
wheel_pin
light_pipe
pwr_slider_ext
cap_top
cap_tr1
cap_tr2
cap_br
cap_side
cap_tall1
cap_tall2
pcb_placeholder

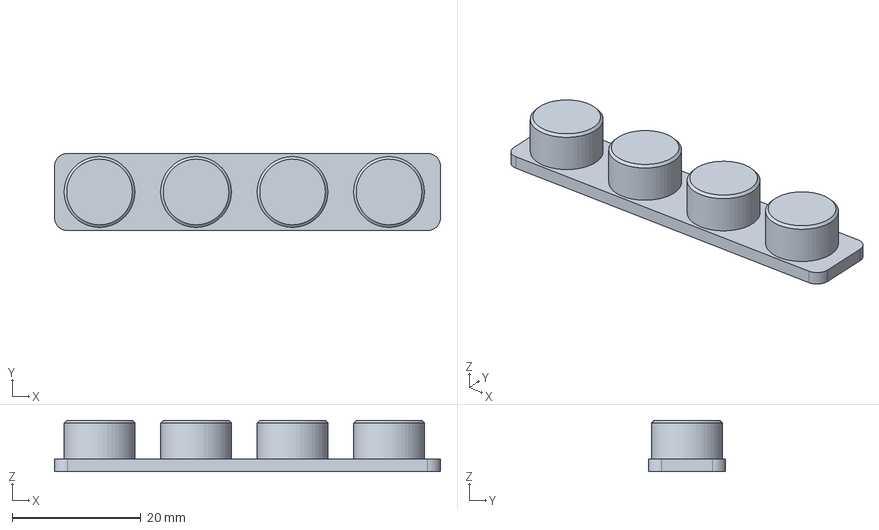
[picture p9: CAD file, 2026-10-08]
projects/creative-controller/mechanical/out/tolerance_test_pegs.step
60.0 x 12.0 x 8.00 mm

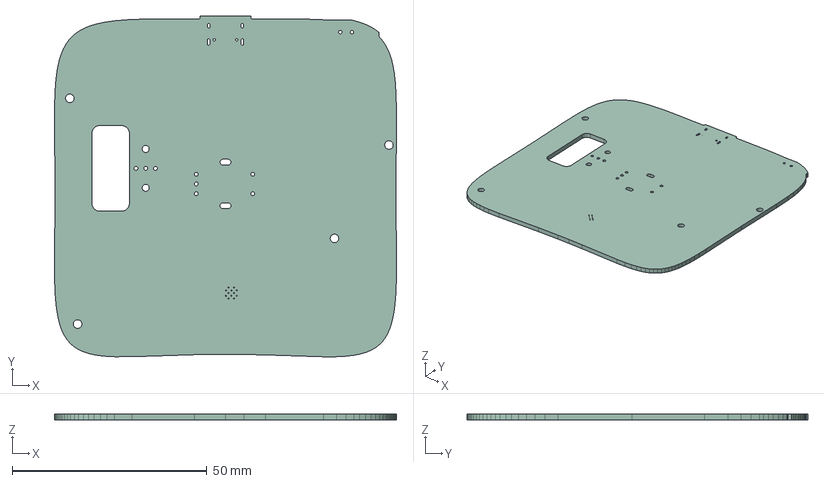
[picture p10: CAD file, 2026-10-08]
projects/creative-controller/pcb/fab/creative-controller-pcb.step
87.9 x 87.5 x 1.51 mm

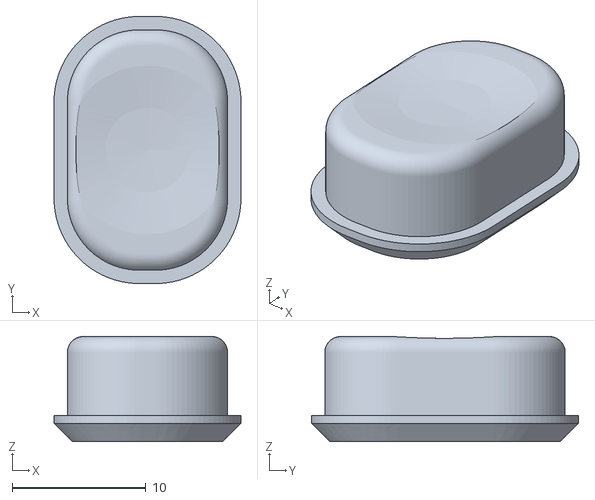
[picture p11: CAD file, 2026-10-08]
projects/creative-controller/print/cap_tall2.stl
14.0 x 20.0 x 7.86

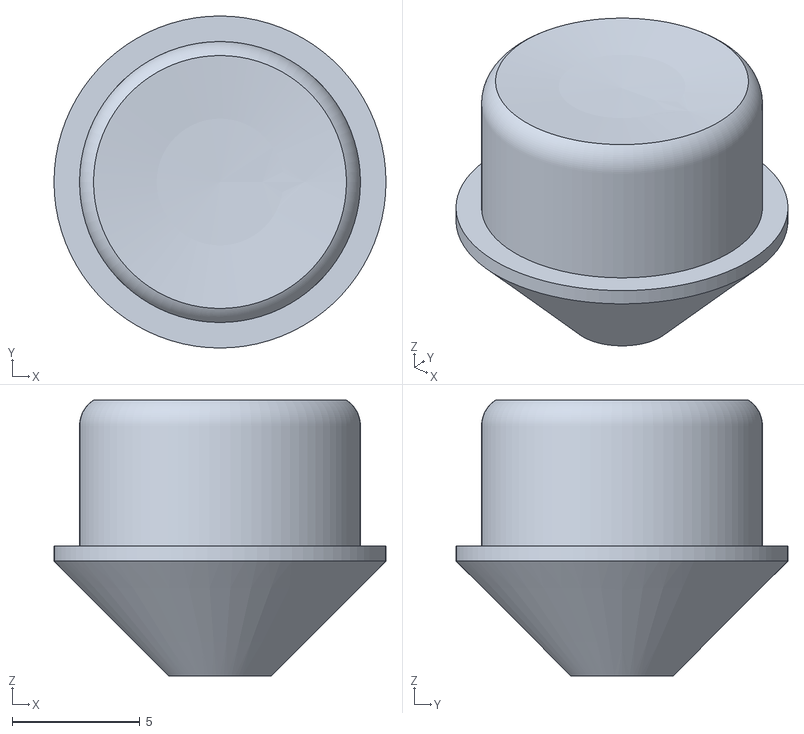
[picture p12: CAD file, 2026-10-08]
projects/creative-controller/print/cap_tr2.stl
13.0 x 13.0 x 10.8

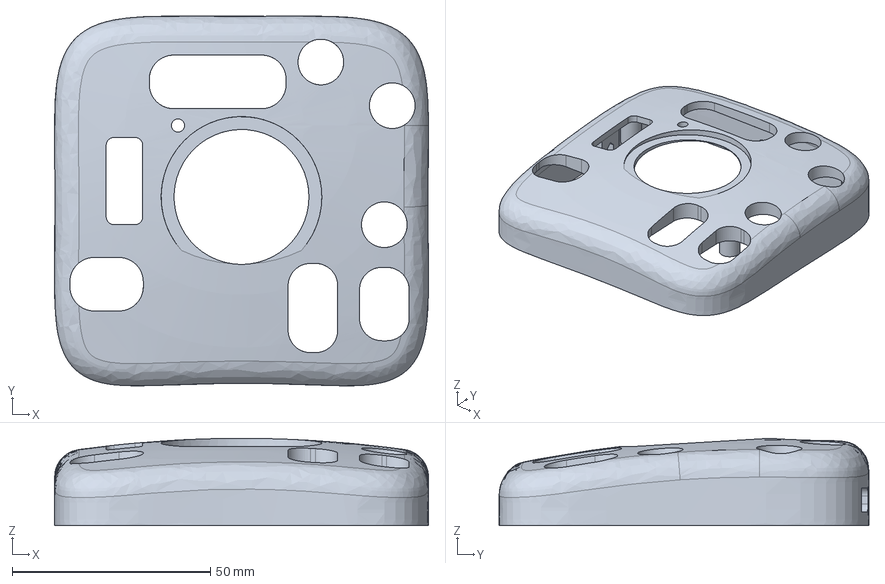
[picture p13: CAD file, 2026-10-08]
projects/creative-controller/mechanical/out/top_shell.step
94.3 x 93.2 x 22.0 mm

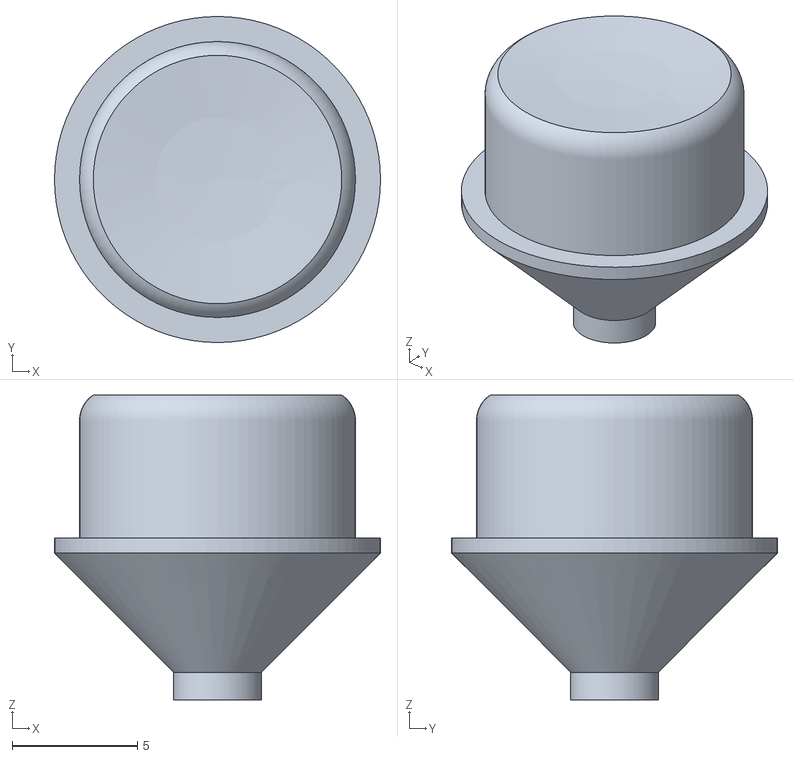
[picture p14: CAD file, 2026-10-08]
projects/creative-controller/print/cap_tr1.stl
13.0 x 13.0 x 12.2

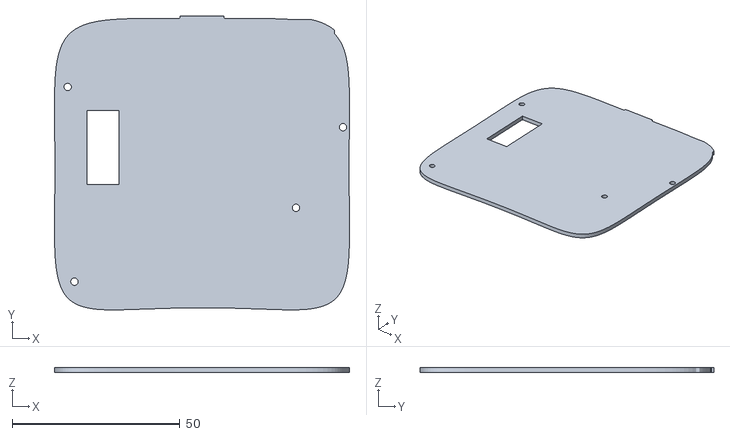
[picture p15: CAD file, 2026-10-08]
projects/creative-controller/mechanical/out/pcb_placeholder.stl
87.9 x 87.5 x 1.60

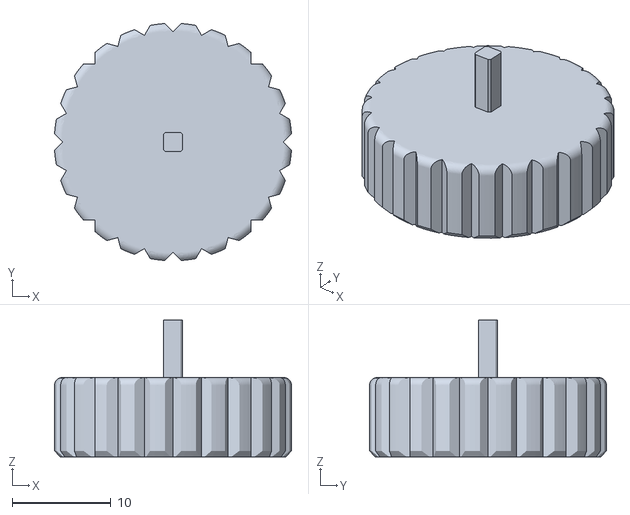
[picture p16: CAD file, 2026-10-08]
projects/creative-controller/print/scroll_wheel.stl
23.9 x 23.9 x 13.8

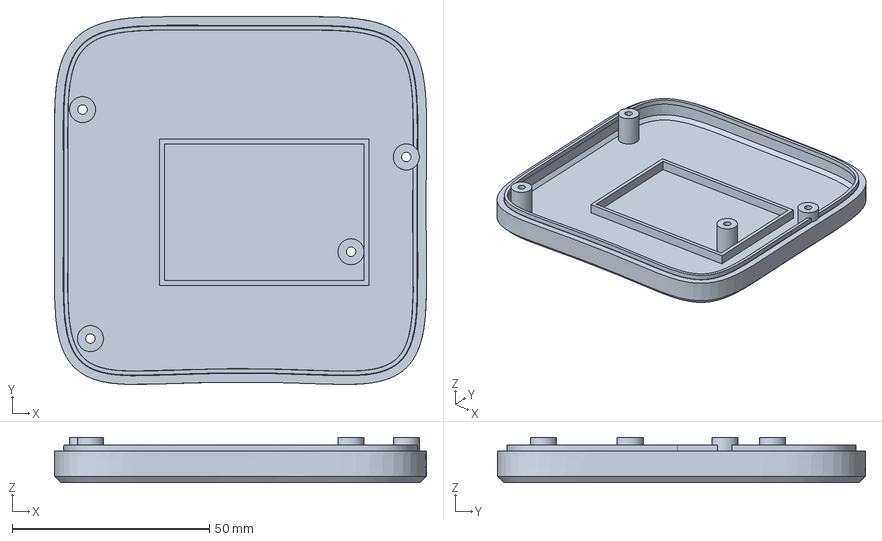
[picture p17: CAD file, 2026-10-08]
projects/creative-controller/mechanical/out/bottom_shell.step
94.3 x 93.2 x 11.5 mm

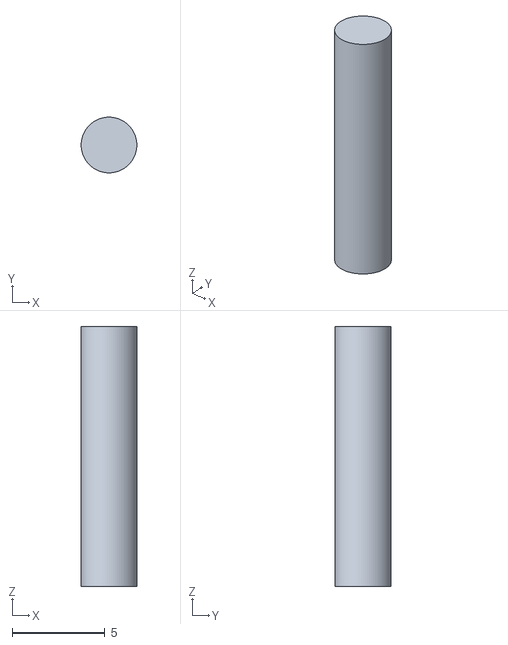
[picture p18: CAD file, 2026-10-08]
projects/creative-controller/print/wheel_pin_optional.stl
3.00 x 3.00 x 14.0

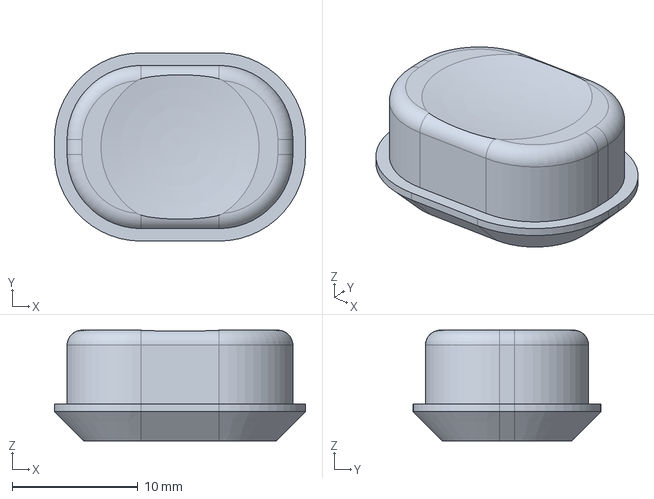
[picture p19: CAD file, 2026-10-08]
projects/creative-controller/mechanical/out/cap_side.step
20.0 x 15.0 x 8.82 mm

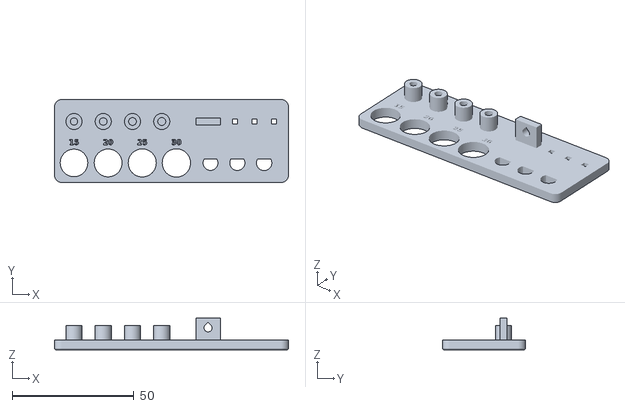
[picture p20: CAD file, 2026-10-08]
projects/creative-controller/print/tolerance_test_plate.stl
96.0 x 34.0 x 13.0

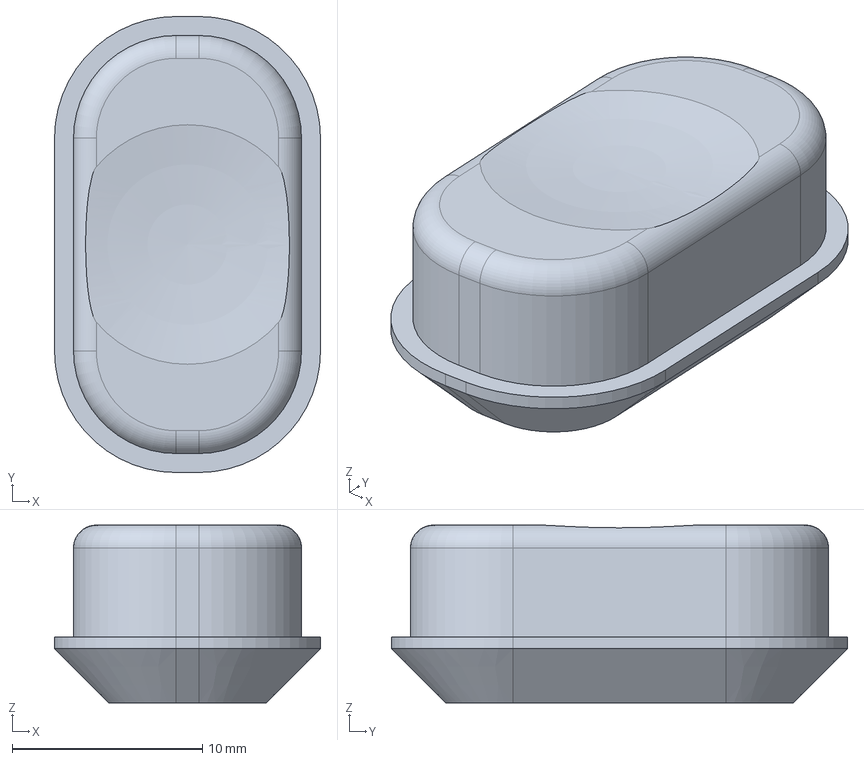
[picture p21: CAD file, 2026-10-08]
projects/creative-controller/mechanical/out/cap_tall1.step
14.0 x 24.0 x 9.36 mm

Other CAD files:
projects/creative-controller/mechanical/out/cap_tall2.step
projects/creative-controller/mechanical/out/wheel_pin.step
projects/creative-controller/print/tolerance_test_pegs.stl
projects/creative-controller/print/bottom_shell.stl
projects/creative-controller/mechanical/out/_wheel_print.stl
projects/creative-controller/mechanical/out/bottom_shell.stl
projects/creative-controller/mechanical/out/cap_br.step
projects/creative-controller/mechanical/out/cap_br.stl
projects/creative-controller/mechanical/out/cap_side.stl
projects/creative-controller/mechanical/out/cap_tall1.stl
projects/creative-controller/mechanical/out/cap_tall2.stl
projects/creative-controller/mechanical/out/cap_top.step
projects/creative-controller/mechanical/out/cap_top.stl
projects/creative-controller/mechanical/out/cap_tr1.step
projects/creative-controller/mechanical/out/cap_tr1.stl
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

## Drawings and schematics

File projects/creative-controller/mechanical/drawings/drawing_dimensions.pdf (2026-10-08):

40

60

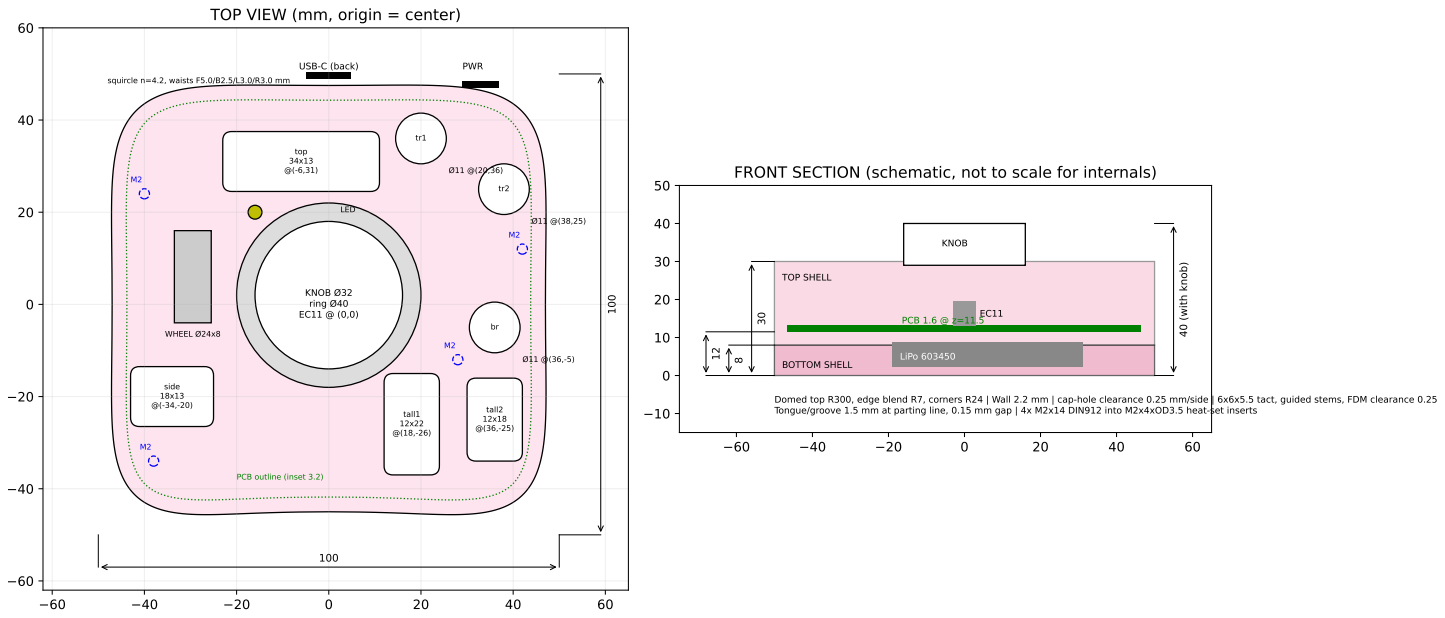
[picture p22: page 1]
BOTTOM SHELL; TOP SHELL; PCB 1.6 @ z=11.5; LiPo 603450; KNOB; 40 (with knob)

TOP VIEW (mm, origin = center)

squircle n=4.2, waists F5.0/B2.5/L3.0/R3.0 mm | | USB-C (back) | | PWR

M2 | | top 34x13 @(-6,31) | tr1 LED | Ø11 @(20,36) tr2

FRONT SECTION (schematic, not to scale for internals)

KNOB Ø32 ring Ø40 | | M2 | Ø11 @(38,25)

WHEEL Ø24x8 side 18x13 | EC11 @ (0,0) | | br M2 | Ø11 @(36,-5)

Domed top R300, edge blend R7, corners R24 | Wall 2.2 mm | cap-hole clearance 0.25 mm/side | 6x6x5.5 tact, guided stems, FDM clearance 0.25
Tongue/groove 1.5 mm at parting line, 0.15 mm gap | 4x M2x14 DIN912 into M2x4xOD3.5 heat-set inserts

M2 | @(-34,-20) | PCB outline (inset 3.2) | tall1 12x22 @(18,-26) | tall2 12x18 @(36,-25)

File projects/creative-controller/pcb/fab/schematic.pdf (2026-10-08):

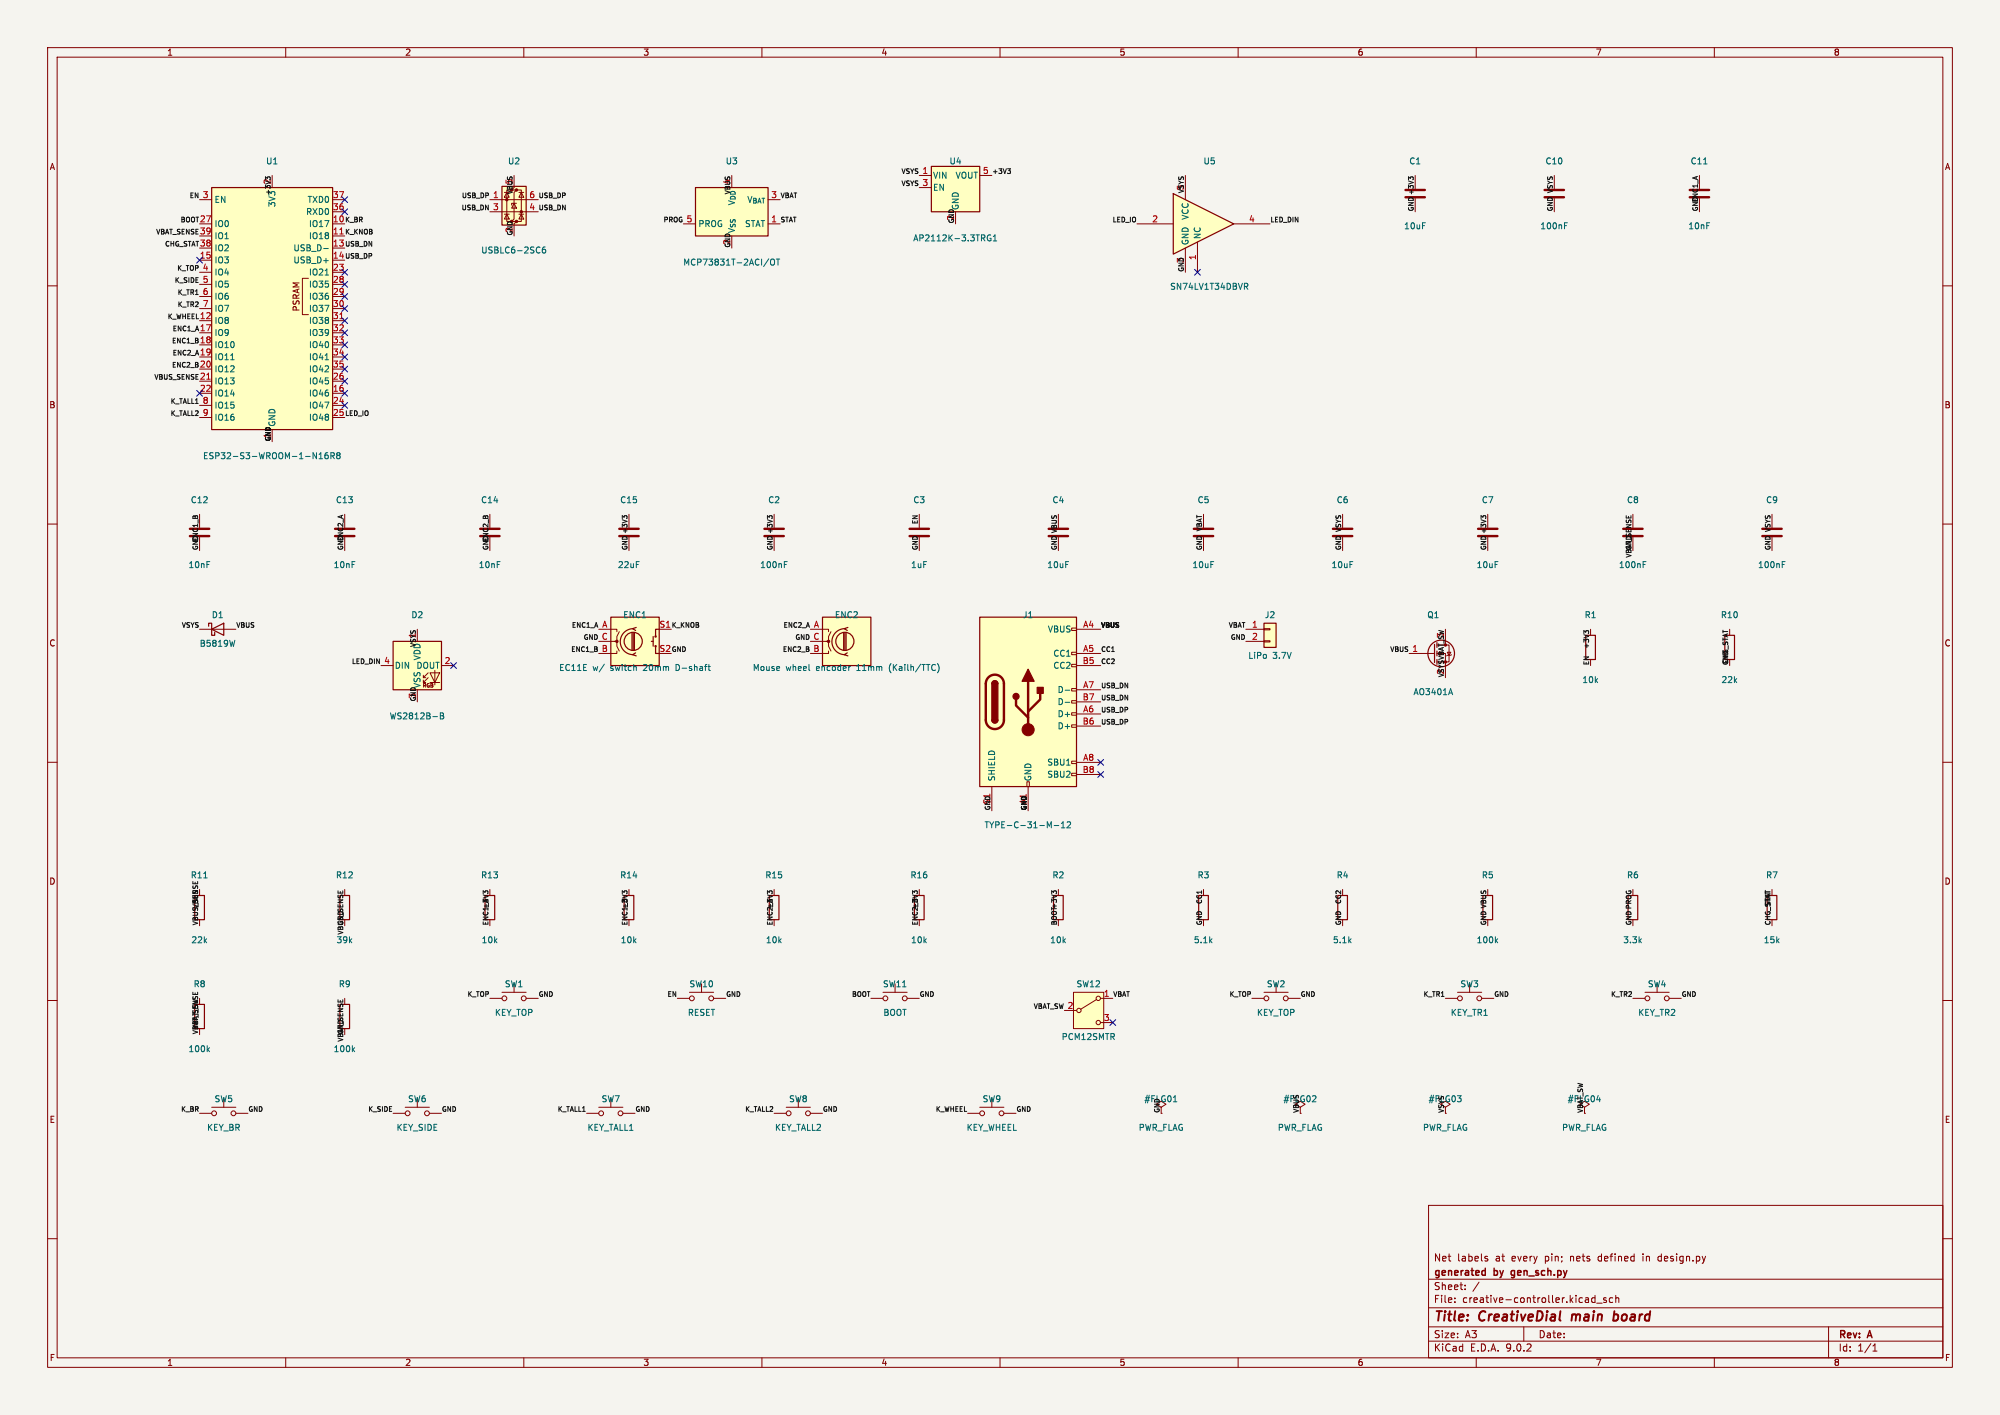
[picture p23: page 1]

ENC2 Mouse wheel encoder 11mm (Kailh/TTC) C2

Id: 1/1 Title: CreativeDial main board

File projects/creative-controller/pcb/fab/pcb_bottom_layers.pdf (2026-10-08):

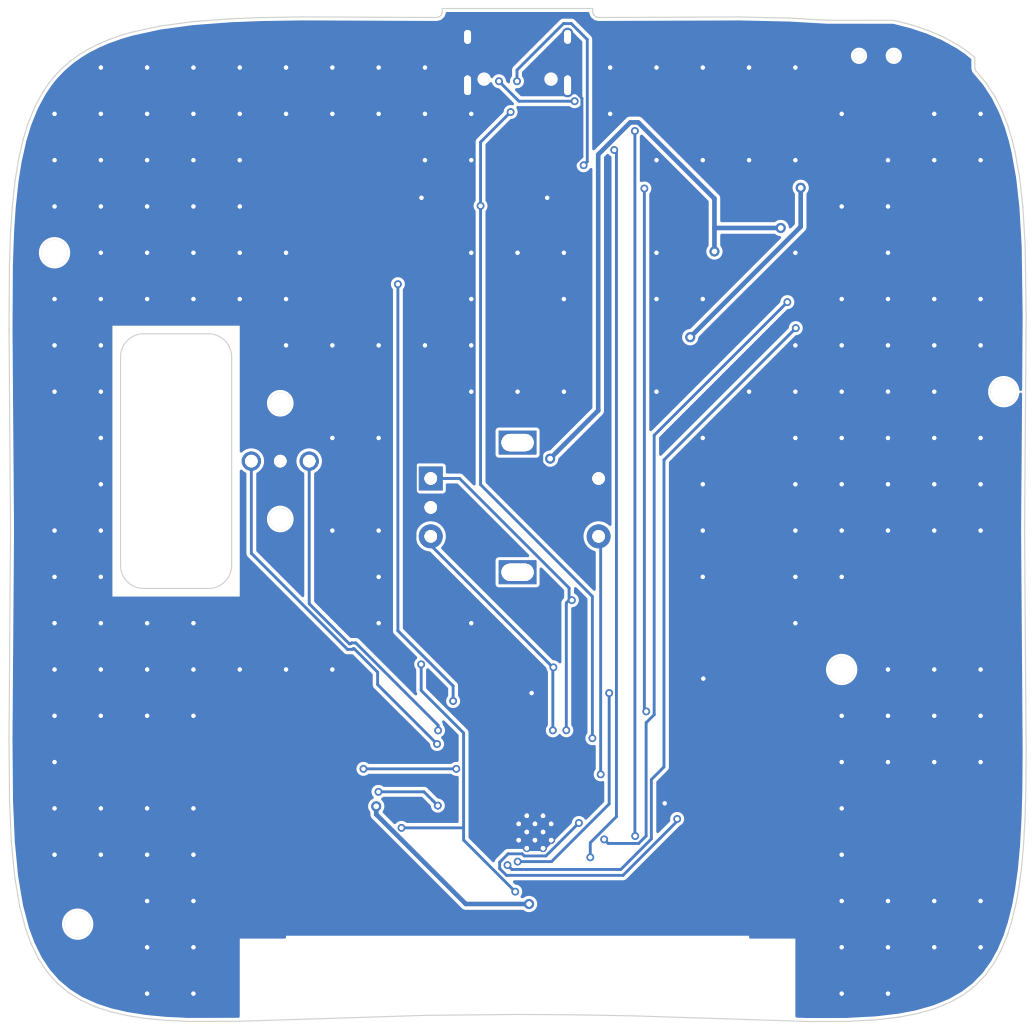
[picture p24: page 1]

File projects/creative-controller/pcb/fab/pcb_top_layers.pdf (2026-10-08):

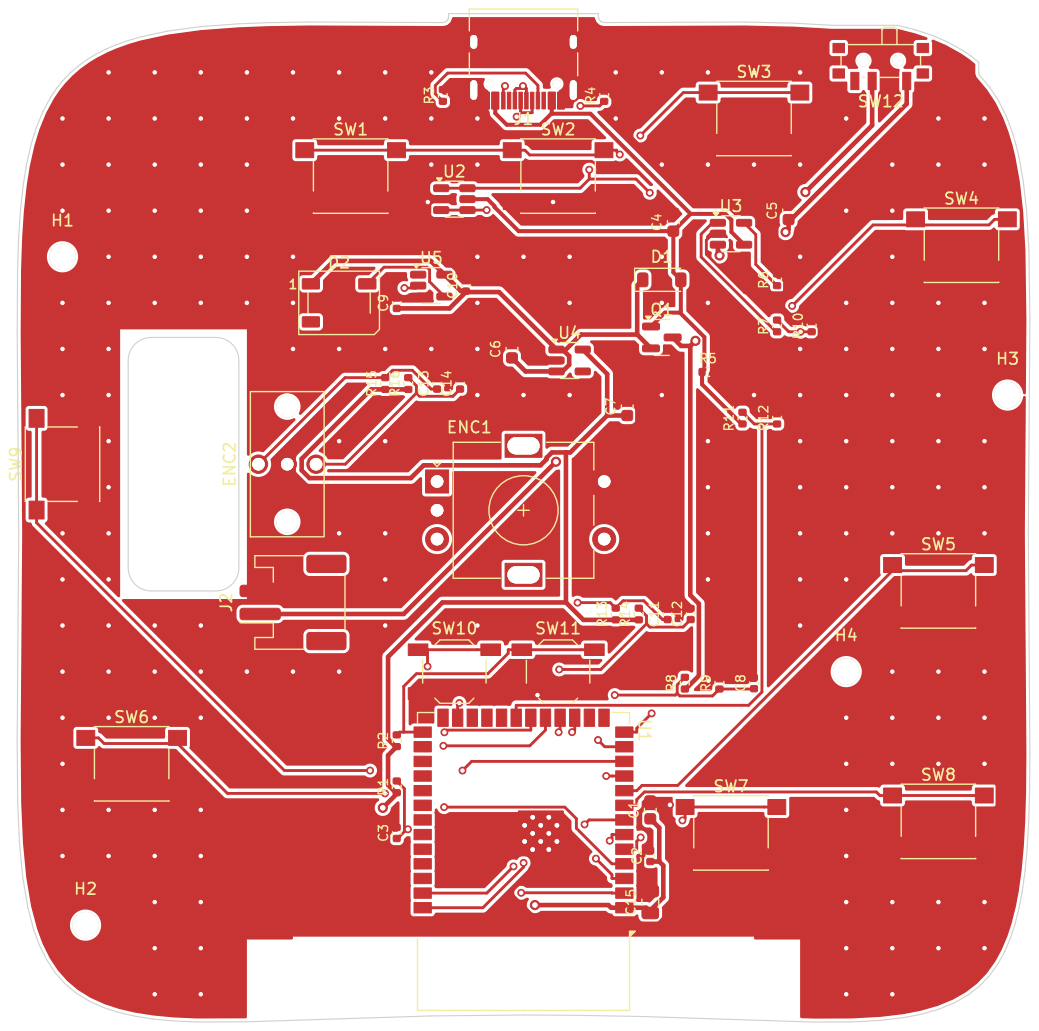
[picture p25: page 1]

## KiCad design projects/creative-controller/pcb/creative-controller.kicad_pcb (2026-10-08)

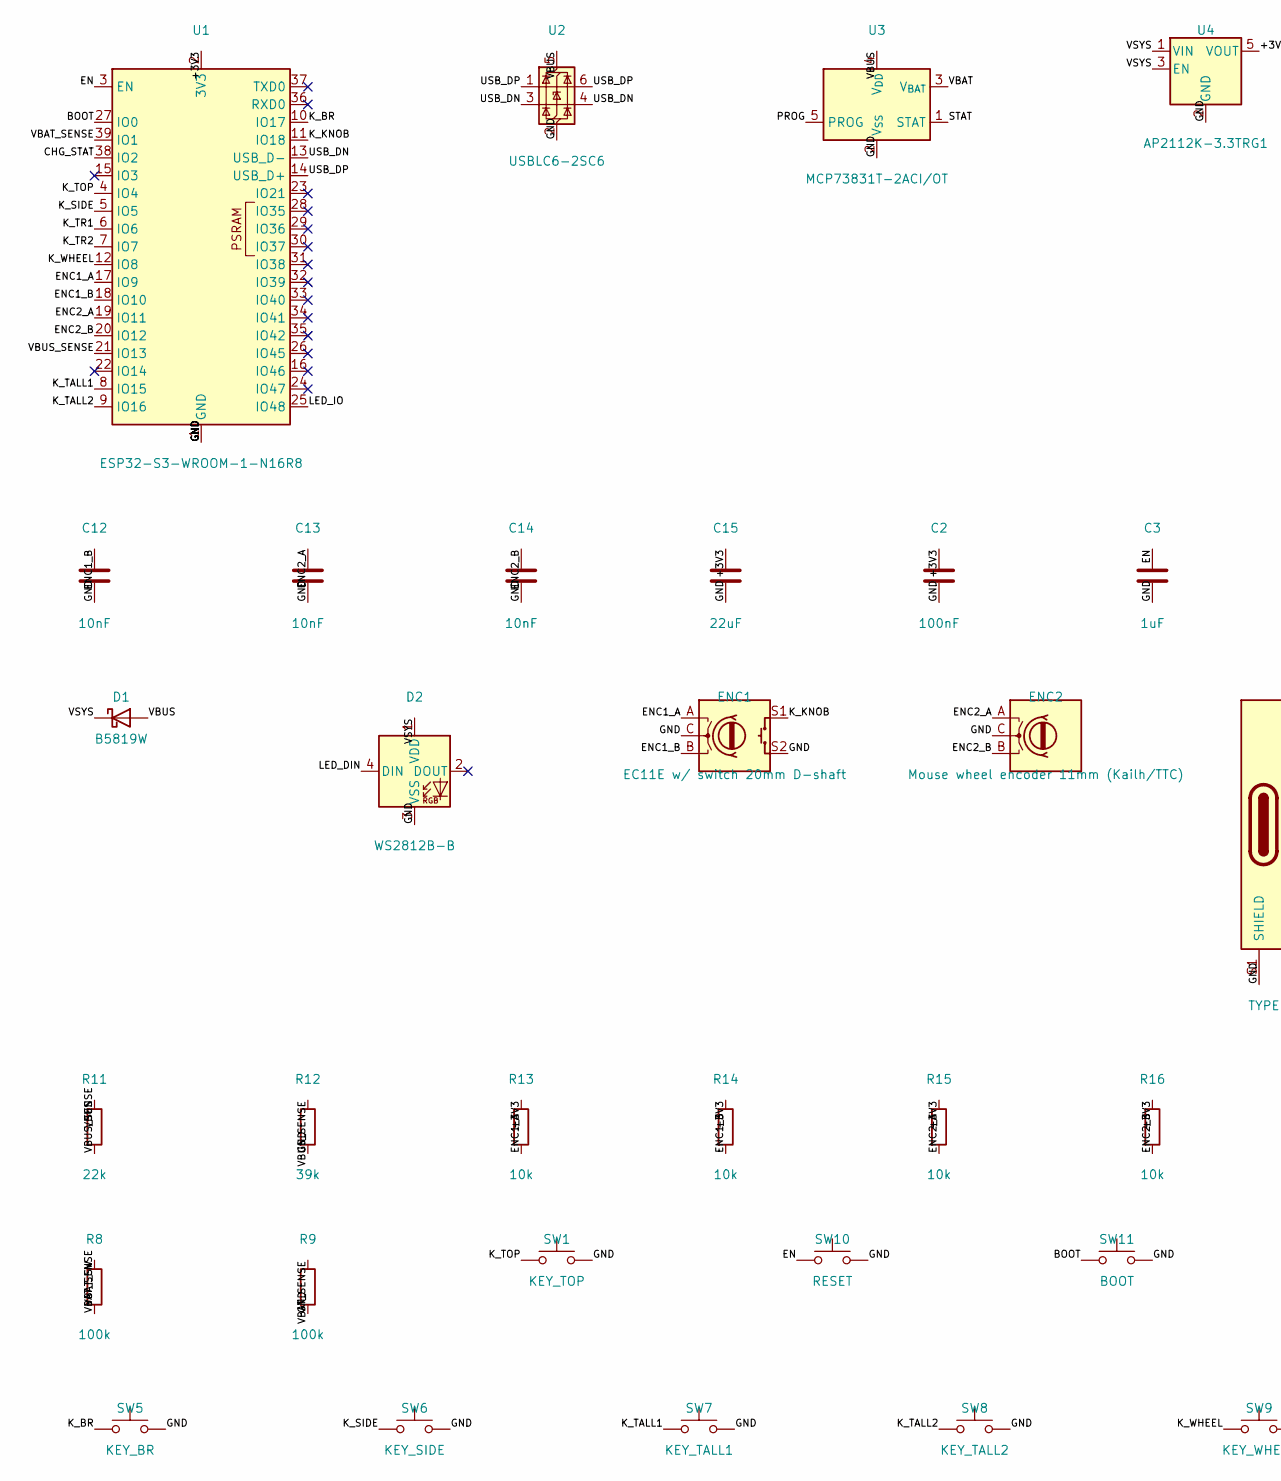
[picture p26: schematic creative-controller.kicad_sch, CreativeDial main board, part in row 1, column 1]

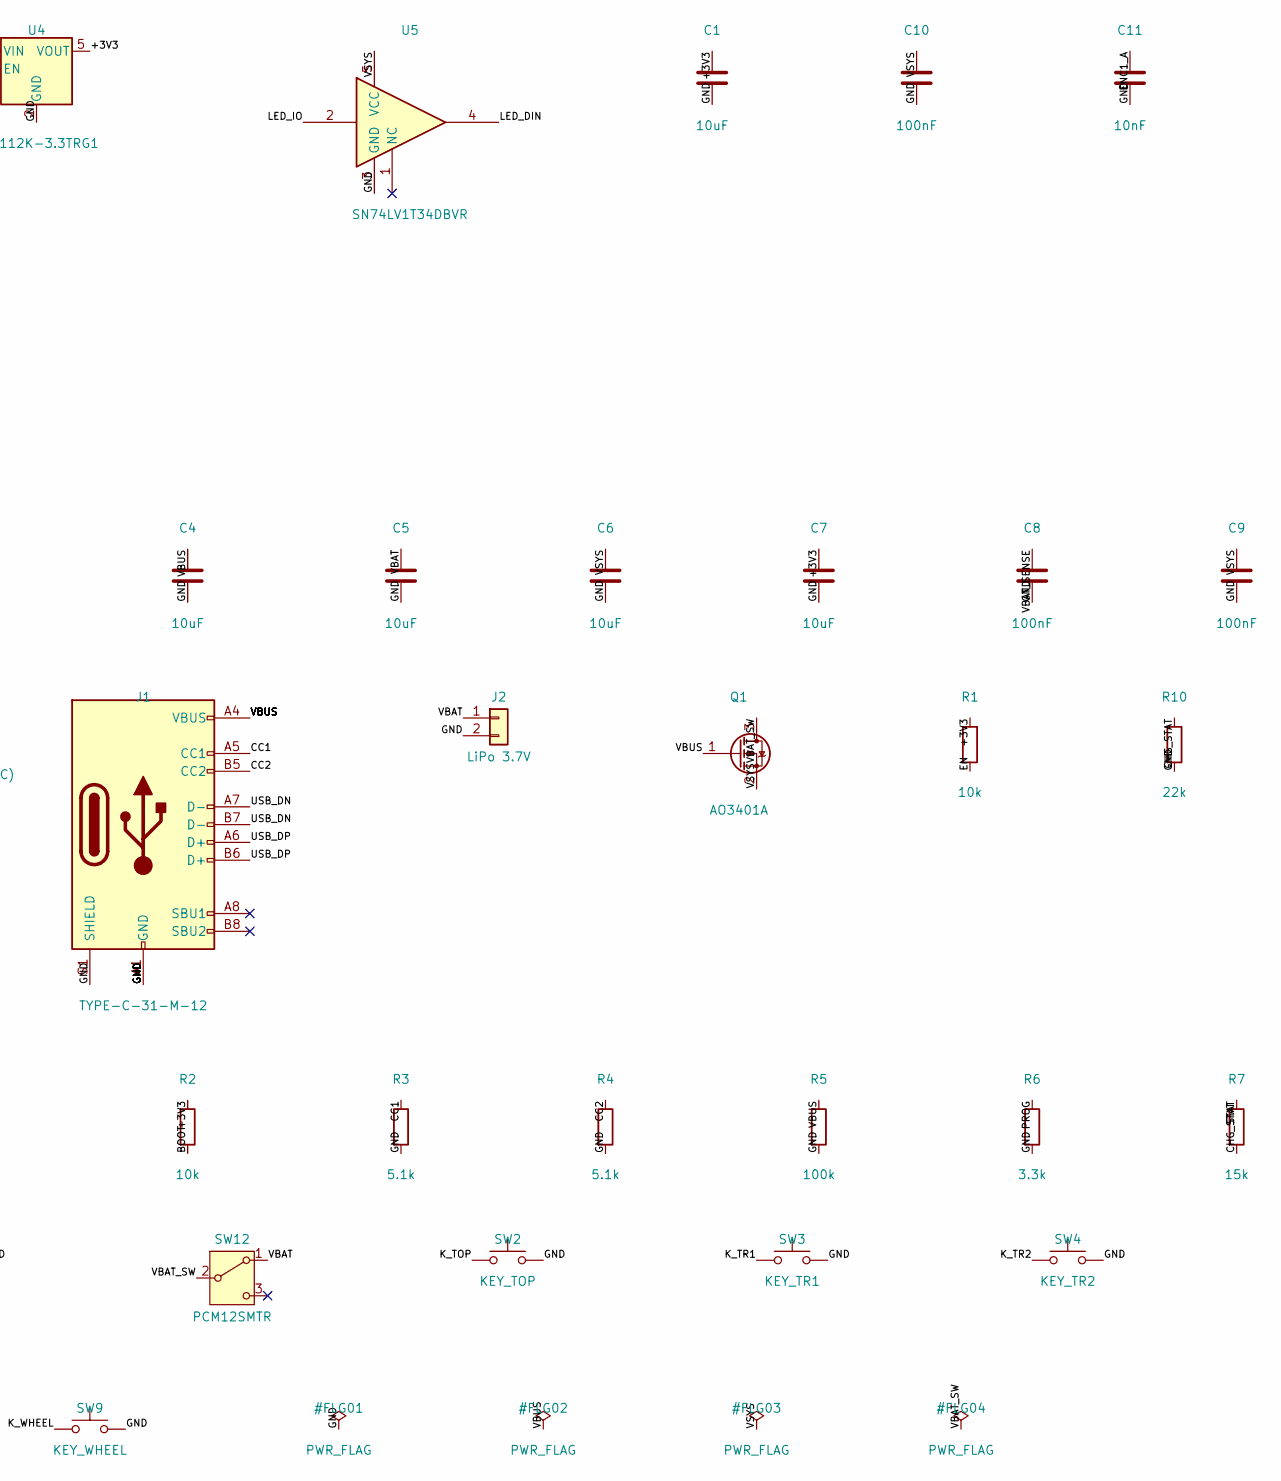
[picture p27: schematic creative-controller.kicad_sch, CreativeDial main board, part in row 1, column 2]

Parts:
C1, C4, C5, C6, C7: 10uF; C_0603_1608Metric; LCSC C19702
C2, C8, C9, C10: 100nF; C_0402_1005Metric; LCSC C1525
C3: 1uF; C_0402_1005Metric; LCSC C52923
C11, C12, C13, C14: 10nF; C_0402_1005Metric; LCSC C15195
C15: 22uF; C_0805_2012Metric; LCSC C45783
D1: B5819W; D_SOD-123; LCSC C8598
D2: WS2812B-B; LED_WS2812B_PLCC4_5.0x5.0mm_P3.2mm; LCSC C2761795
ENC1: EC11E w/ switch 20mm D-shaft; RotaryEncoder_Alps_EC11E-Switch_Vertical_H20mm; LCSC C255515
ENC2: Mouse wheel encoder 11mm (Kailh/TTC); MouseEncoder_11mm_3pin
J1: TYPE-C-31-M-12; USB_C_Receptacle_HRO_TYPE-C-31-M-12; LCSC C165948
J2: LiPo 3.7V; JST_PH_S2B-PH-SM4-TB_1x02-1MP_P2.00mm_Horizontal; LCSC C295747
Q1: AO3401A; SOT-23; LCSC C15127
R1, R2, R13, R14, R15, R16: 10k; R_0402_1005Metric; LCSC C25744
R3, R4: 5.1k; R_0402_1005Metric; LCSC C25905
R5, R8, R9: 100k; R_0402_1005Metric; LCSC C25741
R6: 3.3k; R_0402_1005Metric; LCSC C25890
R7: 15k; R_0402_1005Metric; LCSC C25756
R10, R11: 22k; R_0402_1005Metric; LCSC C25768
R12: 39k; R_0402_1005Metric; LCSC C25783
SW1, SW2: KEY_TOP; SW_SPST_PTS645; LCSC C53431191
SW3: KEY_TR1; SW_SPST_PTS645; LCSC C53431191
SW4: KEY_TR2; SW_SPST_PTS645; LCSC C53431191
SW5: KEY_BR; SW_SPST_PTS645; LCSC C53431191
SW6: KEY_SIDE; SW_SPST_PTS645; LCSC C53431191
SW7: KEY_TALL1; SW_SPST_PTS645; LCSC C53431191
SW8: KEY_TALL2; SW_SPST_PTS645; LCSC C53431191
SW9: KEY_WHEEL; SW_SPST_PTS645; LCSC C53431191
SW10: RESET; SW_SPST_TL3342; LCSC C318884
SW11: BOOT; SW_SPST_TL3342; LCSC C318884
SW12: PCM12SMTR; SW_SPDT_PCM12; LCSC C221841
U1: ESP32-S3-WROOM-1-N16R8; ESP32-S3-WROOM-1; LCSC C2913202
U2: USBLC6-2SC6; SOT-23-6; LCSC C7519
U3: MCP73831T-2ACI/OT; SOT-23-5; LCSC C424093
U4: AP2112K-3.3TRG1; SOT-23-5; LCSC C51118
U5: SN74LV1T34DBVR; SOT-23-5; LCSC C100024

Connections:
/+3V3: C1.1, C2.1, C7.1, C15.1, R1.1, R2.1, R13.1, R14.1, R15.1, R16.1, U1.2 (3V3), U4.5 (VOUT)
/BOOT: R2.2, SW11.1, U1.27 (IO0)
/CC1: J1.A5 (CC1), R3.1
/CC2: J1.B5 (CC2), R4.1
/CHG_STAT: R7.2, R10.1, U1.38 (IO2)
/EN: C3.1, R1.2, SW10.1, U1.3 (EN)
/ENC1_A: C11.1, ENC1.A, R13.2, U1.17 (IO9)
/ENC1_B: C12.1, ENC1.B, R14.2, U1.18 (IO10)
/ENC2_A: C13.1, ENC2.A, R15.2, U1.19 (IO11)
/ENC2_B: C14.1, ENC2.B, R16.2, U1.20 (IO12)
/GND: C1.2, C2.2, C3.2, C4.2, C5.2, C6.2, C7.2, C8.2, C9.2, C10.2, C11.2, C12.2, C13.2, C14.2, C15.2, D2.3 (VSS), ENC1.C, ENC1.S2, ENC2.C, J1.A1 (GND), J1.A12 (GND), J1.B1 (GND), J1.B12 (GND), J1.S1 (SHIELD), J2.2, R3.2, R4.2, R5.2, R6.2, R9.2, R10.2, R12.2, SW1.2, SW2.2, SW3.2, SW4.2, SW5.2, SW6.2, SW7.2, SW8.2, SW9.2, SW10.2, SW11.2, U1.1 (GND), U1.40 (GND), U1.41 (GND), U2.2 (GND), U3.2 (V_{SS}), U4.2 (GND), U5.3 (GND)
/K_BR: SW5.1, U1.10 (IO17)
/K_KNOB: ENC1.S1, U1.11 (IO18)
/K_SIDE: SW6.1, U1.5 (IO5)
/K_TALL1: SW7.1, U1.8 (IO15)
/K_TALL2: SW8.1, U1.9 (IO16)
/K_TOP: SW1.1, SW2.1, U1.4 (IO4)
/K_TR1: SW3.1, U1.6 (IO6)
/K_TR2: SW4.1, U1.7 (IO7)
/K_WHEEL: SW9.1, U1.12 (IO8)
/LED_DIN: D2.4 (DIN), U5.4
/LED_IO: U1.25 (IO48), U5.2
/PROG: R6.1, U3.5 (PROG)
/STAT: R7.1, U3.1 (STAT)
/USB_DN: J1.A7 (D-), J1.B7 (D-), U1.13 (USB_D-), U2.3 (I/O2), U2.4 (I/O2)
/USB_DP: J1.A6 (D+), J1.B6 (D+), U1.14 (USB_D+), U2.1 (I/O1), U2.6 (I/O1)
/VBAT: C5.1, J2.1, SW12.1 (A), U3.3 (V_{BAT})
/VBAT_SENSE: C8.1, R8.2, R9.1, U1.39 (IO1)
/VBAT_SW: Q1.3 (D), R8.1, SW12.2 (B)
/VBUS: C4.1, D1.2 (A), J1.A4 (VBUS), J1.A9 (VBUS), J1.B4 (VBUS), J1.B9 (VBUS), Q1.1 (G), R5.1, R11.1, U2.5 (VBUS), U3.4 (V_{DD})
/VBUS_SENSE: R11.2, R12.1, U1.21 (IO13)
/VSYS: C6.1, C9.1, C10.1, D1.1 (K), D2.1 (VDD), Q1.2 (S), U4.1 (VIN), U4.3 (EN), U5.5 (VCC)

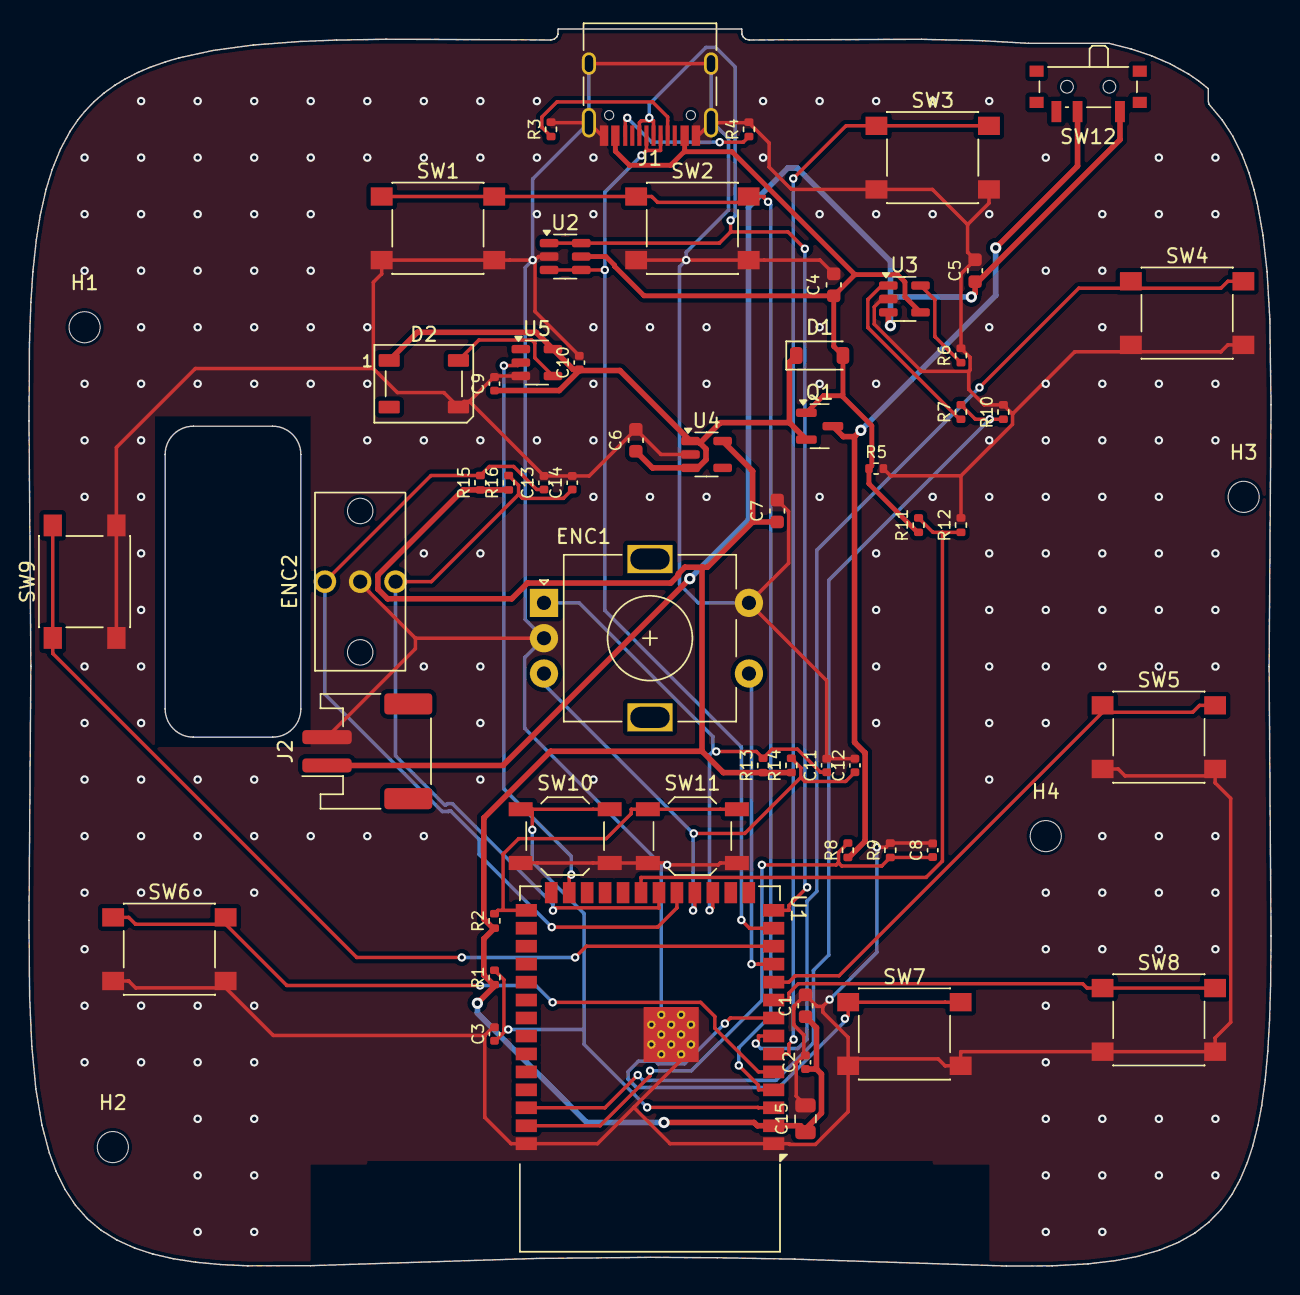
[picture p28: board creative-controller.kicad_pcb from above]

Board: 2 copper layers, 87.9 x 87.5 mm, 59 parts (0 on the bottom side), 32 nets.

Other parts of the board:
H1, H2, H3, H4: MountingHole_2.2mm_M2

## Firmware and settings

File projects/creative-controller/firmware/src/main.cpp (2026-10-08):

// CreativeDial firmware (ESP32-S3) - USB HID keyboard+consumer, BLE HID keyboard,
// 9 keys + 2 EC11 encoders, single/double/long press, "hold-modifier" combos,
// JSON config over USB CDC stored in NVS.
#include <Arduino.h>
#include <USB.h>
#include <USBHIDKeyboard.h>
#include <USBHIDConsumerControl.h>
#include <Preferences.h>
#include <ArduinoJson.h>
#include <BLEDevice.h>
#include <BLEServer.h>
#include <BLEHIDDevice.h>
#include <HIDTypes.h>
#include <BLESecurity.h>
#include "driver/gpio.h"
#include "driver/rtc_io.h"
#include "esp_sleep.h"

#define FW_VERSION "1.1.0"
// ---------------- Pin map (must match pcb/netlist) ----------------
enum { K_TOP, K_SIDE, K_TR1, K_TR2, K_TALL1, K_TALL2, K_BR, K_KNOB, K_WHEEL, NKEYS };
static const uint8_t KEY_PINS[NKEYS] = {4, 5, 6, 7, 15, 16, 17, 18, 8};
static const char *KEY_NAMES[NKEYS] = {"top","side","tr1","tr2","tall1","tall2","br","knob_press","wheel_press"};
#define ENC_KNOB_A 9
#define ENC_KNOB_B 10
#define ENC_WHEEL_A 11
#define ENC_WHEEL_B 12
// EC11E18244A5: 36 detents / 18 pulses -> 2 quadrature transitions per detent (rest at AB=00 and AB=11).
// Mouse-wheel encoder: default also 2; override with config key "wheel_steps" (2 or 4).
#ifndef ENC_STEPS
#define ENC_STEPS 2
#endif
#define LED_PIN 48       // GPIO48 -> U5 SN74LV1T34 (VSYS level) -> WS2812B DIN
#define VBAT_ADC 1       // GPIO1: battery (after power switch) via 100k/100k divider
#define CHG_STAT 2       // GPIO2: MCP73831 STAT via 15k/22k divider: LOW = charging (or no battery), HIGH = charge complete
#define VBUS_SENSE 13    // GPIO13: VBUS via 22k/39k divider, HIGH = USB power present

USBHIDKeyboard Keyboard;
USBHIDConsumerControl Consumer;
Preferences prefs;

// ---------------- Actions ----------------
// action string syntax: "ctrl+z", "ctrl+shift+z", "[", "space", "consumer:volup", "hold:space", "" (none)
struct Action { uint8_t mods; uint8_t key; uint16_t consumer; bool hold; };
static Action parseAction(const char *s) {
  Action a{0,0,0,false};
  String str(s); str.toLowerCase();
  if (str.startsWith("hold:")) { a.hold = true; str = str.substring(5); }
  if (str.startsWith("consumer:")) {
    String c = str.substring(9);
    if (c=="volup") a.consumer=0xE9; else if (c=="voldown") a.consumer=0xEA;
    else if (c=="mute") a.consumer=0xE2; else if (c=="play") a.consumer=0xCD;
    else a.consumer = strtol(c.c_str(), nullptr, 0);
    return a;
  }
  int start = 0;
  while (start <= (int)str.length()) {
    int p = str.indexOf('+', start); if (p == start && p >= 0 && p == (int)str.length()-1) p = -1;
    String t = (p < 0) ? str.substring(start) : str.substring(start, p);
    if (t=="ctrl") a.mods |= 0x01; else if (t=="shift") a.mods |= 0x02;
    else if (t=="alt") a.mods |= 0x04; else if (t=="cmd"||t=="win"||t=="gui") a.mods |= 0x08;
    else if (t.length()==1) { char ch=t[0];
      if (ch>='a'&&ch<='z') a.key=0x04 + (ch-'a'); else if (ch>='1'&&ch<='9') a.key=0x1E + (ch-'1');
      else if (ch=='0') a.key=0x27; else if (ch=='[') a.key=0x2F; else if (ch==']') a.key=0x30;
      else if (ch=='-') a.key=0x2D; else if (ch=='=') a.key=0x2E; else if (ch=='+') a.key=0x2E;
      else if (ch==',') a.key=0x36; else if (ch==';') a.key=0x33; else if (ch=='\'') a.key=0x34; else if (ch=='`') a.key=0x35; else if (ch=='\\') a.key=0x31; else if (ch=='.') a.key=0x37; else if (ch=='/') a.key=0x38; }
    else if (t=="space") a.key=0x2C; else if (t=="enter") a.key=0x28; else if (t=="esc") a.key=0x29;
    else if (t=="tab") a.key=0x2B; else if (t=="del") a.key=0x4C; else if (t=="backspace") a.key=0x2A;
    else if (t=="ins") a.key=0x49; else if (t=="home") a.key=0x4A; else if (t=="end") a.key=0x4D; else if (t=="pgup") a.key=0x4B; else if (t=="pgdn") a.key=0x4E;
    else if (t=="up") a.key=0x52; else if (t=="down") a.key=0x51; else if (t=="left") a.key=0x50; else if (t=="right") a.key=0x4F;
    else if (t.length()>1 && t[0]=='f') { int n=t.substring(1).toInt(); if(n>=1&&n<=12) a.key=0x3A + n - 1; }
    if (p < 0) break; start = p + 1;
  }
  return a;
}

// ---------------- Config ----------------
// events: <key>.single / <key>.double / <key>.long, knob.cw/ccw, wheel.up/down,
// combos: "<holdkey>+knob.cw" etc. (encoder turned while holding a key)
JsonDocument cfg;
static const char *DEFAULT_CFG = R"JSON({"name":"Photoshop","map":{
"top.single":"e","top.double":"ctrl+z","top.long":"hold:space",
"side.single":"ctrl+z","side.double":"ctrl+shift+z",
"tr1.single":"i","tr2.single":"b","tall1.single":"hold:space","tall2.single":"hold:alt",
"br.single":"ctrl+0","br.double":"ctrl+shift+n",
"knob_press.single":"0","wheel_press.single":"u",
"knob.cw":"]","knob.ccw":"[",
"wheel.up":"ctrl+=","wheel.down":"ctrl+-",
"side+knob.cw":"r","side+knob.ccw":"shift+r",
"tr1+knob.cw":".","tr1+knob.ccw":",",
"top+wheel.up":"shift+]","top+wheel.down":"shift+["}})JSON";

void loadCfg() {
  prefs.begin("cdial", true);
  String s = prefs.getString("cfg", DEFAULT_CFG);
  prefs.end();
  if (deserializeJson(cfg, s)) deserializeJson(cfg, DEFAULT_CFG);
}
bool saveCfg(const String &s) {
  JsonDocument tmp; if (deserializeJson(tmp, s)) return false;
  if (!tmp["map"].is<JsonObject>()) return false;
  prefs.begin("cdial", false); prefs.putString("cfg", s); prefs.end();
  cfg = tmp; return true;
}
const char *lookup(const String &ev) { const char *v = cfg["map"][ev] | ""; return v; }

// ---------------- BLE HID ----------------
static const uint8_t REPORT_MAP[] = {
  0x05,0x01,0x09,0x06,0xA1,0x01,0x85,0x01,0x05,0x07,0x19,0xE0,0x29,0xE7,0x15,0x00,0x25,0x01,
  0x75,0x01,0x95,0x08,0x81,0x02,0x95,0x01,0x75,0x08,0x81,0x01,0x95,0x06,0x75,0x08,0x15,0x00,
  0x25,0x65,0x05,0x07,0x19,0x00,0x29,0x65,0x81,0x00,0xC0 };
BLEHIDDevice *hid = nullptr; BLECharacteristic *bleIn = nullptr; volatile bool bleConn = false;
class SrvCB : public BLEServerCallbacks {
  void onConnect(BLEServer *) override { bleConn = true; }
  void onDisconnect(BLEServer *s) override { bleConn = false; s->getAdvertising()->start(); }
};
void bleBegin() {
  BLEDevice::init("CreativeDial");
  BLESecurity *sec = new BLESecurity();            // must be configured BEFORE advertising starts
  sec->setAuthenticationMode(ESP_LE_AUTH_REQ_SC_BOND); sec->setCapability(ESP_IO_CAP_NONE);
  sec->setInitEncryptionKey(ESP_BLE_ENC_KEY_MASK | ESP_BLE_ID_KEY_MASK);
  BLEServer *srv = BLEDevice::createServer(); srv->setCallbacks(new SrvCB());
  hid = new BLEHIDDevice(srv);
  bleIn = hid->inputReport(1);
  hid->manufacturer()->setValue("OpenMaker");
  hid->pnp(0x02, 0x303A, 0x8001, 0x0100);
  hid->hidInfo(0x00, 0x01);
  hid->reportMap((uint8_t *)REPORT_MAP, sizeof(REPORT_MAP));
  hid->startServices();
  hid->setBatteryLevel(100);
  BLEAdvertising *adv = srv->getAdvertising();
  adv->setAppearance(0x03C1); adv->addServiceUUID(hid->hidService()->getUUID()); adv->setScanResponse(true); adv->start();
}
void bleReport(uint8_t mods, uint8_t key) {
  if (!bleConn) return; uint8_t r[8] = {mods,0,key,0,0,0,0,0};
  bleIn->setValue(r, 8); bleIn->notify();
}

// ---------------- Output ----------------
bool usbMounted() { return (bool)USB; }
bool selftest = false;            // hardware bring-up mode: no HID output, print raw events
uint32_t lastActivity = 0;
void sendDown(const Action &a) {
  lastActivity = millis();
  if (selftest) return;
  bool usb = usbMounted();            // don't call TinyUSB when not enumerated (avoids report timeouts on battery)
  if (a.consumer) { if (usb) Consumer.press(a.consumer); return; }   // consumer keys: USB only (BLE map is keyboard-only)
  KeyReport r{}; r.modifiers = a.mods; r.keys[0] = a.key;
  if (usb) Keyboard.sendReport(&r);
  if (!usb || (cfg["ble_when_usb"] | false)) bleReport(a.mods, a.key);   // avoid double keystrokes when both links go to one PC
}
void sendUp(const Action &a) {
  if (selftest) return;
  bool usb = usbMounted();
  if (a.consumer) { if (usb) Consumer.release(); return; }
  if (usb) Keyboard.releaseAll();
  bleReport(0, 0);
}
void tap(const char *s) { if (!*s) return; Action a = parseAction(s); sendDown(a); delay(8); sendUp(a); }

// ---------------- Keys: debounce + single/double/long ----------------
const uint32_t DEBOUNCE=5, DOUBLE_MS=250, LONG_MS=450;
struct KeyState { bool down=false, raw=false; uint32_t tChange=0, tDown=0, tUp=0; uint8_t clicks=0;
  bool usedAsMod=false, longFired=false, holding=false; Action holdAct{}; } ks[NKEYS];

void keyEvent(int k, const char *type) {
  String ev = String(KEY_NAMES[k]) + "." + type; tap(lookup(ev));
  Serial.printf("{\"ev\":\"%s\"}\n", ev.c_str());
}
void scanKeys() {
  uint32_t now = millis();
  for (int k = 0; k < NKEYS; k++) {
    KeyState &s = ks[k]; bool raw = !digitalRead(KEY_PINS[k]);
    if (raw != s.raw) { s.raw = raw; s.tChange = now; }
    if (now - s.tChange >= DEBOUNCE && raw != s.down) {
      s.down = raw; lastActivity = now;
      if (selftest) { Serial.printf("[selftest] key %-11s GPIO%-2d %s\n", KEY_NAMES[k], KEY_PINS[k], raw ? "DOWN" : "up"); continue; }
      if (raw) { // press
        s.tDown = now; s.usedAsMod = false; s.longFired = false;
        String ev = String(KEY_NAMES[k]) + ".single"; const char *m = lookup(ev);
        if (!strncmp(m, "hold:", 5) && s.clicks == 0) { s.holdAct = parseAction(m); sendDown(s.holdAct); s.holding = true; }
      } else { // release
        if (s.holding) { sendUp(s.holdAct); s.holding = false; s.clicks = 0; continue; }
        if (s.usedAsMod || s.longFired) { s.clicks = 0; continue; }
        s.clicks++; s.tUp = now;
        if (s.clicks >= 2) { keyEvent(k, "double"); s.clicks = 0; }
        else if (!*lookup(String(KEY_NAMES[k]) + ".double")) { keyEvent(k, "single"); s.clicks = 0; }
      }
    }
    if (selftest) continue;
    if (s.down && !s.holding && !s.usedAsMod && !s.longFired && now - s.tDown > LONG_MS
        && *lookup(String(KEY_NAMES[k]) + ".long")) {
      String ev = String(KEY_NAMES[k]) + ".long"; const char *m = lookup(ev);
      if (!strncmp(m, "hold:", 5)) { s.holdAct = parseAction(m); sendDown(s.holdAct); s.holding = true; }
      else keyEvent(k, "long");
      s.longFired = true;
    }
    if (!s.down && s.clicks == 1 && now - s.tUp > DOUBLE_MS) { keyEvent(k, "single"); s.clicks = 0; }
  }
}

// ---------------- Encoders (quadrature state machine, ISR) ----------------
static const int8_t QDEC[16] = {0,-1,1,0,1,0,0,-1,-1,0,0,1,0,1,-1,0};
// Table-driven decoder: index = (prev AB << 2) | new AB; invalid (double) transitions = 0 (ignored, bounce-proof).
// A detent is counted only when the encoder arrives in a REST state with |acc| >= steps; acc is cleared at
// every rest state, so contact bounce and missed edges can never accumulate into a phantom step.
struct Enc { uint8_t a,b; volatile uint8_t st; volatile int8_t acc; volatile int32_t det; volatile uint8_t steps; volatile uint32_t edges; } encs[2] =
  {{ENC_KNOB_A,ENC_KNOB_B,0,0,0,ENC_STEPS,0},{ENC_WHEEL_A,ENC_WHEEL_B,0,0,0,ENC_STEPS,0}};
void IRAM_ATTR encIsr(void *arg) {
  Enc *e = (Enc *)arg;
  uint8_t ab = (gpio_get_level((gpio_num_t)e->a) << 1) | gpio_get_level((gpio_num_t)e->b);
  if (ab == (e->st & 3)) return;                       // no change (bounce on the other pin)
  e->st = ((e->st << 2) | ab) & 0x0F; e->edges++;
  e->acc += QDEC[e->st];
  bool rest = (ab == 3) || (e->steps == 2 && ab == 0);
  if (rest) {
    if (e->acc >= (int8_t)e->steps) e->det++; else if (e->acc <= -(int8_t)e->steps) e->det--;
    e->acc = 0;
  } else if (e->acc > 4 || e->acc < -4) e->acc = 0;
}
void handleEnc(int i, const char *name, const char *pos, const char *neg) {
  noInterrupts(); int32_t d = encs[i].det; encs[i].det = 0; interrupts();
  if (d) lastActivity = millis();
  if (selftest) { if (d) Serial.printf("[selftest] enc %s %+d detent(s)  AB=%d%d edges=%u\n", name, (int)d,
                    digitalRead(encs[i].a), digitalRead(encs[i].b), (unsigned)encs[i].edges); return; }
  while (d != 0) {
    const char *dir = d > 0 ? pos : neg; d += d > 0 ? -1 : 1;
    String base = String(name) + "." + dir; String used = base;
    const char *m = "";
    for (int k = 0; k < NKEYS; k++) if (ks[k].down) {           // combo with held key
      String c = String(KEY_NAMES[k]) + "+" + base; const char *mm = lookup(c);
      if (*mm) { m = mm; used = c; ks[k].usedAsMod = true; ks[k].clicks = 0; break; }
    }
    if (!*m) m = lookup(base);
    tap(m); Serial.printf("{\"ev\":\"%s\"}\n", used.c_str());
  }
}

// ---------------- Serial config protocol (JSON lines) ----------------
// {"cmd":"hello"} {"cmd":"get"} {"cmd":"set","config":{...}} {"cmd":"reset"}
// ---------------- Power: battery, USB detect, charge state, deep sleep ----------------
bool usbPower() { return digitalRead(VBUS_SENSE); }
bool charging() { return usbPower() && !digitalRead(CHG_STAT); }
int batteryMv() {                       // 1:2 divider, ADC1 (BLE-safe), 11 dB attenuation, averaged
  uint32_t s = 0; for (int i = 0; i < 16; i++) s += analogReadMilliVolts(VBAT_ADC);
  return (int)(s / 16) * 2;
}
int batteryPct(int mv) {                // simple LiPo curve (resting voltage)
  static const int T[][2] = {{4150,100},{4000,85},{3900,72},{3800,55},{3700,35},{3600,15},{3500,5},{3300,0}};
  if (mv >= T[0][0]) return 100;
  for (int i = 1; i < 8; i++) if (mv >= T[i][0]) return T[i][1] + (mv - T[i][0]) * (T[i-1][1] - T[i][1]) / (T[i-1][0] - T[i][0]);
  return 0;
}
void goToSleep() {                      // wake on ANY key press (all key GPIOs are RTC GPIOs 4..18)
  Serial.println("{\"ev\":\"sleep\"}"); Serial.flush();
  neopixelWrite(LED_PIN, 0, 0, 0);
  uint64_t mask = 0;
  for (int k = 0; k < NKEYS; k++) { gpio_num_t g = (gpio_num_t)KEY_PINS[k]; mask |= 1ULL << g;
    rtc_gpio_init(g); rtc_gpio_set_direction(g, RTC_GPIO_MODE_INPUT_ONLY); rtc_gpio_pullup_en(g); rtc_gpio_pulldown_dis(g); }
  esp_sleep_pd_config(ESP_PD_DOMAIN_RTC_PERIPH, ESP_PD_OPTION_ON);   // keep RTC pull-ups alive
  esp_sleep_enable_ext1_wakeup(mask, ESP_EXT1_WAKEUP_ANY_LOW);
  esp_deep_sleep_start();
}

String line;
void handleLine(const String &l) {
  JsonDocument req; if (deserializeJson(req, l)) { Serial.println("{\"ok\":false,\"err\":\"json\"}"); return; }
  String cmd = req["cmd"] | "";
  if (cmd == "hello") Serial.printf("{\"ok\":true,\"device\":\"CreativeDial\",\"fw\":\"%s\",\"keys\":%d}\n", FW_VERSION, NKEYS);
  else if (cmd == "get") { Serial.print("{\"ok\":true,\"config\":"); serializeJson(cfg, Serial); Serial.println("}"); }
  else if (cmd == "set") { String s; serializeJson(req["config"], s); Serial.println(saveCfg(s) ? "{\"ok\":true}" : "{\"ok\":false,\"err\":\"bad config\"}"); }
  else if (cmd == "reset") { prefs.begin("cdial", false); prefs.clear(); prefs.end(); loadCfg(); Serial.println("{\"ok\":true}"); }
  else if (cmd == "battery") { Serial.printf("{\"ok\":true,\"mv\":%d,\"pct\":%d,\"usb\":%s,\"charging\":%s,\"full\":%s}\n", batteryMv(), batteryPct(batteryMv()),
      usbPower()?"true":"false", charging()?"true":"false", (usbPower() && digitalRead(CHG_STAT))?"true":"false"); }
  else if (cmd == "selftest") { selftest = req["on"] | !selftest; Serial.printf("{\"ok\":true,\"selftest\":%s}\n", selftest?"true":"false"); }
  else if (cmd == "sleep") { goToSleep(); }
  else Serial.println("{\"ok\":false,\"err\":\"unknown cmd\"}");
}

void setup() {
  for (int k = 0; k < NKEYS; k++) { if (rtc_gpio_is_valid_gpio((gpio_num_t)KEY_PINS[k])) rtc_gpio_deinit((gpio_num_t)KEY_PINS[k]);
    pinMode(KEY_PINS[k], INPUT_PULLUP); }
  pinMode(CHG_STAT, INPUT);            // external 15k/22k divider, no pull
  pinMode(VBUS_SENSE, INPUT);          // external 22k/39k divider
  analogSetPinAttenuation(VBAT_ADC, ADC_11db);
  for (auto &e : encs) { pinMode(e.a, INPUT_PULLUP); pinMode(e.b, INPUT_PULLUP);
    e.st = (digitalRead(e.a) << 1) | digitalRead(e.b);
    attachInterruptArg(e.a, encIsr, &e, CHANGE); attachInterruptArg(e.b, encIsr, &e, CHANGE); }
  loadCfg();
  { int ws = cfg["wheel_steps"] | ENC_STEPS; encs[1].steps = (ws == 4) ? 4 : 2; int ks_ = cfg["knob_steps"] | ENC_STEPS; encs[0].steps = (ks_ == 4) ? 4 : 2; }
  delay(20); selftest = !digitalRead(KEY_PINS[K_TOP]);   // hold TOP key while powering on -> self-test mode
  Keyboard.begin(); Consumer.begin();
  USB.productName("CreativeDial"); USB.manufacturerName("OpenMaker"); USB.begin();
  Serial.begin(115200);
  bleBegin();
  lastActivity = millis();
  if (selftest) {                      // LED test: R, G, B, white
    uint32_t t0 = millis(); while (!Serial && millis() - t0 < 3000) delay(10);
    Serial.printf("[selftest] CreativeDial fw %s - press every key / turn encoders; LED R,G,B,W\n", FW_VERSION);
    const uint8_t c[4][3] = {{40,0,0},{0,40,0},{0,0,40},{30,30,30}};
    for (auto &x : c) { neopixelWrite(LED_PIN, x[0], x[1], x[2]); delay(300); }
  }
  neopixelWrite(LED_PIN, 0, 20, 0);
}

void loop() {
  scanKeys();
  handleEnc(0, "knob", "cw", "ccw");
  handleEnc(1, "wheel", "up", "down");
  while (Serial.available()) { char c = Serial.read();
    if (c == '\n') { handleLine(line); line = ""; } else if (line.length() < 4096) line += c; }
  static uint32_t tl = 0, tb = 0; static int lastPct = -1;
  if (millis() - tl > 1000) { tl = millis();
    bool usb = usbPower(), chg = charging(); int mv = batteryMv();
    // LED: orange = charging, green = charged, blue = BLE connected, dim cyan = USB HID only, off on low battery
    if (chg) neopixelWrite(LED_PIN, 30, 8, 0);
    else if (usb && digitalRead(CHG_STAT)) neopixelWrite(LED_PIN, 0, 25, 0);
    else if (mv < 3450 && !usb) neopixelWrite(LED_PIN, 0, 0, 0);
    else if (bleConn) neopixelWrite(LED_PIN, 0, 0, 25);
    else neopixelWrite(LED_PIN, 0, usbMounted() ? 8 : 0, usbMounted() ? 8 : 4);
    if (selftest && millis() - tb > 2000) { tb = millis();
      Serial.printf("[selftest] vbat=%dmV (%d%%) usb=%d chg_stat=%d charging=%d ble=%d usb_hid=%d\n", mv, batteryPct(mv), usb, digitalRead(CHG_STAT), chg, (int)bleConn, (int)usbMounted()); }
    int pct = batteryPct(mv); if (hid && abs(pct - lastPct) >= 2) { hid->setBatteryLevel(pct); lastPct = pct; }
    uint32_t idle = (uint32_t)((cfg["sleep_min"] | 10)) * 60000UL;
    if (!usb && !selftest && idle && millis() - lastActivity > idle) goToSleep();
    static uint8_t lowCnt = 0;           // unprotected-cell safety net: sleep below 3.30 V (5 consecutive readings)
    lowCnt = (!usb && mv > 1000 && mv < 3300) ? lowCnt + 1 : 0;
    if (lowCnt >= 5) { Serial.println("{\"ev\":\"low_battery\"}"); goToSleep(); }
  }
  delay(1);
}

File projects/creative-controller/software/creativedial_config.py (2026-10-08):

#!/usr/bin/env python3
"""CreativeDial 配置工具 / config tool (cross-platform: Windows / macOS / Linux, Python 3.9+, Tkinter + pyserial).
Edit per-application button mappings and push them to the device over USB serial (JSON lines).
CLI:  python creativedial_config.py --list-ports | --export Photoshop out.json | --push Krita [--port COM5] | --selftest
GUI:  python creativedial_config.py
"""
import json, sys, os, time, argparse, copy
try:
    import serial, serial.tools.list_ports
except ImportError:
    serial = None

CONTROLS = [("top","顶部长键"),("side","侧键"),("tr1","右上圆键1"),("tr2","右上圆键2"),("br","右侧圆键"),
            ("tall1","右下长键1"),("tall2","右下长键2"),("knob_press","旋钮按下"),("wheel_press","滚轮按下")]
ROTARY = [("knob.cw","旋钮 顺时针"),("knob.ccw","旋钮 逆时针"),("wheel.up","滚轮 上"),("wheel.down","滚轮 下")]
EVENTS = [("single","单击"),("double","双击"),("long","长按")]

def _base(win=True):
    c = "ctrl" if win else "cmd"
    return c
PROFILES = {
 "Photoshop": {"top.single":"e","top.double":"ctrl+z","top.long":"hold:space","side.single":"ctrl+z","side.double":"ctrl+shift+z",
   "tr1.single":"i","tr2.single":"b","br.single":"ctrl+0","br.double":"ctrl+shift+n","tall1.single":"hold:space","tall2.single":"hold:alt",
   "knob_press.single":"0","wheel_press.single":"u","knob.cw":"]","knob.ccw":"[","wheel.up":"ctrl+=","wheel.down":"ctrl+-",
   "side+knob.cw":"r","side+knob.ccw":"shift+r","tr1+knob.cw":".","tr1+knob.ccw":",","top+wheel.up":"shift+]","top+wheel.down":"shift+["},
 "Clip Studio Paint": {"top.single":"e","side.single":"ctrl+z","side.double":"ctrl+y","tr1.single":"i","tr2.single":"b",
   "br.single":"ctrl+0","br.double":"ctrl+shift+n","tall1.single":"hold:space","tall2.single":"hold:alt","knob_press.single":"tab",
   "wheel_press.single":"u","knob.cw":"]","knob.ccw":"[","wheel.up":"ctrl+=","wheel.down":"ctrl+-","side+knob.cw":"-","side+knob.ccw":"="},
 "Krita": {"top.single":"e","side.single":"ctrl+z","side.double":"ctrl+shift+z","tr1.single":"p","tr2.single":"b","br.single":"5",
   "br.double":"ins","tall1.single":"hold:space","tall2.single":"hold:ctrl","knob_press.single":"tab","wheel_press.single":"u",
   "knob.cw":"]","knob.ccw":"[","wheel.up":"=","wheel.down":"-","side+knob.cw":"ctrl+]","side+knob.ccw":"ctrl+[","tr1+knob.cw":"o","tr1+knob.ccw":"i"},
 "Procreate-like (iPad/BLE, e.g. Procreate via keyboard shortcuts)": {"top.single":"e","side.single":"cmd+z","side.double":"cmd+shift+z",
   "tr2.single":"b","tr1.single":"s","br.single":"cmd+0","knob.cw":"]","knob.ccw":"[","wheel.up":"cmd+=","wheel.down":"cmd+-",
   "tall1.single":"cmd+shift+n","tall2.single":"hold:space"},
}
VALID_TOKENS = set("ctrl shift alt cmd win gui space enter esc tab del backspace up down left right ins home end pgup pgdn".split()) | {f"f{i}" for i in range(1,13)}
def validate_action(a):
    if not a: return True
    a = a.lower()
    if a.startswith("hold:"): a = a[5:]
    if a.startswith("consumer:"): return True
    toks = [t for t in a.replace("++","+=").split("+") if t]
    return all(t in VALID_TOKENS or len(t)==1 for t in toks)

class Device:
    def __init__(self, port=None):
        if serial is None: raise RuntimeError("pip install pyserial")
        self.port = port or self.find()
        if not self.port: raise RuntimeError("未找到设备 / device not found")
        self.s = serial.Serial(self.port, 115200, timeout=1)
    @staticmethod
    def find():
        for p in serial.tools.list_ports.comports():
            if (p.vid == 0x303A) or "CreativeDial" in (p.description or "") + (p.product or ""): return p.device
        return None
    def cmd(self, obj, timeout=2.0):
        self.s.reset_input_buffer(); self.s.write((json.dumps(obj, ensure_ascii=False)+"\n").encode())
        end = time.time()+timeout
        while time.time() < end:
            line = self.s.readline().decode(errors="ignore").strip()
            if line.startswith("{") and '"ok"' in line: return json.loads(line)
        raise TimeoutError("device timeout")
    def push(self, name, mapping): return self.cmd({"cmd":"set","config":{"name":name,"map":mapping}})

def make_config(name):
    m = {k:v for k,v in PROFILES[name].items() if v}
    bad = [f"{k}={v}" for k,v in m.items() if not validate_action(v)]
    if bad: raise ValueError("invalid actions: " + ", ".join(bad))
    return {"name": name, "map": m}

CFG_PATH = os.path.join(os.path.expanduser("~"), ".creativedial_profiles.json")
def load_user():
    if os.path.exists(CFG_PATH):
        try: PROFILES.update(json.load(open(CFG_PATH, encoding="utf-8")))
        except Exception: pass
def save_user(): json.dump(PROFILES, open(CFG_PATH, "w", encoding="utf-8"), ensure_ascii=False, indent=1)
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

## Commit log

2026-10-08 init: grokbot-home — bots, connectors, bootstrap, setup, controller project
    [BOM_JLCPCB.csv, BOM_detailed.csv, _wheel_print.stl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]
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2026-10-08 connectors: 只走 Composio，更新 BOOTSTRAP Step 0 顺序
2026-10-08 scripts: harden secret-scan/secret-crypt/sync for the public repo
    - secret-scan.sh: scan exactly the files git would commit (incl. hidden/untracked),
    plus unpushed commits; block GROKBOT_HOME_PASSPHRASE (word match for short
    passphrases), the plaintext of both secrets/*.enc, ~/.composio_pg_key;
    require secrets/*.enc to carry the GBH1 header; more forbidden filenames.
    Never prints matched values.
    - secret-crypt.py: no tracebacks (they printed derived AES key/iv on failure),
    reject wrong-passphrase garbage, fchmod 600, usage/env checks. Format unchanged.
    - sync.sh: verify remote is ZMGID/grokbot-home and branch is main, scan after
    git add -A (unstage on failure), push explicitly to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
2026-10-08 docs: public-repo bootstrap flow (anonymous clone, passphrase secret-request, decrypt .enc)
    BOOTSTRAP Step 0 rewritten: anonymous clone -> GROKBOT_HOME_PASSPHRASE via
    secret-request -> decrypt secrets/COMPOSIO_API_KEY.enc (fallback .box-current.enc)
    -> install composio-pg from connectors/ + smoke test. gh login moved to new
    Step 1 (push access only). Removed private-repo / inline-launcher / device-code-
    first instructions from README, connectors/README, secrets/README, setup.sh,
    scripts/sync.md, CONTEXT.md and 仓库管家's profile/routine/context.
2026-10-08 bots: 新增 代码工程师，更新 grok-bot 定时任务
2026-10-08 bots: 删除 dr eggbot，新增 搭建运维/邮件秘书/硬件工程师
2026-10-08 context: 写明 Grok Bot 经理分工
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2026-10-08 bots: 补全 grok-bot 定时任务提示词，刷新 bot 说明
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2026-10-08 bots: 仓库管家 CONTEXT 记录每周演练已创建
2026-10-08 bots: grok-bot 新增巡检各 bot 定时任务
2026-10-08 bots: 早晚定时任务移交事务秘书，主 bot 改名小萌
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2026-10-08 bots: 刷新各 bot 说明（经理改称小萌）
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2026-10-09 bots: 同步小枳 description（调研 + 虾皮选品）
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2026-10-09 connectors: 新增 composio-zhimeng（zhimeng63 Gmail）
2026-10-09 connectors: 记录 composio-pg 现有连接，旧 zhimeng63 连接已删
2026-10-09 bots: 同步事务秘书早晚报提示词（zhimeng63 走 composio-zhimeng）
2026-10-10 sync: 飞书 lark-cli、Gmail 来信监听、cloudpotato 提示词原文
2026-10-10 services: 备份 gmail-listener 主程序（webhook 地址改读 env/本地文件）
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2026-10-11 drill 2026-10-11: remove leftover gh login step from setup.sh and gh auth setup-git from sync.sh
2026-10-11 迁移备份补全：box 密钥/飞书/日记加密打包（box-secrets、feishu-cli、daily），新增 pack-bundles.sh；同步脚本按名字匹配 agent、同步 assistant 笔记与 brake-game；扫描与恢复步骤更新
2026-10-11 bots: 仓库管家同步与演练改为加密包必进（用户 10-12 确认）
2026-10-11 sync 2026-10-12 03:20 (1/4): 漂移补齐，profile/routines 里的旧账号 agent id 改为 agent-map.json 的新 id
2026-10-11 sync 2026-10-12 03:20 (2/4): 漂移补齐，旧账号 agent id 改为新 id
2026-10-11 sync 2026-10-12 03:20 (3/4): 漂移补齐，旧账号 agent id 改为新 id
2026-10-11 sync 2026-10-12 03:20 (4/4): 漂移补齐，旧账号 agent id 改为新 id
2026-10-12 sync 2026-10-13 03:35 (1/3): 小萌、事务秘书、仓库管家 CONTEXT 与大局笔记
2026-10-12 sync 2026-10-13 03:35 (2/3): pack-bundles 沿用 secrets.env、sync.md 与连接器状态、环境快照
2026-10-12 sync: 2026-10-13 03:40 Asia/Shanghai（旧号：补 10-12 每日笔记包、迁移清单、仓库管家设定；发现新旧两号同时同步）
2026-10-13 sync: 2026-10-14 03:40 Asia/Shanghai（新号：登记商品调研、连接器补 Monid、raw 快照改回新号设定）
2026-10-14 sync: 2026-10-15 03:27 Asia/Shanghai（修复 stash 冲突标记；去掉公开仓金额与第三方邮箱）
2026-10-15 bots: agent-map 同时记录两个账号的 id（本号按小萌巡检校正）
2026-10-15 workspace/assistant/big-picture: 公开副本去掉第三方邮箱与退款单号（与 notes 版一致）
2026-10-15 sync: 2026-10-16 03:35 修正（恢复去敏 big-picture 与完整 daily 包；sync.sh 不再 git push）
2026-10-16 sync: 2026-10-17 03:20 Asia/Shanghai（旧号：big-picture 10-16 去敏版、小萌 10-16 要点、连接器 Finance）
2026-10-17 sync: 2026-10-18 03:2x Asia/Shanghai（新号：小萌 10-17 踏板铰链 Φ10 建议；漂移检查无差异）
2026-10-18 drill: 2026-10-18 换号演练修正（BOOTSTRAP 去掉 gh 重登步骤、技能与小萌例程清单对齐；sync.md 推送说明；仓库管家演练提示词按线上原文）
2026-10-18 drill: 2026-10-18 旧号演练补充（README 技能一栏改为现有 tiktok）
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2026-10-18 sync: 2026-10-19 03:2x Asia/Shanghai（旧号：仓库管家 routines.md 本号每日同步提示词说明与抄送 id 改正；其余无变化，加密包与 big-picture 保留仓库版）
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2026-10-19 sync: 2026-10-19 11:3x Asia/Shanghai（新号：登记电子工程师 profile/CONTEXT/routines；index.json 加两个新 bot 与「AI陪伴机器人」群，更新测试/代码/硬件工程师角色）
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2026-10-19 sync: 2026-10-19 11:3x Asia/Shanghai（新号：BOOTSTRAP bot 清单加结构、电子工程师与「AI陪伴机器人」群；根 CONTEXT 分工段更新）
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2026-10-19 sync: 2026-10-19 11:4x Asia/Shanghai（新号：测试/代码/硬件工程师 description 按线上原文（去掉脚踏板）；小萌 CONTEXT 记踏板废弃）
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2026-10-19 sync: 2026-10-20 03:2x Asia/Shanghai（新号：结构/电子/代码/测试/硬件工程师、商品调研、事务秘书、小萌 CONTEXT 记 10-19 下午进展；根 CONTEXT 记键盘第一版收尾与机器人 Ø70 定案；big-picture 新号补充更新并去敏；daily 包合并加 10-19；raw 快照补结构、电子工程师）
2026-10-19 sync: 2026-10-20 03:3x Asia/Shanghai（旧号：小萌 big-picture 换成 10-19 去敏版（保留新号补充）、CONTEXT 记旧号 10-19 晚报；daily 包加入旧号 10-19，新号版改名 2026-10-19.新号.md）
2026-10-20 sync: 2026-10-20 11:2x Asia/Shanghai（新号：测试工程师 description 按线上原文，陪伴机器人定版 BE70r3、键盘 v5.8 B；CONTEXT 记一条）
2026-10-20 sync: 2026-10-21 03:2x Asia/Shanghai（旧号：小萌 big-picture 换成 10-20 去敏版（保留新号补充）、CONTEXT 记旧号 10-20 晚报；daily 包加入旧号 10-20）
2026-10-20 sync: 2026-10-21 03:3x Asia/Shanghai（新号：小萌/代码工程师/商品调研/结构/电子工程师/事务秘书/仓库管家 CONTEXT 记 10-20 进展；根 CONTEXT 记机器人暂停采购；big-picture 新号补充换成 10-20 去敏版；测试工程师 raw 快照）
2026-10-21 sync: 2026-10-22 03:2x Asia/Shanghai（旧号：小萌 big-picture 换成 10-21 去敏版（保留新号补充）、CONTEXT 记旧号 10-21 晚报；daily 包加入旧号 10-21）
2026-10-22 sync: 2026-10-22 15:2x Asia/Shanghai（新号补跑：big-picture 新号补充换成 10-21 去敏版；小萌 CONTEXT 记新号 10-21 晚报；daily 包加入新号 10-20、10-21（.新号.md）；仓库管家 CONTEXT 记补跑）
2026-10-22 sync: 2026-10-23 03:2x Asia/Shanghai（旧号：小萌 CONTEXT 记旧号 10-22 早报；daily 包加入旧号 10-22；仓库管家 CONTEXT 记本盒重建与 composio venv 修复）
2026-10-22 sync: 2026-10-23 03:3x Asia/Shanghai（新号：big-picture 新号补充换成 10-22 去敏版；小萌 CONTEXT 记新号 10-22 晚报；daily 包加入新号 10-22（.新号.md）；仓库管家 CONTEXT 记同步）
2026-10-23 sync: 2026-10-24 03:2x Asia/Shanghai（旧号：小萌 CONTEXT 记旧号 10-23 晚报；big-picture 换成 10-23 去敏版（保留新号补充）；daily 包加入旧号 10-23；仓库管家 CONTEXT 记同步）
2026-10-23 sync: 2026-10-24 03:2x Asia/Shanghai（新号：big-picture 新号补充换成 10-23 去敏版；小萌 CONTEXT 记新号 10-23 晚报；仓库管家 CONTEXT 记同步）
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2026-10-26 sync: 2026-10-27 03:2x Asia/Shanghai（旧号：big-picture 换成 10-26 去敏版（保留新号补充）；小萌 CONTEXT 记旧号 10-26 晚报；daily 包加入旧号 10-26；仓库管家 CONTEXT 记同步）
2026-10-27 sync: 2026-10-28 03:2x Asia/Shanghai（旧号：big-picture 换成 10-27 去敏版（保留新号补充）；小萌 CONTEXT 记旧号 10-27 晚报；daily 包加入旧号 10-27；仓库管家 CONTEXT 记同步）
